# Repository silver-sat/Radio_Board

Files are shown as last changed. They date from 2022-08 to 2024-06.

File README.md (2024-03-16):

# Radio_Board
SilverSat Limited – https://silversat.org
SilverSat logo

Unassembled front radio board photograph
Radio board front view

**SilverSat is currently transistioning the repository to KiCad 8.0. These
updated files are incompatible with older versions.**

SilverSat's Radio Board is our custom-designed Arduino®-compatible prototype
satellite data transceiver and internet gateway for 430-450 MHz.

This repository contains the board design in KiCad 6.0 with relevant design
files and images.

# Setup
1. If you haven't already done so, download and install KiCad 6.0 from their
website, https://www.kicad.org/download/. Depending on your system and Internet
connection, than may take several hours.
2. On the top right of the repsitory's main page, click “Code” to select
download options. On all operating systems, you can download and extract a ZIP
archive to your perrfered folder. Alternatively, you can use one of the many
free Git access programs available from the Internet. Here are instructions for
a few common programs.
   * On Windows and Mac, you can download and install GitHub Desktop
   (https://desktop.github.com/) to access and manage Git repositories. See
   https://docs.github.com/en/desktop/contributing-and-collaborating-using-github-desktop/adding-and-cloning-repositories/cloning-a-repository-from-github-to-github-des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 for details.
   * There are also many command line interfaces available. For example, GitHub
    offers `gh` which can be downloaded from their repository
    (https://github.com/cli/cli). Once you install the client, navigate to your
    perferred folder and run the command given by our repository's Code tab.
   * On Unix and Linux, many software repositories offer `git` as an
   alternative to `gh`. You can download and install `git` from your package
   manager.
     - Debian-based Linux: `sudo apt install git`
     - RedHat Linux or derivatives: `sudo yum install git`
     - macOS (using [Homebrew](https://github.com/Homebrew/brew)):
     `brew install git`
   * For other programs, see their associated documentation for directions.
3. Download and install SilverSat's KiCad Library
(https://github.com/silver-sat/kicad_library). Installation instructions are
given on the library's README.md.
   - It is possible to skip this step, but some parts (such as the TCXO) may
   fail to load.¹
5. Enter the project folder and open SilverSat_Comms.kicad_pro. KiCad will show
 options to edit the schematic or PCB.

# Software
See SilverSat's Radio Software repository
(https://github.com/silver-sat/Radio_Software)

## Known Issues
- KiCad 6, required by our project, is not supported on Windows 7 or earlier
releases. We have not yet tested Windows 8.
- It is possible that Windows users of KiCad versions 6.0.0 to 6.0.4 may
experience issues with sudden component changes using using the Edit Schematic
Fields tool.
- When adding, removing, or moving components in the schematic, importing the
changes into the PCB may cause components to change places. Although they can
be moved back in place, it is easier to preserve annotations (or, if you add a
component, manually annnotate it).
- Due to the large size of this repository, it may download slowly depending on
your connection speed. On a 5 Mb/s connection, this time is approximately 13
minutes. To reduce download time, clone in headless mode `(git clone ... -d 1
...)`

# Warnings
This board was designed for the
[OshPark 4-Layer PCB Service](https://docs.oshpark.com/services/four-layer/).
Using another board type or service will require adjustments to the RF
amplifier lines and may require other appropriate compensations.

# Notes
¹ We have not yet tested whether this will work, but we presume based on past
experience that the resulting error can be ignored.

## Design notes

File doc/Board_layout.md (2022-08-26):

Radio Board Layout
---
SilverSat Ltd. (https://silversat.org)
2022-08-20

During the design process, the board was layed out in sections to ease part placement, and it could be referenced to during testing. In this document, we present the board sections and state their meanings.

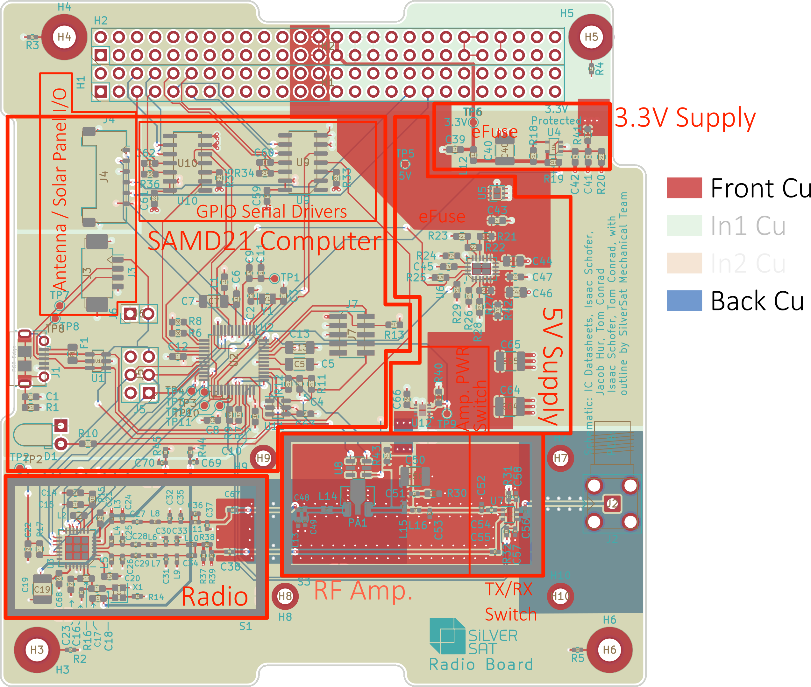
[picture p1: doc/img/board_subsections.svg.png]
Board sections diagram


_Figure 1: Board layout_

# SAMD21
The SAMD21 is an approximately 48 MHz SAMD21-based processor inspired by the [Adafruit Metro M0 Express](https://www.adafruit.com/product/3505). It is compatible with the Metro and the Arduino Zero with modified serial pin definitions (TBD: Add).
## Pinouts

### H1 & H2
See New Pin Assignments.pdf

### J1
USB Mini B (limited to 0.3 A)

### J3
Modified USB (for solar panel data as a backup for other boards)

### J4
[Endurosat Antenna Board](https://www.endurosat.com/cubesat-store/cubesat-antennas/uhf-antenna/) data connector

### J5
| AX5043 SPI MISO  | 3.3 V |
| --- |--- |
| AX5043 SPI SCK | AX5043 SPI MOSI  |
| RESET | GND |

### J6
|  GND  | RESET |
| ----- | ----- |

### J7 (SWD Header)
| 3.3 V | RX LED SWDIO |
| --- | --- |
| GND | SWCLK |
| GND | NC |
| NC | NC |
| NC | RESET |

### Test Points
| ◉ TP3 | ◉ TP4 | ◉ TP10 | ◉ TP11 |
| --- | --- | --- | --- |
| AX5043 SPI DATA | AX5043 SPI DCLK | TxD2 | RxD2 |

# Radio
The radio is a clone of the OnSemi ADD5043-433-GEVK (./Datasheets/ADD5043-433-2-GEVK SCHEMATIC.PDF) AX5043 test board schematic, placed in a two-piece RF shield. See img/ for chip selection.

## Attenuator
The receive line (closest to the SAMD21) has a pi-attenuator network near the exposed ground test point. The BOM includes parts for 0 dB attenuation, but other values can be calculated using KiCad's PCB Calculator. Common values are also given in the schematic.

# Power Amplifier & TX/RX Switch
This circuit, based on a HMC452ST89, increases the transmit power from the radio from 16 dBm to 30 dBm.

To allow one connector to serve as transmit and receive, an TX/RX switch has been included.

# Serial Drivers
Converts differential serial lines from Avionics and Payload to UART for the SAMD21.

# Power Supplies
The board includes two power supplies (5V and 3.3V) which take DC power from SilverSat's Power board and applies latch-up protection and e-fuses.
## 5V
The five volt supply is almost entirely contained on the top layer, and powers the RF amplifier. In addition to the above, it includes and electronic power switch to power off the amplifier when it is not in use.

## 3.3V
The output connects to a power plane on the In_2 copper layer, powering the SAMD21, ADD5043 and TX/RX switch.

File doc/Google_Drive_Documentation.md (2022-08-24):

# Preliminary Design on Google® Drive

All preliminary design files for the AX5043 are available on SilverSat's Google Drive at the following link. It also includes related ground station design.

https://drive.google.com/drive/folders/1SJQHO7lgZGwX5b4s1ShD_AfbKK2ey7EL?usp=sharing

In addition, SilverSat has published one of its early KISS over AX.25 transceivers for Arduino Megas and HopeRF RFM69s on it own GitHub repository.

https://github.com/silver-sat/ipoverradio

<sub>*"Google" is a registered trademark of Google, Inc., Mountain View, California, United States, a subsidiary of Alphabet, Inc.*</sub>

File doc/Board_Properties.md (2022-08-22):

![Figure 1: A diagram of the board properties. Board Dimensions: 90.1700 by 95.8850 millimeters. Thickness: 69.68 mils, 1.770 millimeters. Board Characteristics. Copper Layer Count: 4. Min track/spacing: 5 mils, 0.1270 millimeters. Copper Finish: E N I G. Casellated pads: No. Edge card connectors: No. Min hole diameter: 10.00 mils, 0.2540 millimeters. Impedance Control: No. Plated Board Edge: No. Board Materials: See OshPark 4-Layer Board Service datasheet (https://docs.oshpark.com/services/four-layer/)](./img/SilverSat_Comms-User_Drawings.svg.png)

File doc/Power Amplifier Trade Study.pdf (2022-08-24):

6

| Output power (dBm) | Supply Voltage | Supply current | Package | Cost/ availability | Evaluation board | Efficiency
HMC452ST89 from Analog Devices | 31 | 5 | 510 | SOT-89 | 15.22$ on analog website, in stock | Yes, but unavailable on DigiKey | 1.25/2.55 49.7%
MMZ09332B from NXP | 32.8 | 5 | 110 mA | QFN 12 pin 3mm | In stock, 8.63 on mouser | Couldn’t find | Datasheet says “45.5 @ 5 V 53.7 @ 3.6 V”
TQP7M9105 from Qorvo | 30 | 5 | 450 mA | SOT-89 | 12.85, 1 in stock on Qorvo website, 1 on RFMW.com | Yes | 44.444...%

efficiency =

10

−3
10

dBm
10

( ( ))

V
in

I
in

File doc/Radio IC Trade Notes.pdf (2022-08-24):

Figures of Merit

Radio IC | Well-Supported API | MTU Size | Support VHF and UHF Bands Path for Beacon | Available Now Test Boards Available | Heritage | Separate Tx Out Pin Switch Control Sensitivity | Green cells | Yellow cells | Red cells
Requirement/Criteria -> | | 255/256 preferred | 145.8 to 146 MHz, 432.125 to
| | | 433 MHz, and 435 to 438 MHz
| | | coverage | Some means to approximate CW | Yes | Yes

Not sure why this is
a requirement, just
need the control line
and 2 switches - tkc Yes

(looking −100dBm @ 10⁻³
BER, 9600 baud)
RFM22 | Supported by Radiohead | 64 bytes / Direct Mode | 240-930 MHz | CW Support in Direct Mode | No | No
| | | | | | $50Sat (?) and T-LogoQube (?) | Yes on base IC Yes on base IC | See graph on page 26 of datasheet 4 2 3
Supports OOK; modulation of packet length to create CW Supports OOK; modulation of packet length to create CW Supports OOK; modulation of packet length to create CW | SX1231HIMLT RT has 18,890 in stock at DigiKey As of 2021-12-29 21:06 UTC, there were 4,000 available on DigiKey. | Yes, but they are out of stock on DigiKey. We do have RFM69s, but the chips on those are labeled “RF69” so I MinXSS (https://earth.esa. cannot confirm that they int/web/eoportal/satellite-are SX1231 boards. missions/m/minxss) | No | Yes | −112.7143 dBm linearly interpolated,unspecified BER or PER, 9600 baud 3 4 2
2 generic boards in stock at SilverSat Limited | Likely no satellite heritage, but it is recommended by a master's thesis https: //oaktrust.library.tamu. edu/bitstream/handle/1969. 1/ETD-TAMU-2011-12-10387/GRAVES-THESIS.pdf | No | Yes [1] | Multiple receiver modes available; see page 8 of data sheet 3 3 3
As of 2021-12-29 20:28 UTC, there were 211 available on DigiKey. This product is discontinued, but parts are available | 2 generic boards in stock at SilverSat Limited | Likely no satellite heritage, but it is recommended by a master's thesis https: //oaktrust.library.tamu. edu/bitstream/handle/1969. 1/ETD-TAMU-2011-12-10387/GRAVES-THESIS.pdf | No | “Positive” and “Negative” output from LNA | Multiple receiver modes available; see page 8 of data sheet 2 4 3
AX5043 | Official API for AX852, portable to Arduino | As of 2021-12-19 22:15 UTC, there were “Wire mode” available; MCW may 5,920 available In stock at SilverSat 256 bytes, more with options 27MHz ~ 1.05GHz be possible in FM mode at DigiKey Limited | Oresat | Yes Yes | −117 at h = 0.66 to −113 dBm at h = 8, 10 kbaud, FSK, 10⁻³ BER, no FEC, 433 or 868 MHz 6 2 1
AX5243 | In-development https://github.com/jgromes/RadioLib | As of 2021-12-19 22:15 UTC, there were 40,880 “Wire mode” available; MCW may available at 256 bytes, more with options 27MHz ~ 1.05GHz be possible in FM mode DigiKey | Yes, but it is not in stock Seems to be similar to at DigiKey AX5043, used on Oresat | No No | −117 at h = 0.66 to −113 dBm at h = 8, 10 kbaud, FSK, 10⁻³ BER, no FEC, 433 or 868 MHz 5 4 0
SX1276IMLTRT; SX1277IMLTRT; SX1278IMLTRT; SX1279IMLTRT AX8052F143 AX5045-1-TW30 SX1236IMLTRT | True. https://github.com/jgromes/RadioLib and https://github.com/StuartsProjects/SX12XX-LoRa | 64 bytes | DigiKey has 5,983 of SX1279IMLTRT on 2021-12-30 137MHz ~ 1.02GHz Modulating packet length MCW 01:27 UTC | No None | Yes Yes | 6 2 2
No No | 256 bytes, more with options 27MHz ~ 1.05GHz 256 bytes, more with options 60MHz ~ 1.05GHz | Raw mode? Can modulate packet length Raw mode? Can modulate packet length | 4,160 In Stock on DigiKey As of 2021-12-30 02:01 UTC, there were 2988 available on DigiKey. | Available at 868 MHz on DigiKey, sale of 70 cm band boards is unknown None Yes, but at 815 MHz with limited supply None | Unclear; Unclear; possibly possibly through GPIO through GPIO | 3 3 3
| | | | | Separate Separate differential differential dual dual TX/RX pins TX/RX pins | 5 1 3
Supported by https://github.com/StuartsProjects/SX12XX-LoRa | 64 bytes | As of 2021-12-30 15:17 UTC, there were 2,844 available 137MHz ~ 1.02GHz Modulating packet length MCW on DigiKey. | No None | Different TX and RX pins Yes | 6 1 2
ADF7020-1BCPZ-RLTR-ND | Not for Arduino. https://forum.arduino.cc/t/low-power-rf-transceiver-433mhz-13dbm/384396 There may be an official library for C on the Buffer exists for some modulation Analog Devices product page. types, but size is not specified. | 80MHz ~ 650MHz | Supports OOK; modulation of packet length to create CW; and possible default direct mode depending on modulation | As of 2021-12-30 15:40 UTC, there were 1,972 available on DigiKey. | MCubed-2 / COVE https: //directory.eoportal. Yes, but it is not in stock org/web/eoportal/satellite-at DigiKey. All generic missions/content/-ADF7020 /article/mcubed-2-mission | Yes | No | 4 3 2

SX1231

Supported by https://github.com/jgromes/RadioLib and
https://github.
com/StuartsProjects/SX12XX-LoRa

66 bytes, option for unlimited
packet length (possible “direct
mode”) | VHF to 290 MHz

Texas Insturments
CC1101TRHBRG4Q1

True. https://github.
com/pkarsy/CC1101_RF | 64 bytes

310MHz ~ 348MHz, 420MHz ~
450MHz, 779MHz ~ 928MHz

Texas Insturments
CC1101QRHBRG4Q1

True. https://github.
com/pkarsy/CC1101_RF | 64 bytes

310MHz ~ 348MHz, 420MHz ~
450MHz, 779MHz ~ 928MHz

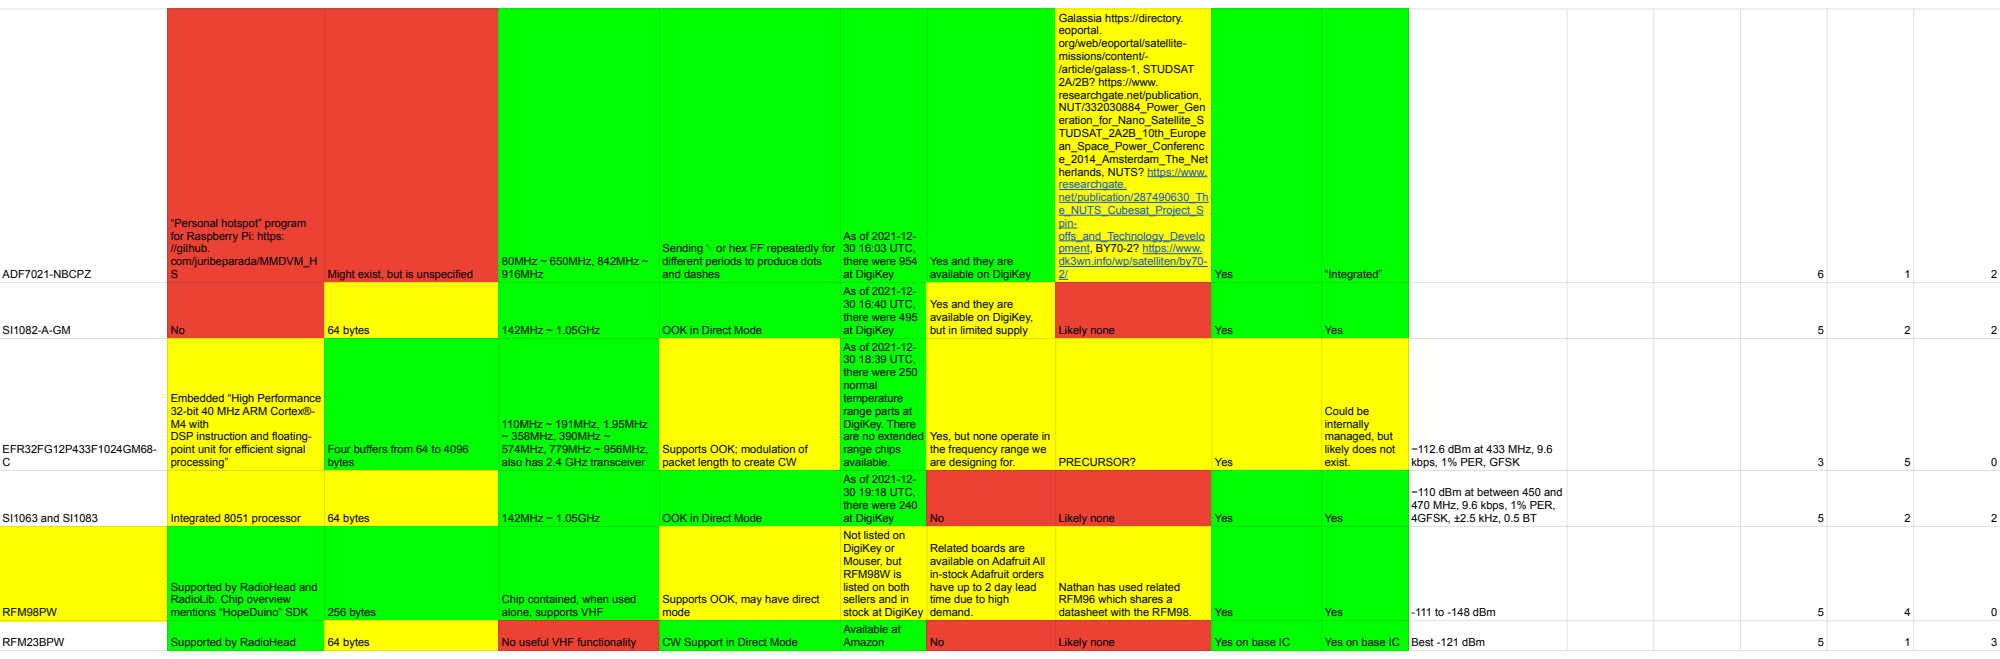
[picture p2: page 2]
ADF7021-NBCPZ; com/juribeparada/MMDVM_H S; Might exist, but is unspecified; 80MHz ~ 650MHz, 842MHz ~ 916MHz; As of 2021-12- 30 16:03 UTC, there were 954 at DigiKey; Yes; “Integrated”; 64 bytes; 142MHz ~ 1.05GHz; OOK in Direct Mode; As of 2021-12- 30 16:40 UTC, there were 495 at DigiKey; but in limited supply; Likely none

Galassia https://directory.
eoportal.
org/web/eoportal/satellite-
missions/content/-
/article/galass-1, STUDSAT
2A/2B? https://www.
researchgate.net/publication,
NUT/332030884_Power_Gen
eration_for_Nano_Satellite_S
TUDSAT_2A2B_10th_Europe
an_Space_Power_Conferenc
e_2014_Amsterdam_The_Net
herlands, NUTS? https://www.
researchgate.
net/publication/287490630_Th
e_NUTS_Cubesat_Project_S
pin-
offs_and_Technology_Develo
pment, BY70-2? https://www.
dk3wn.info/wp/satelliten/by70-

“Personal hotspot” program
for Raspberry Pi: https:
//github.

Sending
different periods to produce dots
and dashes

␀ or hex FF repeatedly for

Yes and they are
available on DigiKey

available on DigiKey,

EFR32FG12P433F1024GM68- C | Embedded “High Performance 32-bit 40 MHz ARM Cortex®-M4 with DSP instruction and floating-point unit for efficient signal processing” | 110MHz ~ 191MHz, 1.95MHz ~ 358MHz, 390MHz ~ Four buffers from 64 to 4096 574MHz, 779MHz ~ 956MHz, bytes also has 2.4 GHz transceiver | Supports OOK; modulation of packet length to create CW | As of 2021-12-30 18:39 UTC, there were 250 normal temperature range parts at DigiKey. There are no extended range chips available. | Could be internally Yes, but none operate in managed, but the frequency range we likely does not are designing for. PRECURSOR? Yes exist. | −112.6 dBm at 433 MHz, 9.6 kbps, 1% PER, GFSK 3 5 0

SI1063 and SI1083 | Integrated 8051 processor 64 bytes | As of 2021-12-30 19:18 UTC, there were 240 142MHz ~ 1.05GHz OOK in Direct Mode at DigiKey | No Likely none | Yes | −110 dBm at between 450 and 470 MHz, 9.6 kbps, 1% PER, 4GFSK, ±2.5 kHz, 0.5 BT 5 2 2

RFM98PW | Supported by RadioHead and RadioLib. Chip overview Chip contained, when used mentions “HopeDuino” SDK 256 bytes alone, supports VHF | Not listed on DigiKey or Related boards are Mouser, but available on Adafruit All in-stock Adafruit orders RFM98W is listed on both have up to 2 day lead Nathan has used related Supports OOK, may have direct sellers and in time due to high RFM96 which shares a mode stock at DigiKey demand. datasheet with the RFM98. | Yes | -111 to -148 dBm 5 4 0

RFM23BPW | Supported by RadioHead | 64 bytes | No useful VHF functionality | Available at CW Support in Direct Mode Amazon | No Likely none | Yes on base IC | Best -121 dBm 5 1 3

[1] There's actually a way to program the registers to get a switch control on GDOx. There's also a companion chip for it the CC1190 (but wrong frequency band) that adds PA & LNA

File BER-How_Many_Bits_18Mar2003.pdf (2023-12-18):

BIT ERROR RATIO TESTING:
HOW MANY BITS ARE ENOUGH?

Andy Baldman
UNH InterOperability Lab
March 18, 2003

Abstract:

The purpose of this article is to discuss the concept of Bit Error Ratio testing, and will explain, using a minimum amount of math, the answer to a fairly common question:

“How many bits do I need to send in order to verify that a device exceeds a given BER?”
The analysis will provide the same answer as the more formal approach¹
, which
employs the statistical concepts of Confidence Intervals and Hypothesis Testing, however this analysis is designed to provide an intuitive, easy-to-understand explanation that does not require the reader to have any prior knowledge of statistics or probability.

Introduction:

The concept of the Bit Error Ratio (BER²
) is ubiquitous in the communications industry. It is commonly used as the fundamental measure of performance for digital communication systems. The BER can be thought of as the average number of errors that would occur in a sequence of n bits. Consequently, when n is equal to 1, we can think of the BER as the probability that any given bit will be received in error. Formally, the BER is expressed in terms of the following ratio:

1 error
n bits transmitted

So, if a device’s specified BER is 1/n, we can expect to see, on average, 1 bit error for every n bits sent. The fact that the BER is defined as an average quantity is an important fact, for reasons that will soon become apparent.

While the definition of BER may be fairly straightforward, verifying that a device meets or exceeds a certain BER is not as simple. If a device’s BER claims to be 1/n, and we send n bits and see one error, can we say that the BER is 1/n? What happens if we see no errors? What if there are multiple errors? What if we see a different number of errors each time we repeat the test? Is there anything that we can say for certain?

Well, the answer is… maybe. It depends on the circumstances. To begin with, let’s start with what we do know: If at least one error is seen, we can say with 100 percent certainty that the BER is definitely not zero. Also, as long as at least one bit was successfully received, we can additionally state that the BER is most definitely less than
1. We’ve already narrowed it down to somewhere between 0 and 1! How difficult can this be, right?

Obviously, while these observations are technically correct, they really don’t help us that much. We need a better way of analyzing this problem, so we’ll do what all good engineers and scientists do: we’ll make a model of the system, and try to infer answers from the model, based on the characteristics of the model and the assumptions we make about its behavior.

Before we do that though, allow me to make one statement, (which happens to be correct, as we will see by the end of this article.)

“In reality, if a device’s BER is 1/n and n bits are sent, we can actually expect to see 0 errors during those n bits approximately 35 percent of the time.”

“35 percent? Are you crazy? That makes no sense!”, I hear you cry.

Yes, it sounds odd. However, it’s actually not that difficult to understand why this is the case, and to see where this number comes from. To do this however, we’ll need to explain a couple of basic concepts from the study of Probability. Don’t panic, it’s nothing complicated. In fact it’s as simple as flipping a coin…

Bernoulli Trials: Heads or Tails?

If you flip a coin, everyone knows the probability of getting either heads or tails is 50/50 (as long as the coin isn’t rigged in some way, of course.) However, it wouldn’t be terribly shocking to flip a coin 3 times and get 3 heads or 3 tails in a row. Even though the chance of getting heads for any particular flip is 50%, it is entirely possible to get any number of heads or tails for any given number of consecutive flips. Although these events are less likely to happen than usual, they do happen, and it’s not too hard to say something about how often they happen, using some basic assumptions.

In the study of Probability, one of the simplest and most important concepts is known as the “Bernoulli Trial”. Basically, this is just a fancy term to describe flipping a coin. In general, a “Bernoulli Process” is comprised of a series of Bernoulli Trials, where the trials are described by the following 3 characteristics:

1) Each “trial” has two possible outcomes, generically called success and failure.
2) The trials are independent. Intuitively, this means that the outcome of one trial has no influence over the outcome of any other trial.
3) For each trial, the probability of success (however it may be defined) is p, where p is some value between 0 and 1. The probability of a failure (defined as the only other alternative outcome to success) is 1-p.

That being said, let’s go back to coin flipping. Although a normal coin may have a 50/50 chance of landing heads up for any given flip (technically called a fair coin), we know that it’s fairly easy to flip a coin twice and get 2 heads, or 3 times and get 3 heads. In reality, for the case of three flips, we see that there are only 8 possible combinations that can occur (H = heads, T = tails):

H-H-H
H-H-T
H-T-H
H-T-T
T-H-H
T-H-T
T-T-H
T-T-T

Because there are only 8 possible outcomes, and the chances of getting a head are the same as getting a tail, then the chances of any one specific combination of outcomes occurring is always 1 in 8, or .125. Note that we can also get this value using the probability for each coin flip. If the probability of getting one head is .5, then the probability of getting 3 heads in a row is just:

.5 *.5 * .5 = .125 (or 1/8)

Again, because the chances of getting a head are the same as getting a tail, the probability of any particular one of the eight combinations above is always just .5*.5*.5 = .125.

“But how can they all be the same? Shouldn’t the chances of getting all heads be smaller?”

Yes, and it is, which is easier to see if we look at the list of the 8 possible outcomes in a different way. If I ask the question, “What are the chances of getting all heads for three consecutive flips?” there is only one way to do it, and so the answer is 1/8. However, if I change the wording of the question to ask, “What are the chances of getting only one head in three flips?” we see that the answer is now 3/8. This is because here (unlike the all-heads case) there are now three different ways of getting what we want (HTT, THT, TTH) and each one has a 1 in 8 chance of occurring. Thus, we can add the probabilities together. To better see why the probabilities add, just look at the table of the 8 possible outcomes for 3 flips. The chances of getting only one head makes up three of the eight total combinations, thus you’re three times more likely to get one of those combinations than you are to get the single case of all three heads.

Note that we can ask other questions here, too. I could word the question to ask, “What is the probability of getting up to 2 heads?” In this case, we need to find the sum of the following:

| Possible | Total
Condition | Outcomes | Probability
The probability of getting 0 heads: TTT | = 1/8
plus, The probability of getting 1 head: | HTT, THT, TTH | = 3/8
plus, The probability of getting 2 heads: HHT, HTH, THH | = 3/8
| | 7/8

Observe that in order to get this result, we had to find the sum of the probabilities for 7 out of the 8 possible outcomes. Since for any experiment, the sum for all of the total possible outcomes must always add up to 1, in this case we also could have found the answer by computing 1 minus the probability of not getting up to 2 heads, which is simply 1 minus the probability of getting all three tails, which is 1 - 1/8 = 7/8. Simple!

“OK, so what does all of this have to do with BER testing?”

We can use this same basic coin-flipping model to describe our process of sending and receiving bits, with a few minor tweaks. First, we have to realize that we will no longer have a fair coin. If we equate a “tail” with a bit error, then we now have a coin that flips heads almost all of the time, and which flips tails according to the BER (say 1 tail in 100 flips for a BER of 1E-2 for example.) The other thing to realize is that the math gets a little more complicated. To see why, suppose I ask the question, “What is the total probability of getting exactly 3 tails in 100 flips?” To find this probability, one of the things we need to know is the number of ways we can get 3 tails in 100 flips, e.g.,

TTT + 97 Heads
THTT + 96 Heads
TTHT + 96 Heads
HTTT + 96 Heads
HHTTT + 95 Heads
Etc…

It doesn’t take long to see that the number of combinations quickly gets far too cumbersome to determine by hand. Have no fear, though, since there exists an easy formula that can provide the value much easier.

ENTER THE BINOMIAL COEFFICIENT!

Without getting into the history of it, someone along the way figured out a handy little formula that tells you the total possible number of combinations that k specific outcomes can occur out of a total of n trials. It is sometimes referred to as “n-choose-k”, and is technically called the Binomial Coefficient. The formula is as follows:

n!
C(n,k) = | -------------- | [EQ. 1]
| k! * (n-k)!

Plugging in some real values to this formula, if we want to know the number of combinations for getting 2 heads in a total of 3 flips, we get:

3! | 6
------------ = --------- = 3 possible ways. (HHT, THH, and HTH)
2! * (3-2)! 2 * 1

Similarly, for 2 heads in 4 flips, we get:

4! | 24
------------ = --------- = 6 possible ways. (HHTT, TTHH, THTH,
2! * (4-2)! | 2 * 2 | HTHT, THHT, HTTH)

We can easily see the power of this formula, as it allows us to quickly find the number of combinations for examples that would be far too complicated to figure out by hand. For example, take 12 heads in 50 flips:

50!
------------------- = 121,399,651,100 possible combinations!
12! * (50-12)!

Granted, there is still a problem with trying to figure out the value of 50! by hand, however we can easily do this with a computer. (Note that in MATLAB, you can also use the ‘nchoosek’ function to compute the Binomial Coefficient directly.)

Armed with the power of the Binomial Coefficient, we now have everything we need to create our analytical model of BER testing.

A Simple BER Model:

We are now ready to study this problem in depth. First, let’s take a look back at the bold statement that was made a while back about the 35% probability of seeing zero errors when the BER is 1/n, and n bits are sent.

Expanding on our coin-flipping example, if we were to say that we now have a coin that flips tails only 10% of the time (instead of the normal 50%), we can begin to create our model. From this, we can directly compute the probability of getting zero tails (i.e., getting ten heads) in 10 consecutive flips. This would then be:

P(no tails) = (# of ways to get 10 heads) x P(10 heads)

= | 1 | x [P(1 head)] ¹⁰

(Note that I have begun to use the notation “P(1 head)”, which is just shorthand for saying, “The probability of getting 1 head.” We will continue to use this notation for the remainder of this discussion.)

Note that this is just one specific example of a much more general case. In general, we can write the formula for finding the probability of getting any k number of tails out of n total flips as the following:

| | Ptot = C(n,k) * [p k
* (1-p)
(n-k)] | [EQ. 2]

“Whoa. What the heck is that? You said this wouldn’t be difficult.”

Hang on a minute. It’s not as bad as it looks. First, let’s look at the part inside the brackets. When we say we want the probability of getting exactly 1 tail in 10 flips, what we are actually saying is that we want the probability of getting 1 tail, and nine heads. This is what the bracketed expression represents. If we want k tails, we imply that the remaining number of flips (n-k) must be heads. When figuring in these heads we must account for the probability of getting a head, however recall that P(head) is actually just 1-P(tail).

As an example, take two tails in ten flips, where P(tail) = .1:

[p

k
* (1-p)
| | (n-k)] = (P(tail))
| | 2 * (P(head))

8

= (.1)²

* (.9)⁸

= .0043

Now, realize that this number only represents the probability for one way of getting 2 tails in 10 flips. The other part of EQ 2 above, (the C(n,k) part) is the Binomial Coefficient, the part that tells you the total number of possible combinations by which you can get 2 tails out of 10 total flips. Multiplying the .0043 result from above by the proper Binomial Coefficient will give you the total probability of getting two tails in ten flips for P(tail) = 1/10 :

| | Ptot = C(n,k) * [p k
* (1-p)
| | (n-k)]

= C(10, 2) * [.1²

* .9⁸
]

= 45 * [.0043]

= .1937

So, this means that if P(tail) is 1/10, then for ten flips, you will have a 19.37% chance of getting exactly two tails. Pretty neat, huh?

OK, so let’s do more with this. What then, would be the probability of getting just one tail in ten flips? Let’s see:

Ptot = C(n,k) * [p

k
* (1-p)

(n-k)]

= C(10, 1) * [.1¹

* .9⁹
]

= 10 * [.03874]

= .3874

We see that the result is higher than before, in that for P(tail) = 1/10, we’re 38.74% likely to see 1 tail in 10 flips, compared to the 19.37% chance we have of seeing 2 tails. (But it makes sense that we’d expect to see 1 tail more often than 2, since our coin has a known P(tail) equal to 1/10, right? Right…)

Even more interesting is the case for 0 tails (i.e., 10 heads):

Ptot = C(n,k) * [p

k
* (1-p)

(n-k)]

= C(10, 0) * [.1⁰

* .9¹⁰]

= 1 * [.3487]

= .3487

So, if P(tail) is 1/10, and I perform 10 flips, then there’s an approximately 35% chance that I will see zero heads in those 10 flips. Amazing! It almost seems counter-intuitive, but the math spells it out pretty clearly. Note that seeing 0 tails is still slightly less likely to occur than seeing 1 tail (34.8% for 0 tails, vs. 38.7% for 1 tail), although they’re pretty close.

Since we’ve now calculated the probabilities of getting 0, 1, or 2 tails in 10 flips, we can now write a little program to go and calculate the probabilities for all the possible number of tails we could possibly see for 10 total flips (up to a maximum of 10, of course.) (Note that the MATLAB code to do this will be included at the end of this article.) Here’s what the plot looks like for all possible numbers of tails given 10 total flips:

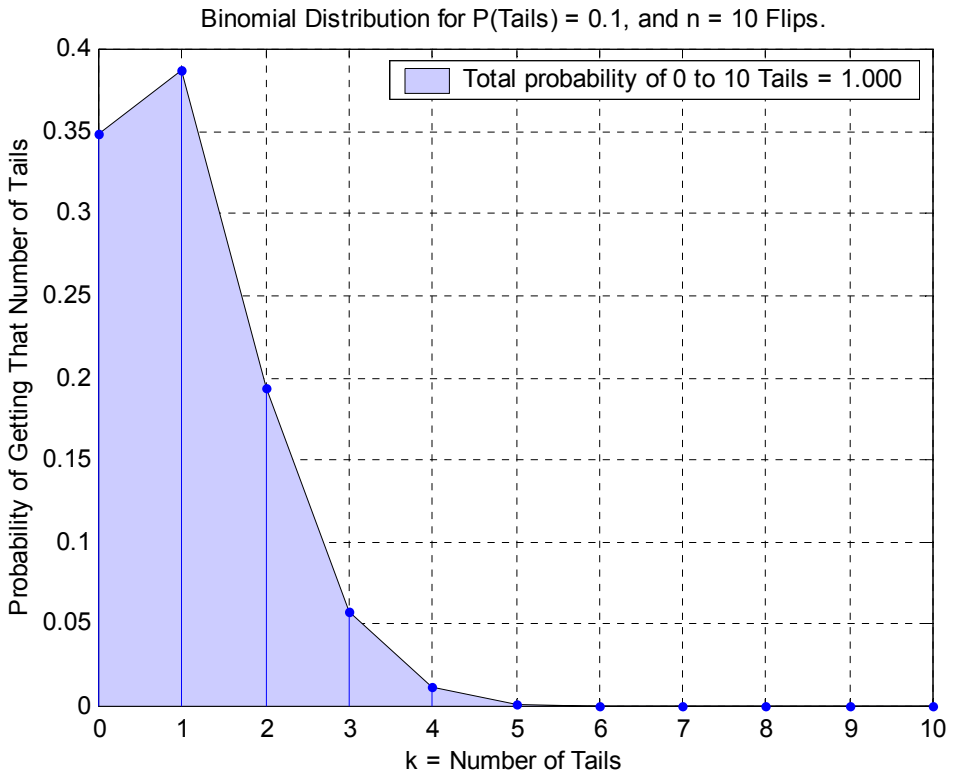
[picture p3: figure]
k = Number of Tails

Probability of Getting That Number of Tails

Binomial Distribution for P(Tails) = 0.1, and n = 10 Flips.

Total probability of 0 to 10 Tails = 1.000

Note that in the plot above, the stem plot represents the discrete values 0 through 10, for which the probabilities were calculated. (The shaded region is only shown to highlight the overall shape of the plot.) Note also that the sum of the probabilities for 0-10 tails adds up to 1.000, as it should, since every time you do 10 flips, you must get some number of tails between 0 and 10 inclusive.

Now, let’s make things interesting. Let’s compute the distribution from 0 to 10 tails again, however this time let’s assume that P(tails) = 2/10, or twice what it was in the last example. Here’s what we get:

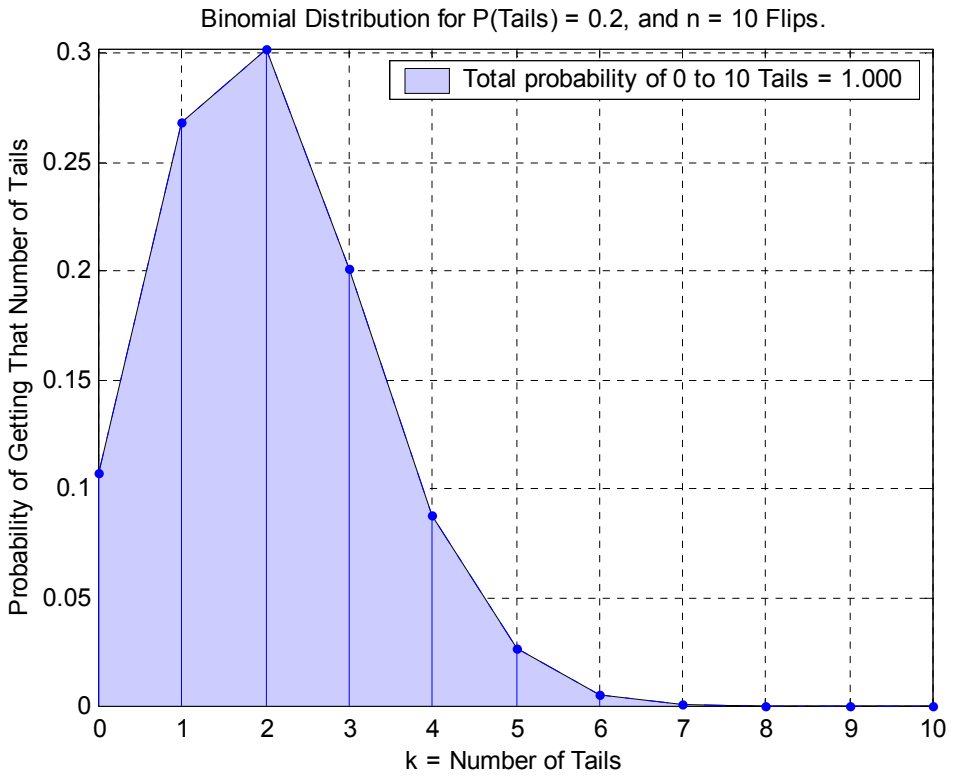
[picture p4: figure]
k = Number of Tails

Probability of Getting That Number of Tails

Binomial Distribution for P(Tails) = 0.2, and n = 10 Flips.

Total probability of 0 to 10 Tails = 1.000

Look closely. Even though P(tails) was 2/10, we see that approximately 10% of the time when we do the 10 flips, we will see zero tails. Also, approximately 27% of the time, we can expect to see just one tail. We’re still most likely to see 2 tails (again, because P(tails) is 2/10), however the chances of seeing 0 or 1 aren’t that far behind.

“OK, so why does all of this matter?”

The reason all of this matters goes back to the idea of BER testing. In this model, if we consider a “tail” to be a “bit error”, and replace “total number of flips” with “total number of bits sent”, then we have our simple BER model.

If we designed our BER test such that we attempt to verify that a particular device’s BER is equal to or better than 1/10 by sending 10 bits and allowing up to 1 error to occur (in order to be considered “passing”), then we run into the case whereby a device with a BER that is clearly sub-standard (2/10), could theoretically slip by, and actually PASS the test approximately 37% of the time! If we change the threshold and only allow

0 errors to be seen in order to pass, we still will have ‘bad’ devices slipping by and passing approximately 10% of the time.

Note that while this may seem like a good thing to the person who built the device, it is most certainly a bad thing from the perspective of the person trying to verify the actual BER. This type of error is what is known as a “Type II Error” in the formal terminology of Hypothesis Testing, whereby the device is given a passing result, even though it truly does have a failing BER. This is arguably worse than the opposite case (Can anyone guess what that might be called?) A Type I Error describes the opposite case, where the device actually does have a valid BER, however for that particular set of flips it just happened to get really unlucky and have multiple bit errors, thus causing it to fail.

To see the impact of a “Type II Error”, let’s go back to the original case where

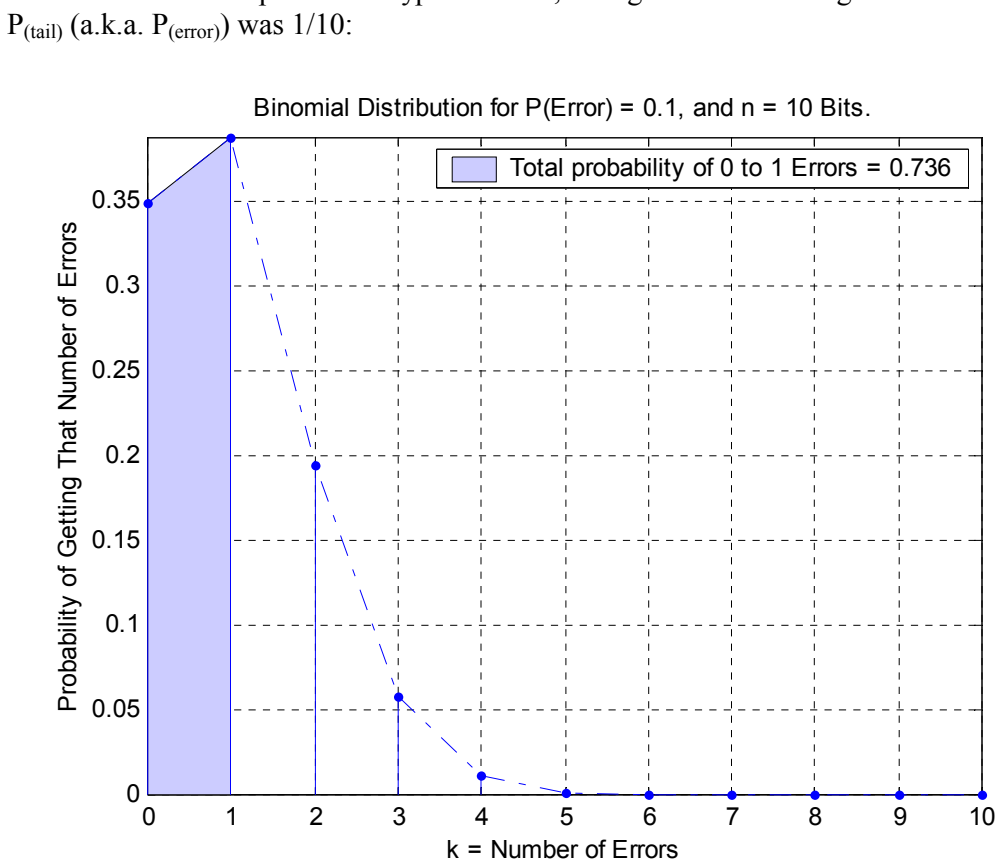
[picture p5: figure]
P(tail) (a.k.a. P(error)) was 1/10:; k = Number of Errors

Probability of Getting That Number of Errors

Binomial Distribution for P(Error) = 0.1, and n = 10 Bits.

Total probability of 0 to 1 Errors = 0.736

Here we see the same plot as before, however this time “total probability” only shows the sum of the first 2 values of k, up to and including 1 error (crudely approximated by the shaded “area under the curve”, however keep in mind that because the plot is a set of discrete values, the sum really is just the sum of the 0 and 1 error probabilities, and not a true area, as would be the case if the plot were continuous.) The point of showing the plot this way is that we now see that even though the BER is really

1/10, approximately (1 - .736) = 26.4% of the time, we will actually see 2 or more errors and erroneously assign a failing result, even though the device’s BER truly was conformant.

“OK, that all makes sense. So, how do we deal with this?”

Well, we do just about the only thing we can do - send more bits. However, it is important to realize the fact that as we send more and more bits, we are simultaneously increasing the overall chance that we will see bit errors. Thus, we may have to adjust the cutoff value for the number of errors that we will allow and still assign a passing result to the device being tested.

Let’s see what happens when we triple the number of bits we send:

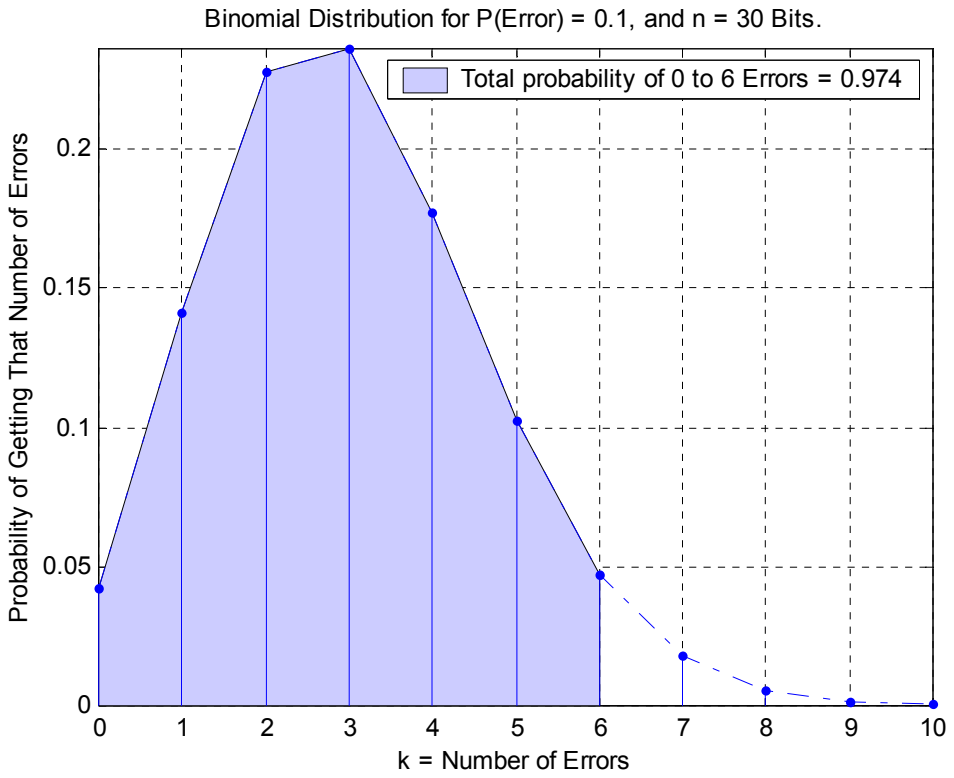
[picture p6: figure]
k = Number of Errors

Probability of Getting That Number of Errors

Binomial Distribution for P(Error) = 0.1, and n = 30 Bits.

Total probability of 0 to 6 Errors = 0.974

Here we see that when the BER is 1/10 and 30 bits are sent, we are most likely to see 3 errors (again, which makes sense, intuitively). More significant is the fact that 97.4% of the time, we should expect to see 6 errors or less. Also, perhaps the most important observation is that we can expect to see 0 errors less than 5% of the time. To see why this is meaningful, consider the following: Suppose that we are trying to verify that the BER of an actual device is 1/10 or better. If we send it 30 bits, and see zero errors, this means either one of two things is true:

1) The actual BER is equal to or worse than 1/10, and the device just got really lucky.
OR
2) The actual BER is better than 1/10.

For the same experiment, if 7 or more errors are seen, we can also come to one of two conclusions:

1) The actual BER is equal to or better than 1/10, but for this particular run, the device just was especially unlucky, and landed in the ~2.6% chance region of having 7 or more bit errors.

OR

2) The actual BER is worse than 1/10.

So what happens if we see 1 to 6 errors? Well, we can’t be sure exactly (at least not as sure as for the other two cases), however we can use our model to get an idea of where we lie. It is possible that a device could have a worse BER than what we’re testing for, and still produce 6 or fewer errors with a fair probability, however those chances drop off quickly. To see how this affects the error distribution, let’s see what the curve looks like if the actual BER is just one bit error worse (2/10), given the same number of bits sent: [n = 10;ber(2/n, 3*n, 10, 6);]

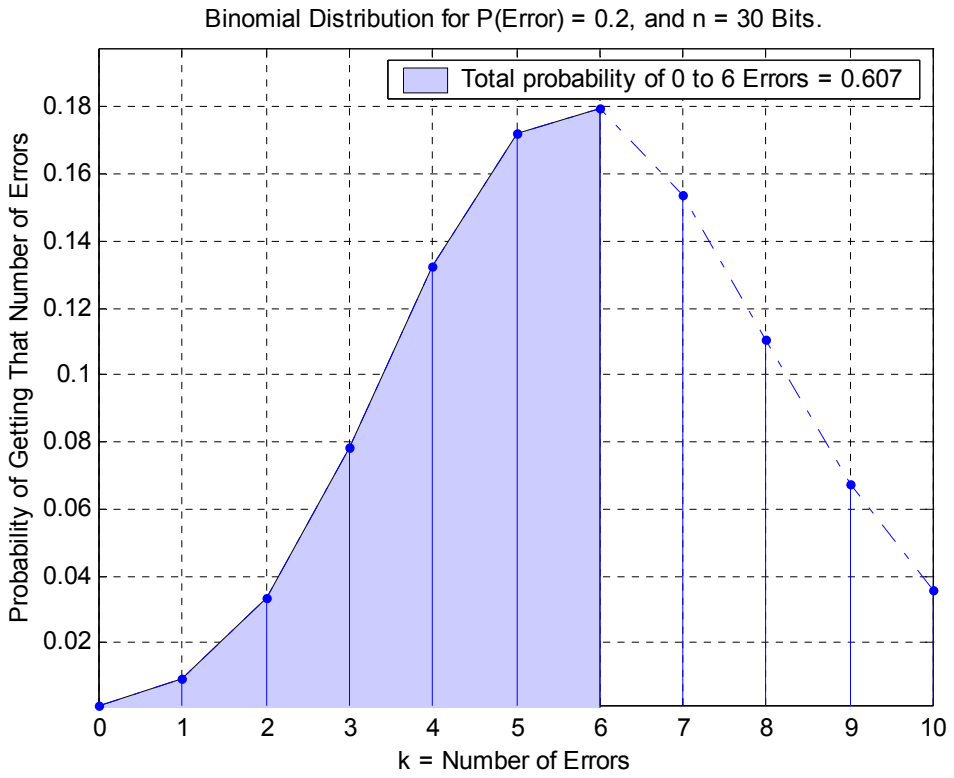
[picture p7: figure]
k = Number of Errors

Probability of Getting That Number of Errors

Binomial Distribution for P(Error) = 0.2, and n = 30 Bits.

Total probability of 0 to 6 Errors = 0.607

Here we see that the device has a 60.7% chance of producing 6 errors or less and ‘passing’ the test, even though the actual BER is failing. If we go just two bit errors further, (4/10), we get: [n = 10;ber(4/n, 3*n, 20, 6);]

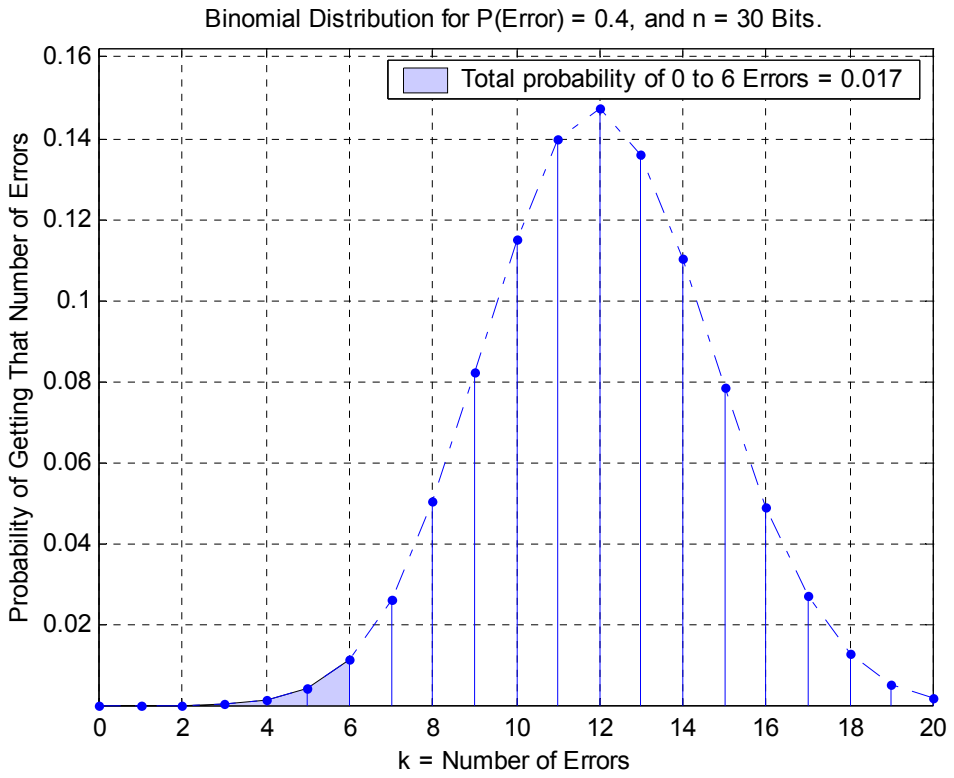
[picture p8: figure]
k = Number of Errors

Probability of Getting That Number of Errors

Binomial Distribution for P(Error) = 0.4, and n = 30 Bits.

Total probability of 0 to 6 Errors = 0.017

Now, we see that the chance of getting 6 errors or less also falls to about 2%. In general, we see that as the actual BER increases, the ‘peak’ of the distribution moves further and further to the right as a function of 3 times the actual BER. In other words, depending on whatever the actual BER is (in terms of errors per n bits), the peak of the distribution will be shifted further and further to the right by a factor of 3, because we are sending 3n bits. The larger the actual BER, the smaller the area under the tail will be, which represents the chances of getting up to 6 bit errors.

(Also note that as the actual BER gets worse, the chances of seeing 7 or more errors increases rapidly, strengthening our confidence in assigning a failing result to devices that show 7 or more errors.)

Thus, the question still remains as to how to interpret the results when 1 to 6 errors are observed. In actuality, this is exactly the same “Type II Error” situation as was seen before when we were sending only n bits (instead of 3n), and looking for the probability of seeing zero errors. Practically speaking, any test design we adopt will have a range in which the results will be effectively inconclusive. In these cases, as was the case for 0 errors, the only real solution is to design a more thorough test in which more bits are sent. In the absence of this option, the result basically comes down to semantics. Using a courtroom analogy, if the DUT is on trial as the defendant, we must ask the following:

1) Is it up to us (the prosecution) to prove “beyond a reasonable doubt” that the BER is failing?
OR
2) Is it up to the DUT, in its own defense, to prove that its BER is passing, with the same degree of confidence?

If the burden of proof lies with the person performing the test, then we have failed to produce conclusive proof “beyond a reasonable doubt” that the BER is failing (i.e., 7 errors or more), and thus must assign a passing result by default. Alternately, if the burden is shifted to the DUT, then any number of observed errors other than zero would be considered “reasonable doubt”, and would constitute a fail. In practice, the interpretation tends to favor the former scenario, whereby the DUT is “innocent until proven guilty” so to speak, and the burden of proof is placed on the tester to see 7 or more errors.

Note that for case where 1 to 6 errors are seen, the option also exists to make a statement to the effect that the device meets or exceeds a lower BER, with a higher degree of confidence. This is generally not desirable, since we are now interpreting the test based on the observed outcome (instead of the other way around), which defeats the purpose of the original test that was defined. In this case, we can view the test as effectively “sending more bits”, albeit relative to a lower target BER.

Validity of the Model: Scaling

All of the examples so far have used BER values of 1/n, 2/n, 3/n, etc., and trial lengths of n or 3n, where n was always equal to 10. This was done solely to keep things simple and intuitive. We have seen that we can design a BER test whereby if we want to verify a BER of 1/n, we send 3n bits, and interpret the results as follows:

1) 0 errors seen:
We are 95% sure that the actual BER is equal to or better than 1/n.
2) 7 or more errors seen:
We are 97% sure that the actual BER is worse than 1/n.
3) 1 to 6 errors seen:
Can’t say anything with high confidence, so the device passes by default.

The question then arises,

“Do these values still apply for cases when n is greater than 10?”

Well, the quick answer is basically, yes. Let’s see what happens to the numbers when we change n from 10 to 100:

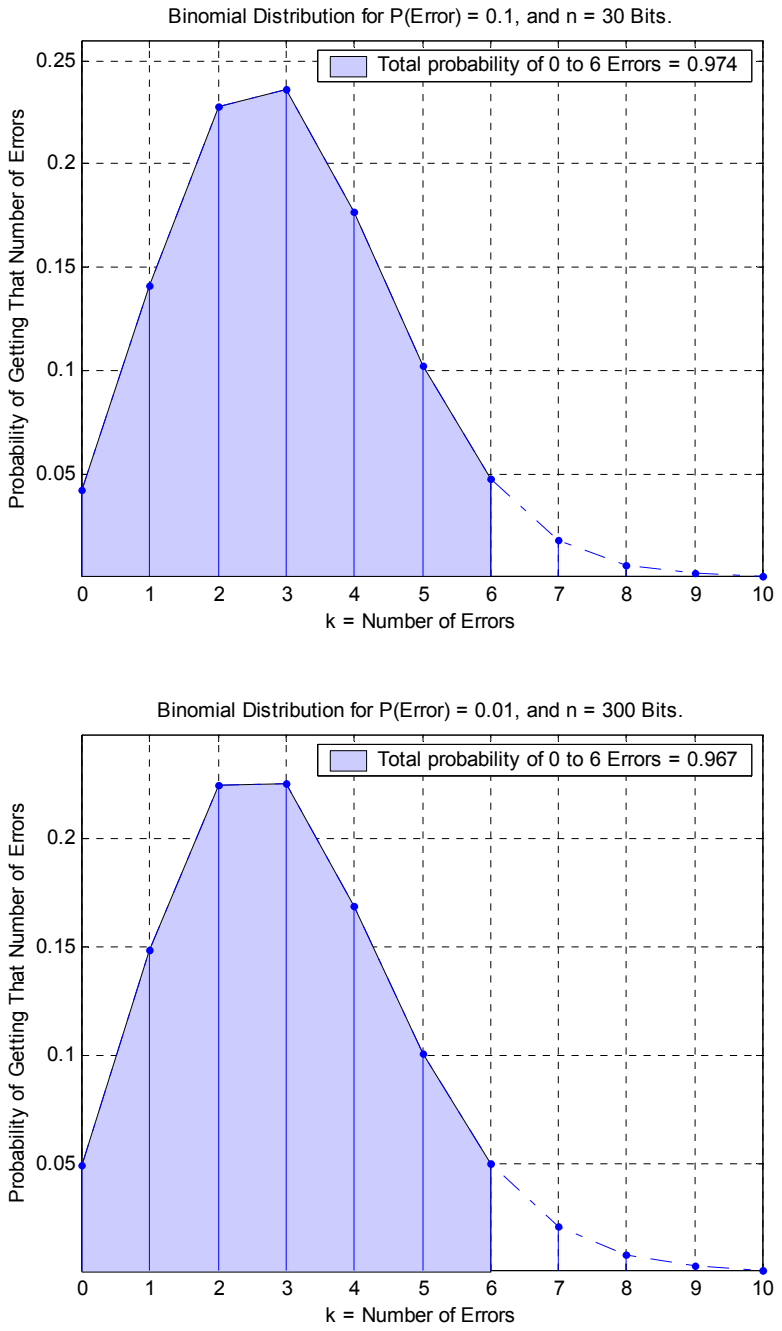
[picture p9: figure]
k = Number of Errors

Probability of Getting That Number of Errors

Binomial Distribution for P(Error) = 0.1, and n = 30 Bits.

Total probability of 0 to 6 Errors = 0.974

Probability of Getting That Number of Errors

Binomial Distribution for P(Error) = 0.01, and n = 300 Bits.

Total probability of 0 to 6 Errors = 0.967

We see that the total probability for up to 6 errors has decreased slightly, by less than 1%, while the probability of just 0 errors seems to have increased to almost exactly 5%. What happens when we try n = 1000? Here’s the plot:

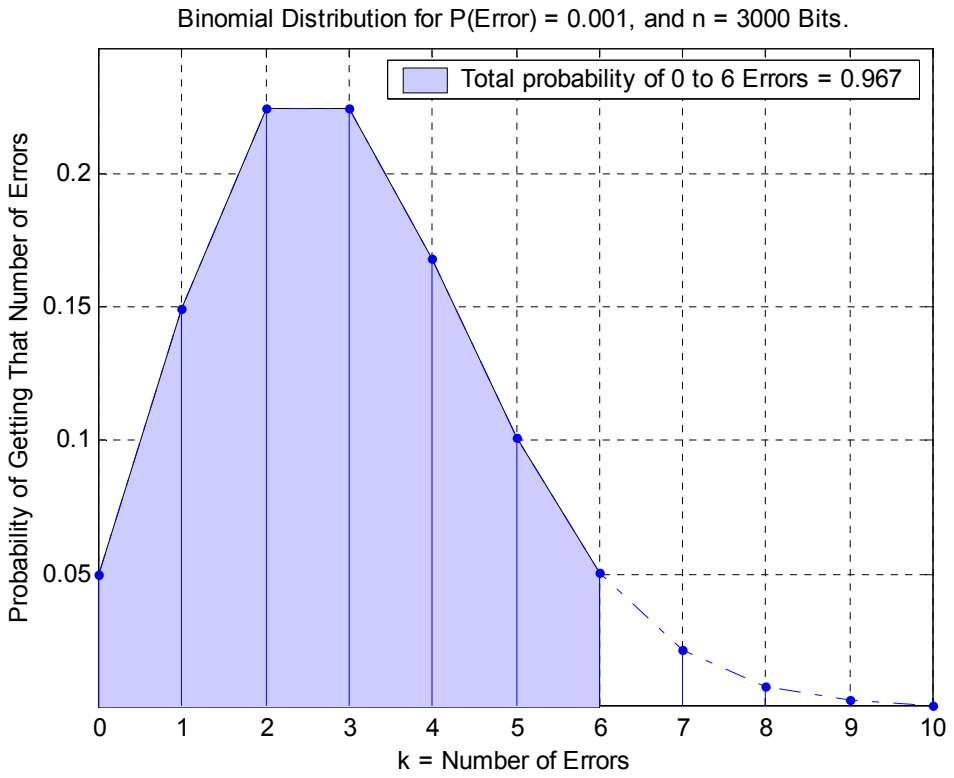
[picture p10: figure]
k = Number of Errors

Probability of Getting That Number of Errors

Binomial Distribution for P(Error) = 0.001, and n = 3000 Bits.

Total probability of 0 to 6 Errors = 0.967

We see that the results haven’t changed at all when we go from n = 100, to n = 1000 (at least within the displayed number of significant digits.) This is the behavior we see for values of n greater than about 100. To formally prove that this is the case as n goes to infinity requires a bit more math than we’d like to get into here, but as a quick “feel good” check, we can easily just look at the behavior of the case for 0 observed errors, as n gets large.

As we computed before, for a BER of 1/n, the probability of seeing 0 bit errors (or “all heads”) in n trials is just:

Ptot = [P(head)]

n

= [1 - P(tail)]

n

= [1 - 1/n]n

We can easily plot this quantity as a function of n:

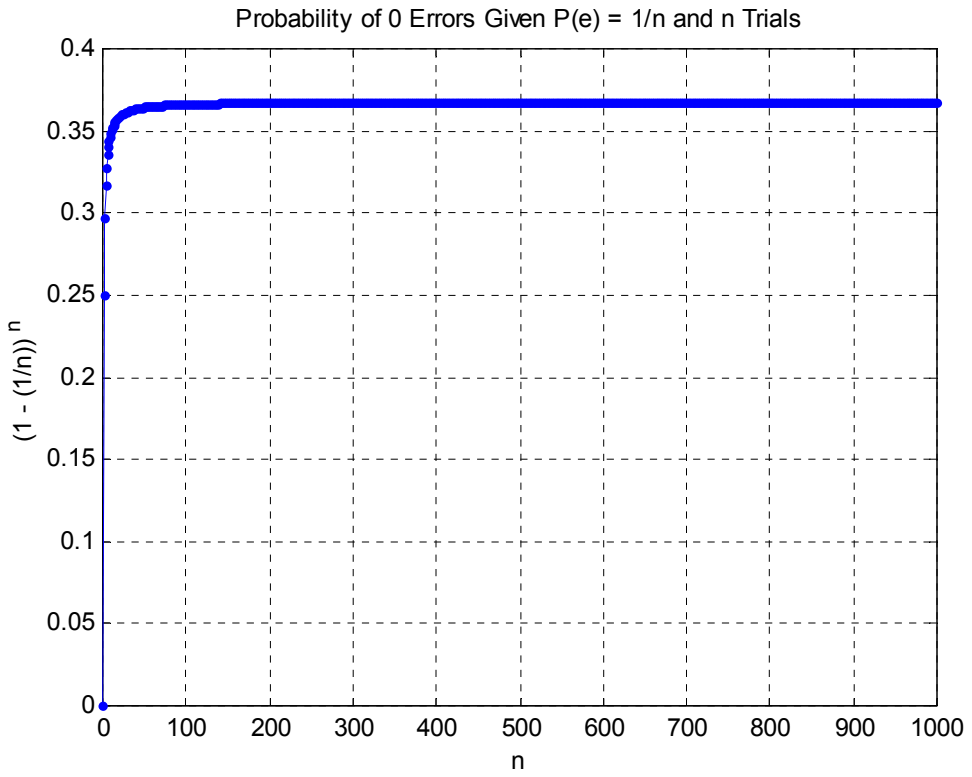
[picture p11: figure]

Probability of 0 Errors Given P(e) = 1/n and n Trials

We see that the value asymptotically approaches some particular limit value, and for n greater than 100, it is practically level.

(As an aside, the actual limit of (1-1/n)

n
as n -> ∞ is actually 1/e, (~.3679), but the proof of this is left up to the reader. (Hint: Look it up in Google. That’s what I did!))

Conclusion:

In this paper, we have attempted to de-mystify some of the statistical analysis surrounding the notion of Bit Error Ratio testing. Beginning with the basic Probabilistic concepts of Bernoulli Trials and the Binomial Distribution, a model was developed that allows for the visualization of such statistical concepts as Confidence Intervals and Hypothesis Testing. Whenever possible, analogies and examples were used to help simplify these concepts and present them in a manner that appeals ideally to the intuition of the reader, without requiring mathematical “leaps of faith”, or prior training in Statistics or Probability Theory. A small MATLAB implementation of the model is included (see Appendix A). This code was the exact code used to generate all of the error distribution plots in this document, and is included here for the benefit of anyone wishing to further explore this subject.

APPENDIX A:
MATLAB CODE FOR CREATING ERROR-RATE DISTRIBUTIONS

function dist = ber(p, n, e2calc, nsum)
%BER | Compute binomial distribution for zero to n errors
% | given a target BER and number of bits sent (trials).
%
% | User provides the probability of error, number of trials,
% | number of error values to calculate out to, and the subset
% | of that number to include in the 'total probability' sum.
%
% | The plot is the binomial error distribution.
%
%dist = ber(p, n, e2calc, nsum);
%dist = ber(1E-8, 3E8, 20, 7);

%--- Revision History -----------------------------------------------% Version 2.0 (06Feb2003) (aab)
% + Created by Andy Baldman, UNH InterOperability Lab. %--------------------------------------------------------------------

% Label the plots in terms of bits/errors, or flips/tails?
s = {'Errors', 'Bits'};
%s = {'Tails', 'Flips'};

% (Since the numbers involved here can get really big, the results of nchoosek
% are only exact to 15 places in some cases. | (Good enough for our purposes.)
% MATLAB normally notifies the user when this happens. | Temporarily turn off
% the displaying of warning messages.)
warnstate = warning;
warning off

for i = 1:e2calc+1
k = i-1;
C = nchoosek(n,k);
p_of_num = C * p^k * (1-p)^(n-k); x(i) = k;
dist(i) = p_of_num;
end

% Plot.
figure;
hl = area(x(1:nsum+1),dist(1:nsum+1),'facecolor',[.8 .8 1]);
hold on;stem(x,dist,'b.'); % Make the stem plot.
hold on;plot(x,dist,'b-.'); % Add a dash plot to highlight the overall shape. xlabel(sprintf('k = Number of %s', s{1}));
ylabel(sprintf('Probability of Getting That Number of %s', s{1})); title(sprintf('Binomial Distribution for P(%s) = %.3g, and n = %d %s.', s{1}(1:end-1), p, n, s{2}));
legend(hl, sprintf('Total probability of 0 to %d %s = %.3f', nsum, s{1}, sum(dist(1:nsum+1))), 1);
zoom on;grid on;
axis([min(x) max(x) min(dist) 1.1*max(dist)]); % Adjust axes to look pretty. warning(warnstate); % Reset warning state

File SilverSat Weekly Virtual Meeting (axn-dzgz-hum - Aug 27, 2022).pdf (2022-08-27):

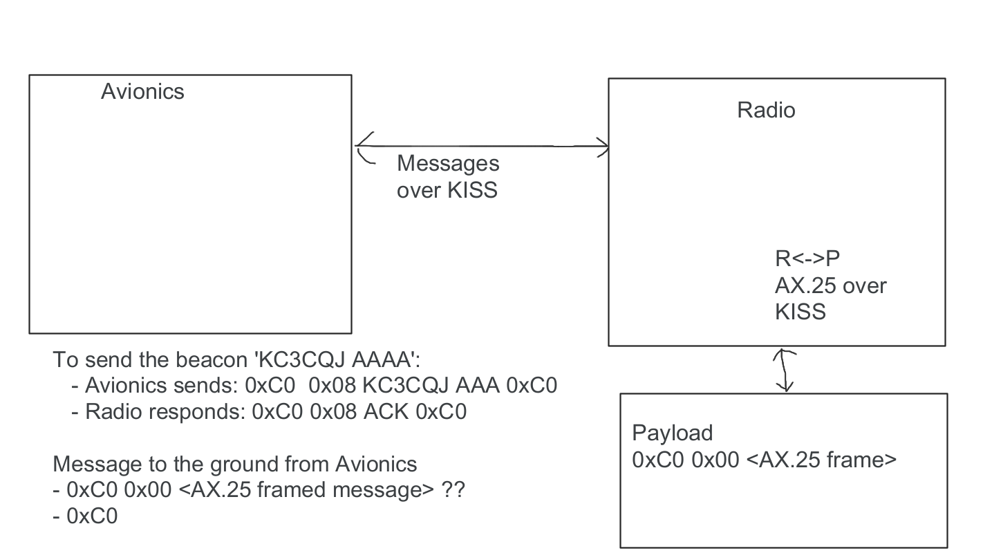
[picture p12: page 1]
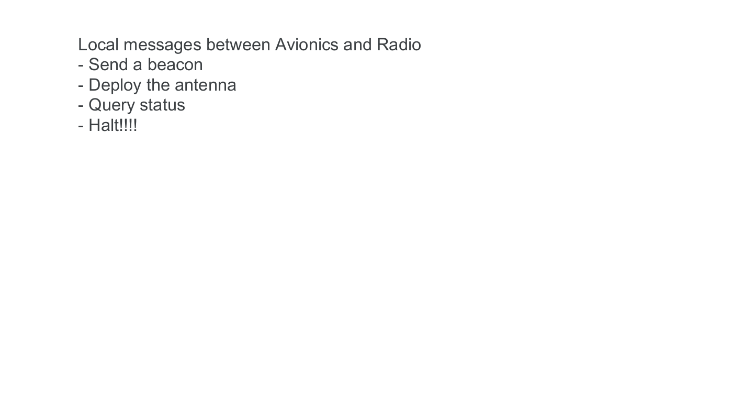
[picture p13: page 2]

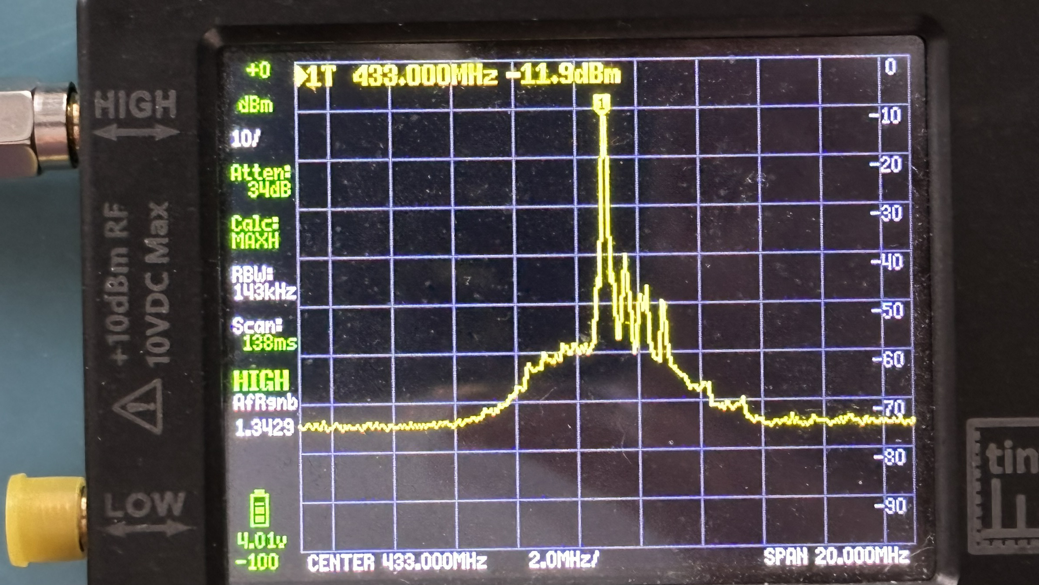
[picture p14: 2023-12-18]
OutputSpectrum_20MHz_span.jpeg

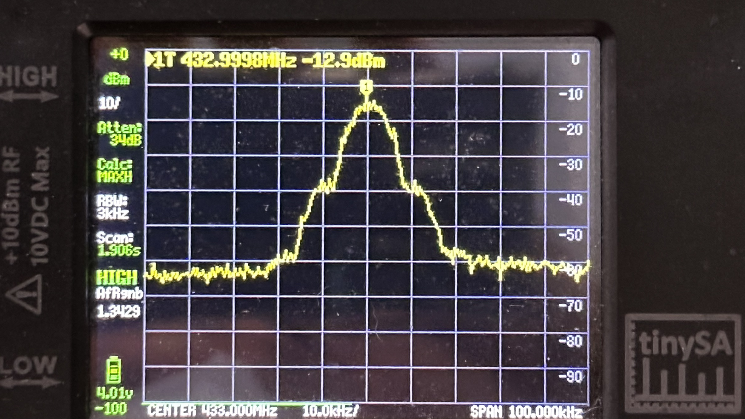
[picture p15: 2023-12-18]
Output_Spectrum_GMSK_BT_5.jpeg

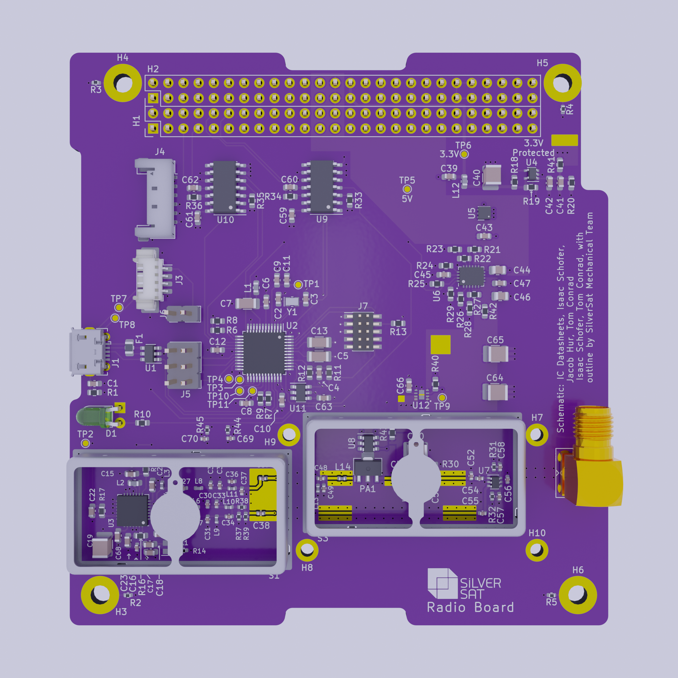
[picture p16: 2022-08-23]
SilverSat_Comms.png

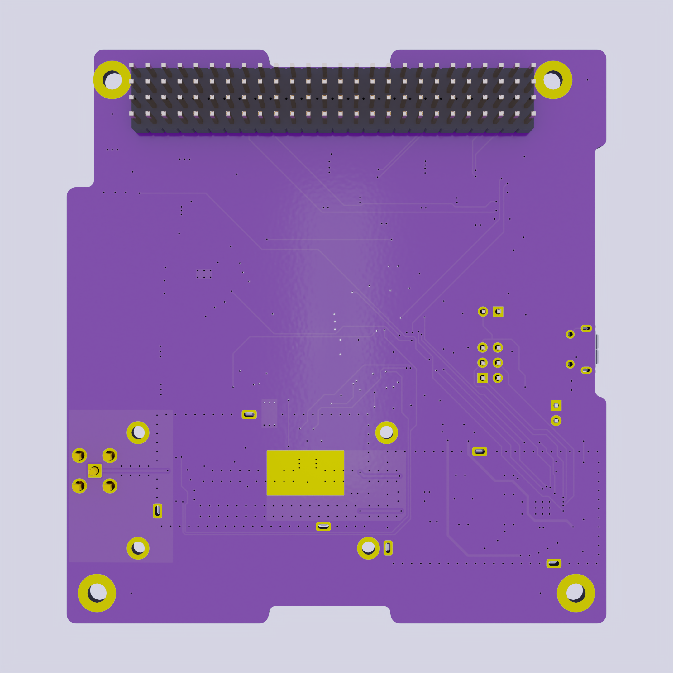
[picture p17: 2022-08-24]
SilverSat_Comms_b.png

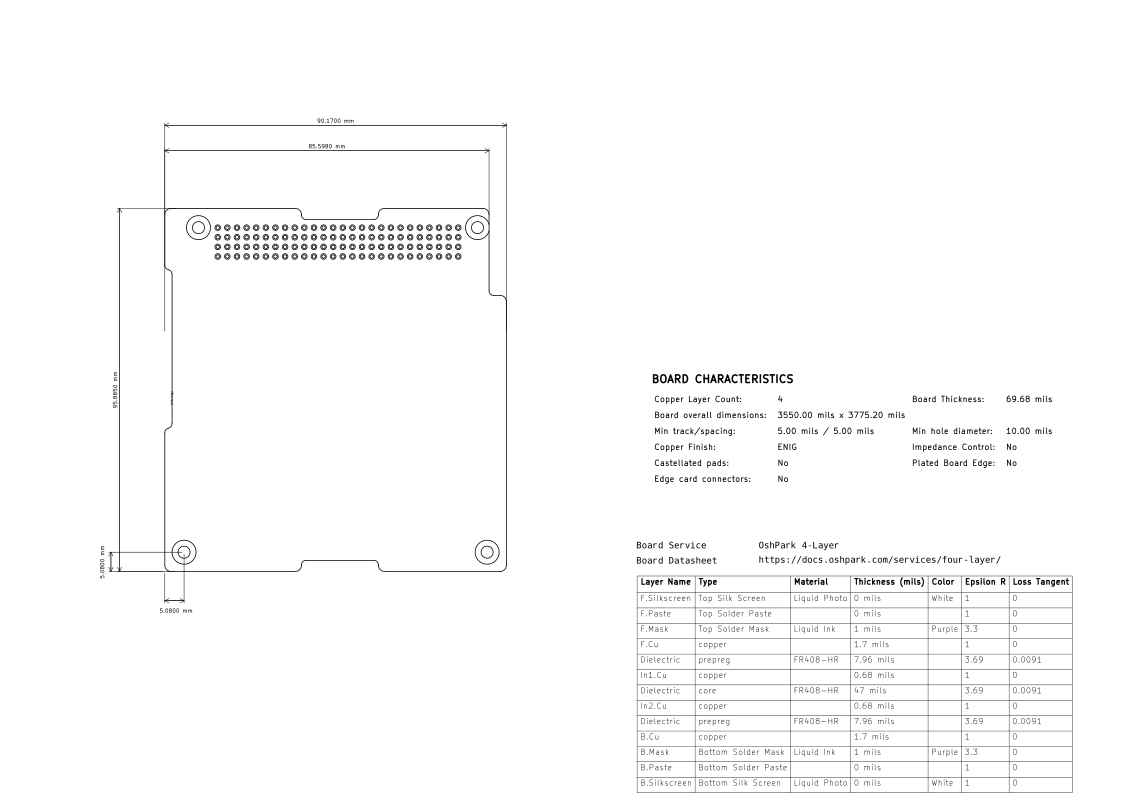
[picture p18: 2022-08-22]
doc/img/SilverSat_Comms-User_Drawings.svg.png

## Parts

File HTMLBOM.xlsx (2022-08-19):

References | Value | MPN | Manufacturer | Quantity | Source | 68
C4, C6, C8, C9, C10, C12, C22, C39, C41, C42, C43, C47, C59, C60, C61, C62, C63 | 0.1u | 06031C104K4Z2A | AVX | 17 | Mouser | 68
C14, C17, C18, C23, C68 | 0.01u | 06033C103J4Z2A | AVX | 5 | Mouser
C5, C7, C13 | 1u | 12065C105M4Z2A | AVX | 3 | Mouser
C27, C28, C29 | 4.3p | GCM1555C1H4R3BA16D | Murata | 3 | Mouser
C30, C31, C32 | 5.6p | 04025U5R6B4T2A | AVX | 3 | Mouser
C36, C52, C53 | 6.8p | GCM1555C1H6R8BA16D (https://www.mouser.com/ProductDetail/Murata-Electronics/GCM1555C1H6R8BA16D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) | Murata | 3 | Mouser
C38, C51, C67 | 100p | GCM1555C1H101FA16J | Murata | 3 | Mouser
C40, C64, C65 | 10u | 12103C106K4Z2A | AVX | 3 | Mouser
C2, C3 | 20p | 06031A200K4T2A | AVX | 2 | Mouser
C20, C21 | 100p | 06031A101F4T2A | AVX | 2 | Mouser
C33, C34 | 5.1p | GCQ1555C1H5R1WB01D | Murata | 2 | Mouser
C44, C46 | 1u | 08053C105K4Z4A (https://www.mouser.com/ProductDetail/Kyocera-AVX/08053C105K4Z4A?qs=G2E3TvrFun3QaxQCzTl%2FlA%3D%3D) | AVX | 2 | Mouser
C55, C56 | 56p | GCM1555C1H560FA16D | Murata | 2 | Mouser
C57, C58 | 220p | GRT1555C1H221FA02D | Murata | 2 | Mouser
C1 | 0.01u | ESD31C103K4T2A-18 | AVX | 1 | Mouser
C11 | 4.7u | GRT188C81C475KE13D | Murata | 1 | Mouser
C15 | 39p | 06035A390J4T2A | AVX | 1 | Mouser
C19 | 4.7u | 12065C475K4Z2A | AVX | 1 | Digikey
C45 | 2200p | GCM1885C1H222FA16D | Murata | 1 | Mouser
C48 | 12p | 04025A120F4T2A | AVX | 1 | Mouser
C49 | 15p | GRT1555C1H150FA02D | Murata | 1 | Mouser
C50 | 2.2u | C1210C225K1RACAUTO | KEMET | 1 | Mouser
C54 | 39p | GRT1555C1H390FA02D | Murata | 1 | Mouser
R6, R7, R8, R9, R12, R13, R18, R19, R20, R26, R29, R33, R35, R40 | 10k | ERJ-3RBD1002V | Panasonic | 14 | Mouser
R2, R3, R4, R5, R14, R31, R32, R38, R44, R45 | 0 | ERJ-2GE0R00X | Panasonic | 10 | Mouser
R41, R42, R43 | 0 | ERJ-3GEY0R00V | Panasonic | 3 | Mouser
R21, R27 | 110k | ERJ-H3EF1103V | Panasonic | 2 | Mouser
R34, R36 | 453 | ERJ-3EKF4530V | Panasonic | 2 | Mouser
R1 | 1M | ERJ-PA3F1004V | Panasonic | 1 | Mouser
R10 | 931 | ERJ-PB3B9310V | Panasonic | 1 | Mouser
R11 | 330 | ERJ-H3EF3300V (https://www.mouser.com/ProductDetail/Panasonic/ERJ-H3EF3300V?qs=eP2BKZSCXI61roRLPi8W7w%3D%3D) | Panasonic | 1 | Mouser
R15 | 12k | ERJ-3RBD123V | Panasonic | 1 | Mouser
R16 | 220 | ERJ-PB3D2200V | Panasonic | 1 | Mouser
R17 | 100 | ERJ-3RBD101V | Panasonic | 1 | Mouser
R22 | 7.15k | ERJ-3EKF7151V (https://www.mouser.com/ProductDetail/Panasonic/ERJ-3EKF7151V?qs=DQ1bOpn7xPCrCsug0gxegg%3D%3D) | Panasonic | 1 | Mouser
R23 | 26.1k | ERJ-PB3D2612V | Panasonic | 1 | Mouser
R24 | 124k | ERJ-3EKF1243V | Panasonic | 1 | Mouser
R25 | 53.6k | ERJ-3EKF5362V | Panasonic | 1 | Mouser
R28 | 31.6k | ERJ-3EKF3162V | Panasonic | 1 | Mouser
R30 | 5.1 | ERJ-U03F5R10V | Panasonic | 1 | Mouser
L3, L4, L5 | 0.100u | 0402DC-R10XJRW | Coilcraft | 3 | Mouser
L6, L7, L8 | 43n | 0402DC-43NXGRW | Coilcraft | 3 | Mouser
L1, L12 | Ferrite Bead | BLM18SP102SH1D | Murata | 2 | Mouser
L9, L10 | 27n | 0402DC-27NXGRW | Coilcraft | 2 | Mouser
L2 | 10n | 0603DC-10NXJRW | Coilcraft | 1 | Mouser
L11 | 4.7n | 0402DC-4N7XGRW | Coilcraft | 1 | Mouser
L13 | 40n | 0402DC-39NXGRW | Coilcraft | 1 | Mouser
L14 | 4.3n | 0402DC-4N3XGRW | Coilcraft | 1 | Mouser
L15 | 47n | 0402DC-47NXGRW | Coilcraft | 1 | Mouser
L16 | 5.1n | 0402DC-5N1XGRW | Coilcraft | 1 | Mouser
D1 | LED |  |  | 1
U9, U10 | SN65HVD70D | SN65HVD70D | Texas Instruments | 2 | Mouser
U1 | USBLC6-2SC6 | USBLC6-4SC6 | ST Micro | 1 | Mouser
U2 | ATSAMD21G18A-A | ATSAMD21G18A-A | Microchip | 1 | Silversat
U3 | AX5043 | AX5043-1-TW30 | OnSemi | 1 | Mouser
U4 | FPF2004 | FPF2004 | Fairchild | 1 | Digikey
U5 | TVS1800DRV | TVS1800DRVR | Texas Instruments | 1 | Arrow
U6 | TPS25940LQRVCRQ1 | TPS25940LRVCR | Texas Instruments | 1 | Digikey
U7 | CAEL-CG2409M2 | CG2409M2-C4 | CEL | 1 | Mouser
U8 | TMP100 | TMP100NA/3K | Texas Instruments | 1 | Digikey
U11 | TPS3813-Q1_Watchdog | TPS3813K33-Q1 | Texas Instruments | 1
U12 | TPS22965NTDSGRQ1 | TPS22965NTDSGRQ1 | TI | 1 | Mouser
Y1 | CM8V-T1A-32.768KHZ-12.5PF-20PPM-TB-QA | CM8V-T1A-32.768KHZ-12.5PF-20PPM-TB-QA | Micro Crystal AG | 1 | Mouser
X1 | TG2016SMN | TG2016SMN 48.0000M-ECGNNM0 | Seiko Epson Corporation | 1 | Mouser
F1 | 300 mA | PICOASMDC012S-2 | Littelfuse | 1 | Digikey
H1, H2 | Conn_02x26_Odd_Even | HMTSW-126-22-G-D-440 | Samtec | 2 | Mouser
S1, S3 | MS353-10C_Masach_Shield | MS355-10F | Masach | 2 | Mouser
PA1 | HMC452ST89 | HMC452ST89ETR | Analog Devices | 1 | Mouser
J1 | USB_B_Micro | 105017-0001 | Molex | 1 | Mouser
J2 | Conn_Coaxial | 901-143-6RFX | Amphenol | 1 | Mouser
J3 | 53261-0471 | 53261-0471 | Molex | 1 | Mouser
J4 | 504050-0691 | 504050-0691 | Molex | 1 | Mouser
J5 | MTSW-103-06-G-D-110 | MTSW-103-06-G-D-110 | Samtec | 1 | Mouser
J6 | 77315-801-02LF | 77315-801-02LF | Amphenol | 1 | Mouser
J7 | ~ | 4048 | Adafruit | 1 | Mouser

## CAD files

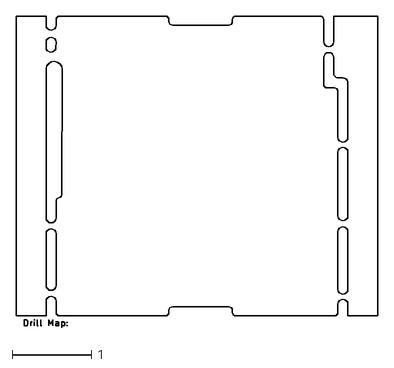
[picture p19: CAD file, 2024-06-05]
gerbers/SilverSat_Comms-NPTH-drl_map.dxf
4.55 x 3.93

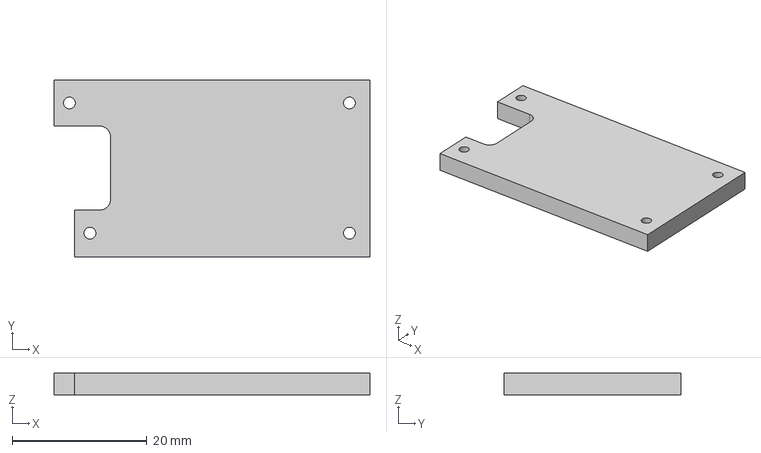
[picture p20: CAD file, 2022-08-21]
HeatSpreader.step
46.9 x 26.3 x 3.20 mm

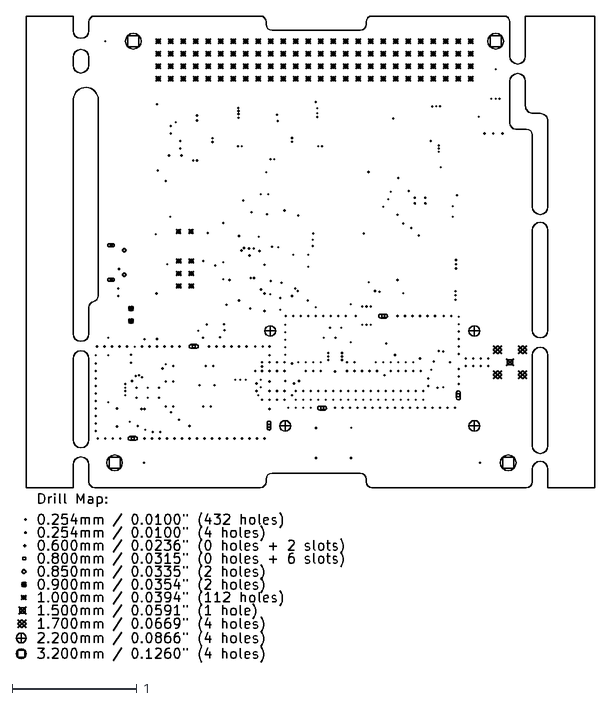
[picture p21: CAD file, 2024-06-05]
gerbers/SilverSat_Comms-PTH-drl_map.dxf
4.63 x 5.17

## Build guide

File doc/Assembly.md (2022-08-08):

# Radio Board
SilverSat Limited

Website: https://silversat.org
Facebook: https://www.facebook.com/SilverSatorg/
Instagram: https://www.instagram.com/silversat/
Twitter: https://twitter.com/silversatorg

Draft Assembly Instructions:
After applying the solder paste, use a suction
tool or 3-mil (76.2μm) point tweezers to place
all passive components, starting with the
smallest ones, then working up in size. Next,
use a suction tool to place the integrated
circuits. Put the board in a reflow oven to
solder the surface mount components in place.
Then, solder the through-hole components
and add the RF shields.

Finally, carefully inspect all solder
connections for short circuits or reflow
faults. Fix short circuits either by using a
soldering iron to break bridges, or 
re-soldering the connections. Solder problems
from reflowing can be fixed by re-soldering
them by hand.

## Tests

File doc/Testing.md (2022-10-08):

# Board Testing Instructions
SilverSat Ltd.
2022-08-26

Last modified 2022-10-08

# 1. Check Components
Inspect all of the components to verify that none are missing or oriented incorrectly. If any occurs, the component must be re-installed using hand soldering.

# 2. Check Soldering
After soldering all of the surface-mount and through-hole components, carefully check all of the connections to ensure there is no solder bridging or “tombstoning” (when a surface-mount passive component, such as a capacitor, inductor, or resistor, flips vertically due to solder surface tension). Remove solder bridges by dragging a hot soldering iron between the bridged connections to re-melt and separate them. You may need a very fine tip to do this. Fix any tombstoned components by re-soldering them by hand.

# 3. Check 3.3V Power Supply
Use an ohmmeter to test between TP6, 3.3V Protected zone, and ground. If there is excessively high resistance on 3.3V Protected, check U4, the resistors, and L12 to ensure thay can conduct electricity. If they do not conduct, replace them.
    
* The capacitors should also be checked, but as of 2022-08-26 no method is specified.

# 4. Load the Bootloader
TBD

# 5. Load the Test Code
Install the SilverSat Radio Board definitions given in INSTALL.md. Open the test code and upload it to the board using the USB port.
* Since this code has not yet been written, no further test steps are available. However, this code may have tests for serial and radio transceive.

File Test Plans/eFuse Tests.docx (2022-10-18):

# Validation, verification, and test plans

Test plans are part of the overall systems engineering and development process. In a perfect world, you start with a set of well defined requirements, and you verify that your system meets those requirements.

This is called Verification. Requirements generally should be written in a way that they are easily verifiable. That means, the requirements should be written with the test in mind so that you don’t end up frustrating the test engineers 😉

There is a similar idea called Validation. This means checking that the requirements are valid. Many projects fail because they don’t have the right requirements to begin with! But we’ll leave that for now.

There are four basic verification methods. Inspection, Demonstration, Test, and Analysis.

Inspection is the nondestructive examination of a product or system using one or more of the five senses (visual, auditory, olfactory, tactile, taste). It may include simple physical manipulation and measurements.

Demonstration is the manipulation of the product or system as it is intended to be used to verify that the results are as planned or expected. Think of it as more qualitative than quantitative.

Test is the verification of a product or system using a controlled and predefined series of inputs, data, or stimuli to ensure that the product or system will produce a very specific and predefined output as specified by the requirements.

Analysis is the verification of a product or system using models, calculations and testing equipment. Analysis allows someone to make predictive statements about the typical performance of a product or system based on the confirmed test results of a sample set or by combining the outcome of individual tests to conclude something new about the product or system. It is often used to predict the breaking point or failure of a product or system by using nondestructive tests to extrapolate the failure point.

For example, the requirement could read, “the board shall be purple”. And we would just observe and say, “yup, it’s purple”, and write down that it was verified by inspection.

Remember if you don’t test it…it’s your opinion, not a fact.

# Exercise

Let’s develop the test plans that verify the radio board.

So, imagine you’re making lots of parts. And you’re working with a team of people who all need access to your data, and/or might be taking over testing while you’re not available.

In a production environment, tests are performed by multiple people and the data needs to be accessible by people outside of the test group (like Quality Assurance, or the designers, or mission managers).

We want to take and store data in an easily accessible format, so let’s create a spreadsheet to tabulate all of the test results.

Make sure it includes information about who performed the test, the date the test was performed, and the serial number of the device under test. We’ll also want to indicate which requirement this verifies. Ultimately these are all usually tabulated in what’s called a Requirements Verification Test Matrix (RVTM). This provides an easy way to see that all of the requirements have been satisfied. Mostly for managers who don’t do a lot, but like everyone to know they’re on top of things…but customers sometimes require them too.

So, Let’s outline the test plan just for the eFuses on the radio board.

# eFuse Test plan for Radio Board

## eFuse performance requirements:

1. The 3V3 eFuse output voltage shall be X volts +/- Y volts at Z amps.
2. The 5V eFuse output voltage shall be X volts +/- Y volts at Z amps.
3. The 3V3 eFuse shall trip at X amps.
4. The 5V eFuse shall trip at X amps.
5. The maximum 5V current without tripping shall be X amps.
6. The maximum 3V3 current without tripping shall be X amps.
7. The 5V_Current output shall be calibrated over the expected operating range of currents.
8. The 5V_Current output voltage shall be within the A/D limits of the SAMD21 processor.
9. Each eFuse shall operate within manufacturer specified dissipation limits over the expected operating current range and expected operating temperature range.
10. The eFuse overcurrent signals shall not exceed 3.3V (to protect the SAMD21).
11. More?

## Other potential requirements:

1. Workmanship standards (IPC, NASA, etc.)
2. Manufacturing standards (for PCBs)
3. Thermal limits. Verify that the system works over the expected operating temperature range.
4. Reliability tests. Verify that the system can be expected to work over its operational life. See Environmental Stress Screening. Generally, this means operating the system over a temperature range, with on/off power cycling.
5. Anything else? (What about shock and vibration? any mass limits? any material concerns? Are you required to keep track of what’s in or on the board?)

## What we’re trying to test (just for the eFuse):

1. Verify proper assembly (no shorts!)
2. Verify that the eFuse circuits meet requirements.
3. Calibrate the 5V current output.

## Required Equipment:

Equipment required (or would be useful)

1. 2 x DC power supplies. One for 3V3, one for 5V. 5V needs to support 2A.
2. Programmable load (Mr. Tom has one), for testing eFuse and current monitor performance.
  a. Voltmeters. Optionally 2, so we can monitor voltage at source and load, but the programmable load reports voltage at the load.
3. IR thermometer (optional) or thermocouple. You can use your fingers too, but it’s nice to know what’s getting hot and how hot it’s getting. (Mr. Tom has one of these too.)

## Test Plan:

1. Prestart.
  a. Check for shorts on 3V3 and 5V at H1/H2.
2. Verify eFuse performance.
  a. 3V3 eFuse. (Connected by default)
    i. Connect 3V3 at H1/H2
    ii. Is 3V3 present at the input and output?
    iii. What does the overcurrent pin indicate?
    iv. Cause an overcurrent. What does the part do?
  b. 5V eFuse. (Connected by default)
    i. Connect 5V at H1/H2
    ii. Is 5V present at 5V_LUP signal?
    iii. What does OC5V indicate?
    iv. What voltage is present at 5V_Current?
    v. Attach load.
      1. What load do we need to be able to cause an overcurrent?
    vi. Calibrate the 5V_current signal
      1. Vary the load current using the programmable load.
      2. Record the voltage at each point.
      3. What is a reasonable set of values for the current? Min, max, step?
      4. Is anything getting hot? At max current?

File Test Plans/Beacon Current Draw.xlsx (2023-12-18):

Start date: | 2023-03-06 | Start time: | 0:42:40 |  |  |  |  |  | Beacon sent: "MYCALLABCD" |  | Time base: 100mSec.
Sample interval: | 0.01 |  | 5 | voltage |  | 27.1 | Joules
Reading # | Reading |  |  |  |  | 6.2172 | Joules | total energy | 33.29 | Total energy draw | 19 second beacon
1 | -0.000287 |  | 1.44e-05 |  | 0.046 | 0.001518 |  | 0.0015324
2 | -0.000232 |  | 1.16e-05 |  | 0.046 | 0.001518 |  | 0.0015296
3 | -0.00025 |  | 1.25e-05 |  | 0.046 | 0.001518 |  | 0.0015305
4 | -0.000285 |  | 1.42e-05 |  | 0.046 | 0.001518 |  | 0.0015322
5 | -0.000271 |  | 1.36e-05 |  | 0.046 | 0.001518 |  | 0.0015316
6 | -0.000262 |  | 1.31e-05 |  | 0.046 | 0.001518 |  | 0.0015311
7 | -0.000241 |  | 1.21e-05 |  | 0.046 | 0.001518 |  | 0.0015301
8 | -0.00027 |  | 1.35e-05 |  | 0.046 | 0.001518 |  | 0.0015315
9 | -0.000281 |  | 1.4e-05 |  | 0.046 | 0.001518 |  | 0.001532
10 | -0.000277 |  | 1.39e-05 |  | 0.046 | 0.001518 |  | 0.0015319
11 | -0.000274 |  | 1.37e-05 |  | 0.046 | 0.001518 |  | 0.0015317
12 | -0.000251 |  | 1.25e-05 |  | 0.046 | 0.001518 |  | 0.0015305
13 | -0.000249 |  | 1.24e-05 |  | 0.046 | 0.001518 |  | 0.0015304
14 | -0.00028 |  | 1.4e-05 |  | 0.046 | 0.001518 |  | 0.001532
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

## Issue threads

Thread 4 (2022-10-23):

Next Revision changes

tconrad26, 2022-10-23:
Bring out TxD2/RxD2, TxD1/RxD1, TxD0/RxD0 on separate headers.

Make them compatible with FTDI USB cables.

Make sure there's an easy way to tristate the serial drivers.

Note that the SAMD21 is not 5V tolerant, so it might be good to add buffers to protect the part where needed.

Bring out SDA1/SCL1 on header to add extra I2C port, or better yet use QWIIC connectors.

Bring +5 and +3V3 in on headers as well so we can build board without populating H1/H2 (mostly for mounting in a nice enclosure)
How would you configure the board to make it easy to put in a box?
What connectors would you choose?

If we opt to use this board in the ground station, remember that there will be another external PA.  That implies either bringing out a way to break the RF path, or bring out the TX/RX signals to a header.

PAEnable was never brought out to a test header.  If doing that, put SYSCLK, DCLK and DATA on it as well.  This would enable a wire mode interface to the AX5043.

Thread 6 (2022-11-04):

solder dams

tconrad26, 2022-11-04:
Add solder dams across traces near coupling caps in the RF sections.  The solder is bleeding out along the trace.

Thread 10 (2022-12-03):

AX5043 oscillator voltage

tconrad26, 2022-12-03:
Part we bought is 1.8V, but is connected to 3.3V.  Seems to work, but may not be long term reliable.

Add optional small LDO to drop voltage to TCXO.

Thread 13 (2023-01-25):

I2C

tconrad26, 2023-01-25:
The signals Radio_SDA and Radio_SCLK are on the wrong pins.

They should be on 37,39 respectively.

Also, the Radio does not control the Antenna deployment anymore

lcongdon, 2023-01-26:
Does this imply that Avionics is now doing the antenna deployment?

tconrad26, 2023-01-28:
Actually, what I forgot was that the radio was only passing through the Antenna SDA/SCL signals since they were left off the other boards.  The only antenna interface signals that are routed to the radio are the backup release signals (Release_A and Release_B).  It is still possible to route these signals to the spare I2C port on the radio processor, if needed.

Closed 2024-03-17.

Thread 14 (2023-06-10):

Hardware improvements

isaac-silversat, 2023-06-10:
5v Pgood routing to SAMD21
Redundant 5v to #.3V and reverse voltage converters
SAMD212 reset indicator

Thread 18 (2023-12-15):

Attenuator on wrong path

tconrad26, 2023-12-15:
The attenuator is on the receive path rather than the transmit path.  There's not much sense in attenuating the receive signal, and it looks like we're overdriving the PA.
Move the Attenuator to the PA path, after the Harmonic Filter.

isaac-silversat, 2024-02-17:
The attenuator is already on the transmit path. Do you want it swapped anyway?

Closed 2024-03-17.

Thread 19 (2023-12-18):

RMS current in L16

tconrad26, 2023-12-18:
Looks like we might be exceeding the max RMS current in L16.

Evaluate a replacement, perhaps the Micro Spring inductors from Coilcraft or similar.

tconrad26, 2023-12-18:
I looked at wrong part number, it's okay.

Closed 2023-12-18.

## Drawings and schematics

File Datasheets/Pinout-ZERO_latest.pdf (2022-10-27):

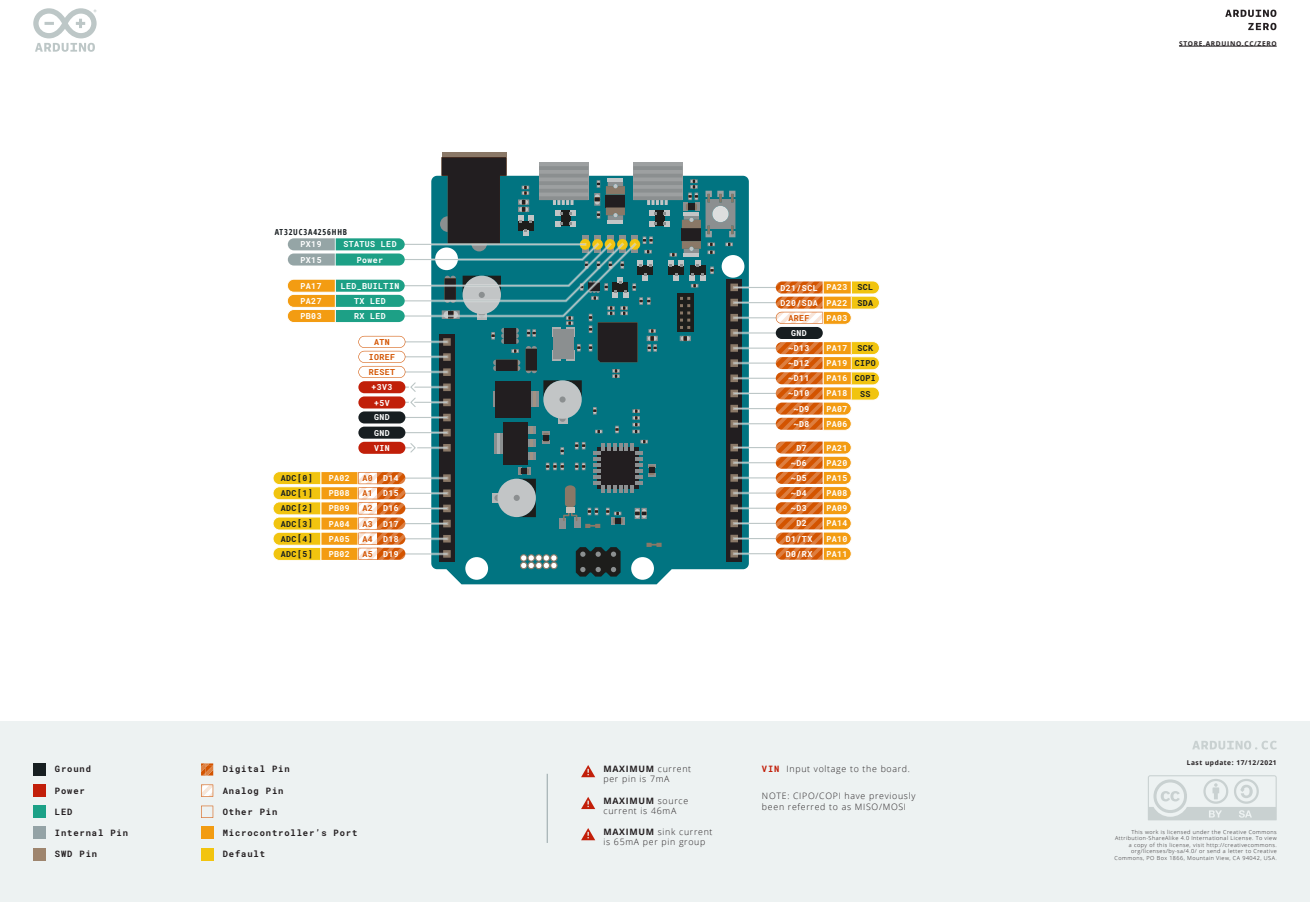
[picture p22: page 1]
Ground; Power; LED; Internal Pin; SWD Pin; Digital Pin; Analog Pin; Other Pin; Microcontroller’s Port; Default; Last update: 17/12/2021; RESET; ADC[0] ADC[1] ADC[2] ADC[3] ADC[4] ADC[5]; IOREF; ATN; +3V3 +5V GND GND VIN; D21/SCL D20/SDA AREF GND ~D13; SCL; SDA; SCK CIPO COPI SS; LED_BUILTIN TX LED RX LED; AT32UC3A4256HHB; STATUS LED

STORE.ARDUINO.CC/ZERO (https://store.arduino.cc/arduino-zero)

PB08 | A1 A1
PB09 | A2

MAXIMUM current
per pin is 7mA
MAXIMUM source
current is 46mA
MAXIMUM sink current
is 65mA per pin group

VIN Input voltage to the board.

NOTE: CIPO/COPI have previously
been referred to as MISO/MOSI

This work is licensed under the Creative Commons
Attribution-ShareAlike 4.0 International License. To view
a copy of this license, visit http://creativecommons.
org/licenses/by-sa/4.0/ or send a letter to Creative
Commons, PO Box 1866, Mountain View, CA 94042, USA.

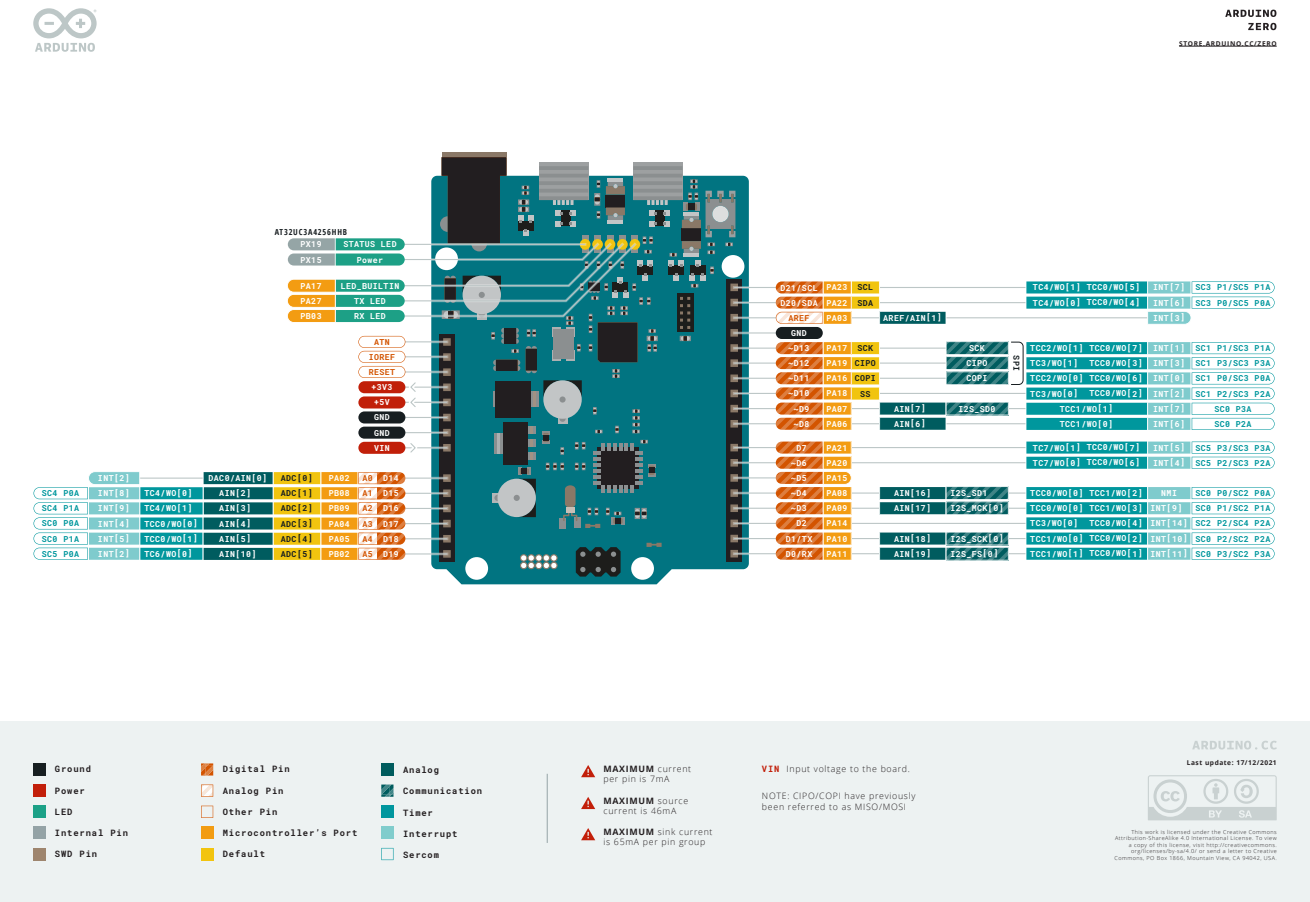
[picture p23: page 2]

VIN Input voltage to the board.

NOTE: CIPO/COPI have previously
been referred to as MISO/MOSI

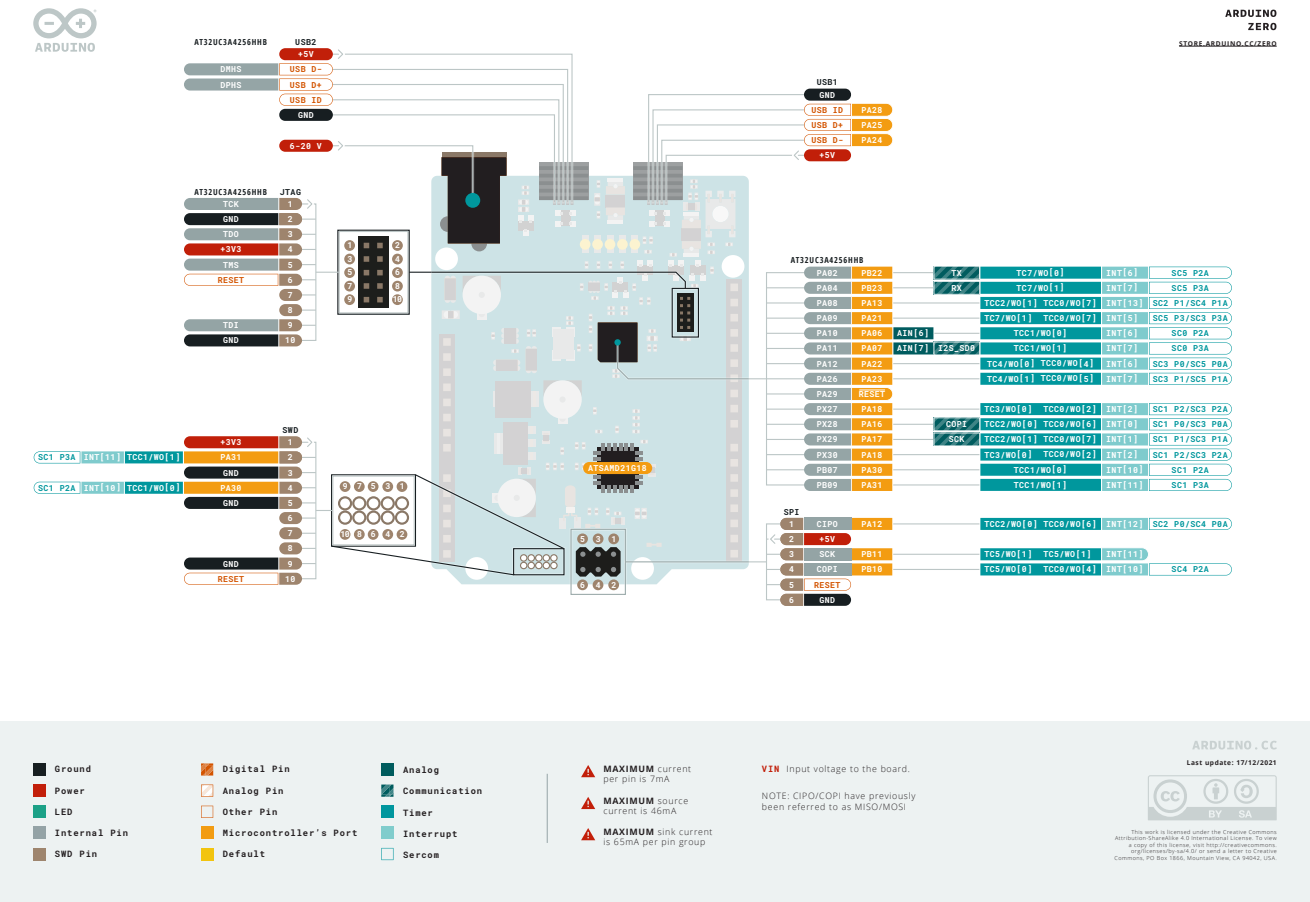
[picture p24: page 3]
Analog; Communication; Timer; Interrupt; Sercom; Ground; Power; LED; Digital Pin; Analog Pin; Other Pin; Last update: 17/12/2021; ATSAMD21G18; AT32UC3A4256HHB; USB D- +5V; USB D+; USB ID; GND; USB1; JTAG; TCK; TDO; TMS; RESET; TDI; SWD; USB D-; USB D+ USB ID GND; DMHS DPHS; USB2; SPI; 1 CIPO 2 +5V 3 SCK 4 COPI 5 RESET 6 GND; TCC2/WO[0] TCC0/WO[6]; TC5/WO[1] TC5/WO[1] TC5/WO[0] TCC0/WO[4]; INT[12]; INT[11]; INT[10]; TCC1/WO[1]; TCC1/WO[0]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

PA07 | AIN[7] | I2S_SD0 | TCC1/WO[1] | INT[7]
PA22 | | | TC4/WO[0] TCC0/WO[4] | INT[6]

MAXIMUM current
per pin is 7mA
MAXIMUM source
current is 46mA

VIN Input voltage to the board.

NOTE: CIPO/COPI have previously
been referred to as MISO/MOSI

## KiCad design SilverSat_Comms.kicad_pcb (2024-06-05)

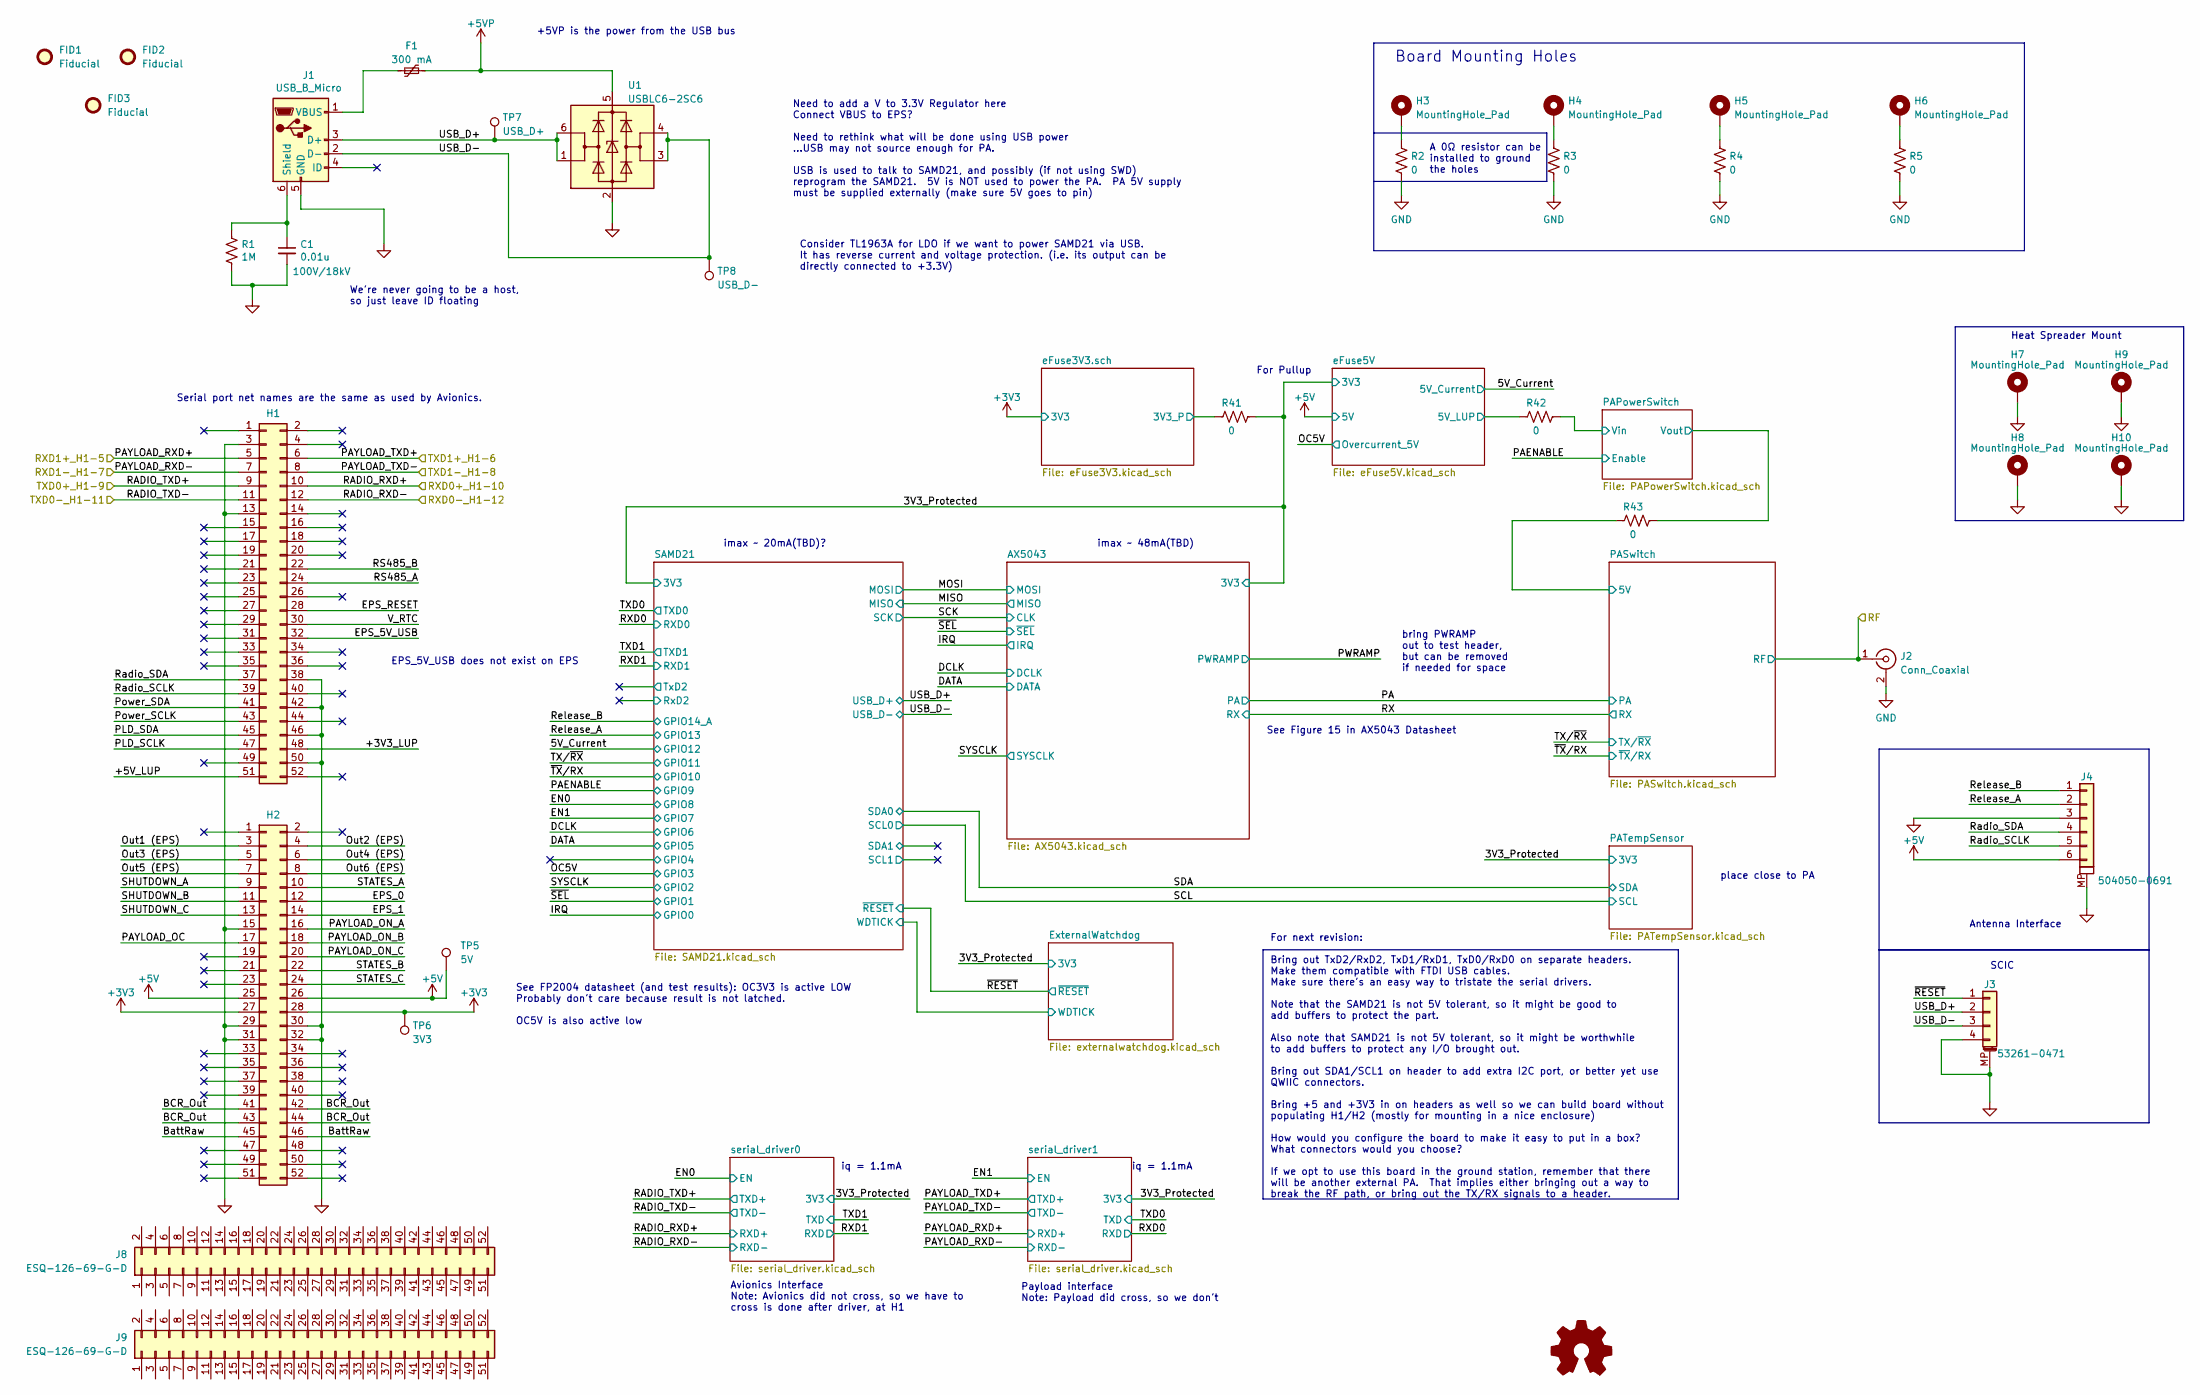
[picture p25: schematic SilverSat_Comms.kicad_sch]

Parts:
C1: 0.01u; C_0603_1608Metric; Voltage 100V/18kV; MPN KAE15AR72A103KT18
F1: 300 mA; Fuse_0805_2012Metric; Part_Number PICOASMDC012S-2
FID1, FID2, FID3: Fiducial; Fiducial_1.5mm_Mask2.5mm
H1, H2: Conn_02x26_Odd_Even; TheBus2x26; Part_Number HMTSW-126-22-G-D-440
H3, H4, H5, H6: MountingHole_Pad; MountingHole_3.2mm_M3_Pad_TopBottom
H7, H8, H9, H10: MountingHole_Pad; MountingHole_2.2mm_M2_DIN965_Pad_TopBottom
J1: USB_B_Micro; USB_Micro-B_Molex-105017-0001; Part_Number 105017-0001
J2: Conn_Coaxial; SMA_Amphenol_901-143_Horizontal; MPN 901-143-6RFX; Mouser Part Number 523-901-143-6RFX
J3: 53261-0471; Molex_PicoBlade_53261-0471_1x04-1MP_P1.25mm_Horizontal; MPN 53261-0471
J4: 504050-0691; Molex_Pico-Lock_504050-0691_1x06-1MP_P1.50mm_Horizontal; MPN 504050-0691
J8, J9: ESQ-126-69-G-D; MPN ESQ-126-69-G-D
R1: 1M; R_0603_1608Metric; MPN ERJ-PA3F1004V
R2, R3, R4, R5, R41, R42, R43: 0; R_0402_1005Metric; MPN ERJ-2GE0R00X; Mouser Part Number 667-ERJ-H2G0R00X
TP5: 5V; TestPoint_Pad_D1.0mm
TP6: 3V3; TestPoint_Pad_D1.0mm
TP7: USB_D+; TestPoint_Pad_D1.0mm
TP8: USB_D-; TestPoint_Pad_D1.0mm
U1: USBLC6-2SC6; SOT-23-6; MPN USBLC6-4SC6

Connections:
+3V3: H2.27, H2.28, TP6.1; also elsewhere on the board
+5V: H2.25, H2.26, J4.6, TP5.1; also elsewhere on the board
+5VP: F1.2, U1.5 (VBUS)
/3V3_Protected: R41.2; also elsewhere on the board
/+3V3_LUP: H1.48
/+5V_LUP: H1.51
/BCR_Out: H2.41, H2.42, H2.43, H2.44
/BattRaw: H2.45, H2.46
/EPS_0: H2.12
/EPS_1: H2.14
/EPS_5V_USB: H1.32
/EPS_RESET: H1.28
/Out1 (EPS): H2.3
/Out2 (EPS): H2.4
/Out3 (EPS): H2.5
/Out4 (EPS): H2.6
/Out5 (EPS): H2.7
/Out6 (EPS): H2.8
/PAPowerSwitch/Vin: R42.2; also elsewhere on the board
/PAPowerSwitch/Vout: R43.2; also elsewhere on the board
/PASwitch/5V: R43.1; also elsewhere on the board
/PAYLOAD_OC: H2.17
/PAYLOAD_ON_A: H2.16
/PAYLOAD_ON_B: H2.18
/PAYLOAD_ON_C: H2.20
/PAYLOAD_RXD+: H1.5; also elsewhere on the board
/PAYLOAD_RXD-: H1.7; also elsewhere on the board
/PAYLOAD_TXD+: H1.6; also elsewhere on the board
/PAYLOAD_TXD-: H1.8; also elsewhere on the board
/PLD_SCLK: H1.47
/PLD_SDA: H1.45
/Power_SCLK: H1.43
/Power_SDA: H1.41
/RADIO_RXD+: H1.10; also elsewhere on the board
/RADIO_RXD-: H1.12; also elsewhere on the board
/RADIO_TXD+: H1.9; also elsewhere on the board
/RADIO_TXD-: H1.11; also elsewhere on the board
/RF: J2.1 (In); also elsewhere on the board
/RS485_A: H1.24
/RS485_B: H1.22
/Radio_SCLK: H1.39, J4.5
/Radio_SDA: H1.37, J4.4
/Release_A: J4.2; also elsewhere on the board
/Release_B: J4.1; also elsewhere on the board
/SHUTDOWN_A: H2.9
/SHUTDOWN_B: H2.11
/SHUTDOWN_C: H2.13
/STATES_A: H2.10
/STATES_B: H2.22
/STATES_C: H2.24
/USB_D+: J1.3 (D+), J3.2, TP7.1, U1.1 (I/O1), U1.6 (I/O1); also elsewhere on the board
/USB_D-: J1.2 (D-), J3.3, TP8.1, U1.3 (I/O2), U1.4 (I/O2); also elsewhere on the board
/V_RTC: H1.30
/eFuse3V3.sch/3V3_P: R41.1; also elsewhere on the board
/eFuse5V/5V_LUP: R42.1; also elsewhere on the board
/~RESET: J3.1; also elsewhere on the board
GND: C1.2, H1.3, H1.13, H1.38, H1.42, H1.46, H1.50, H2.15, H2.29, H2.30, H2.31, H2.32, H7.1, H8.1, H9.1, H10.1, J1.5 (GND), J2.2 (Ext), J3.4, J3.MP (MountPin), J4.3, J4.MP, R1.2, R2.2, R3.2, R4.2, R5.2, U1.2 (GND); also elsewhere on the board
unnamed: H3.1, R2.1
unnamed: H4.1, R3.1
unnamed: H5.1, R4.1
unnamed: H6.1, R5.1
unnamed: C1.1, J1.6 (Shield), R1.1
unnamed: F1.1, J1.1 (VBUS)

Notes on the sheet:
SCIC
+5VP is the power from the USB bus
Board Mounting Holes
A 0Ω resistor can be installed to ground the holes
Antenna Interface
See Figure 15 in AX5043 Datasheet
iq = 1.1mA
bring PWRAMP out to test header, but can be removed if needed for space
imax ~ 48mA(TBD)
See FP2004 datasheet (and test results): OC3V3 is active LOW Probably don't care because result is not latched. OC5V is also active low
place close to PA
Avionics Interface Note: Avionics did not cross, so we have to cross is done after driver, at H1
Heat Spreader Mount
Need to add a V to 3.3V Regulator here Connect VBUS to EPS? Need to rethink what will be done using USB power ...USB may not source enough for PA. USB is used to talk to SAMD21, and possibly (if not using SWD) reprogram the SAMD21. 5V is NOT used to power the PA. PA 5V supply must be supplied exter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
We're never going to be a host, so just leave ID floating
For Pullup
For next revision: Bring out TxD2/RxD2, TxD1/RxD1, TxD0/RxD0 on separate headers. Make them compatible with FTDI USB cables. Make sure there's an easy way to tristate the serial drivers. Note that the SAMD21 is not 5V tolerant, so it might be good to add buffers to protect the part. Also note that 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
Payload interface Note: Payload did cross, so we don't
EPS_5V_USB does not exist on EPS
Serial port net names are the same as used by Avionics.
Consider TL1963A for LDO if we want to power SAMD21 via USB. It has reverse current and voltage protection. (i.e. its output can be directly connected to +3.3V)
imax ~ 20mA(TBD)?

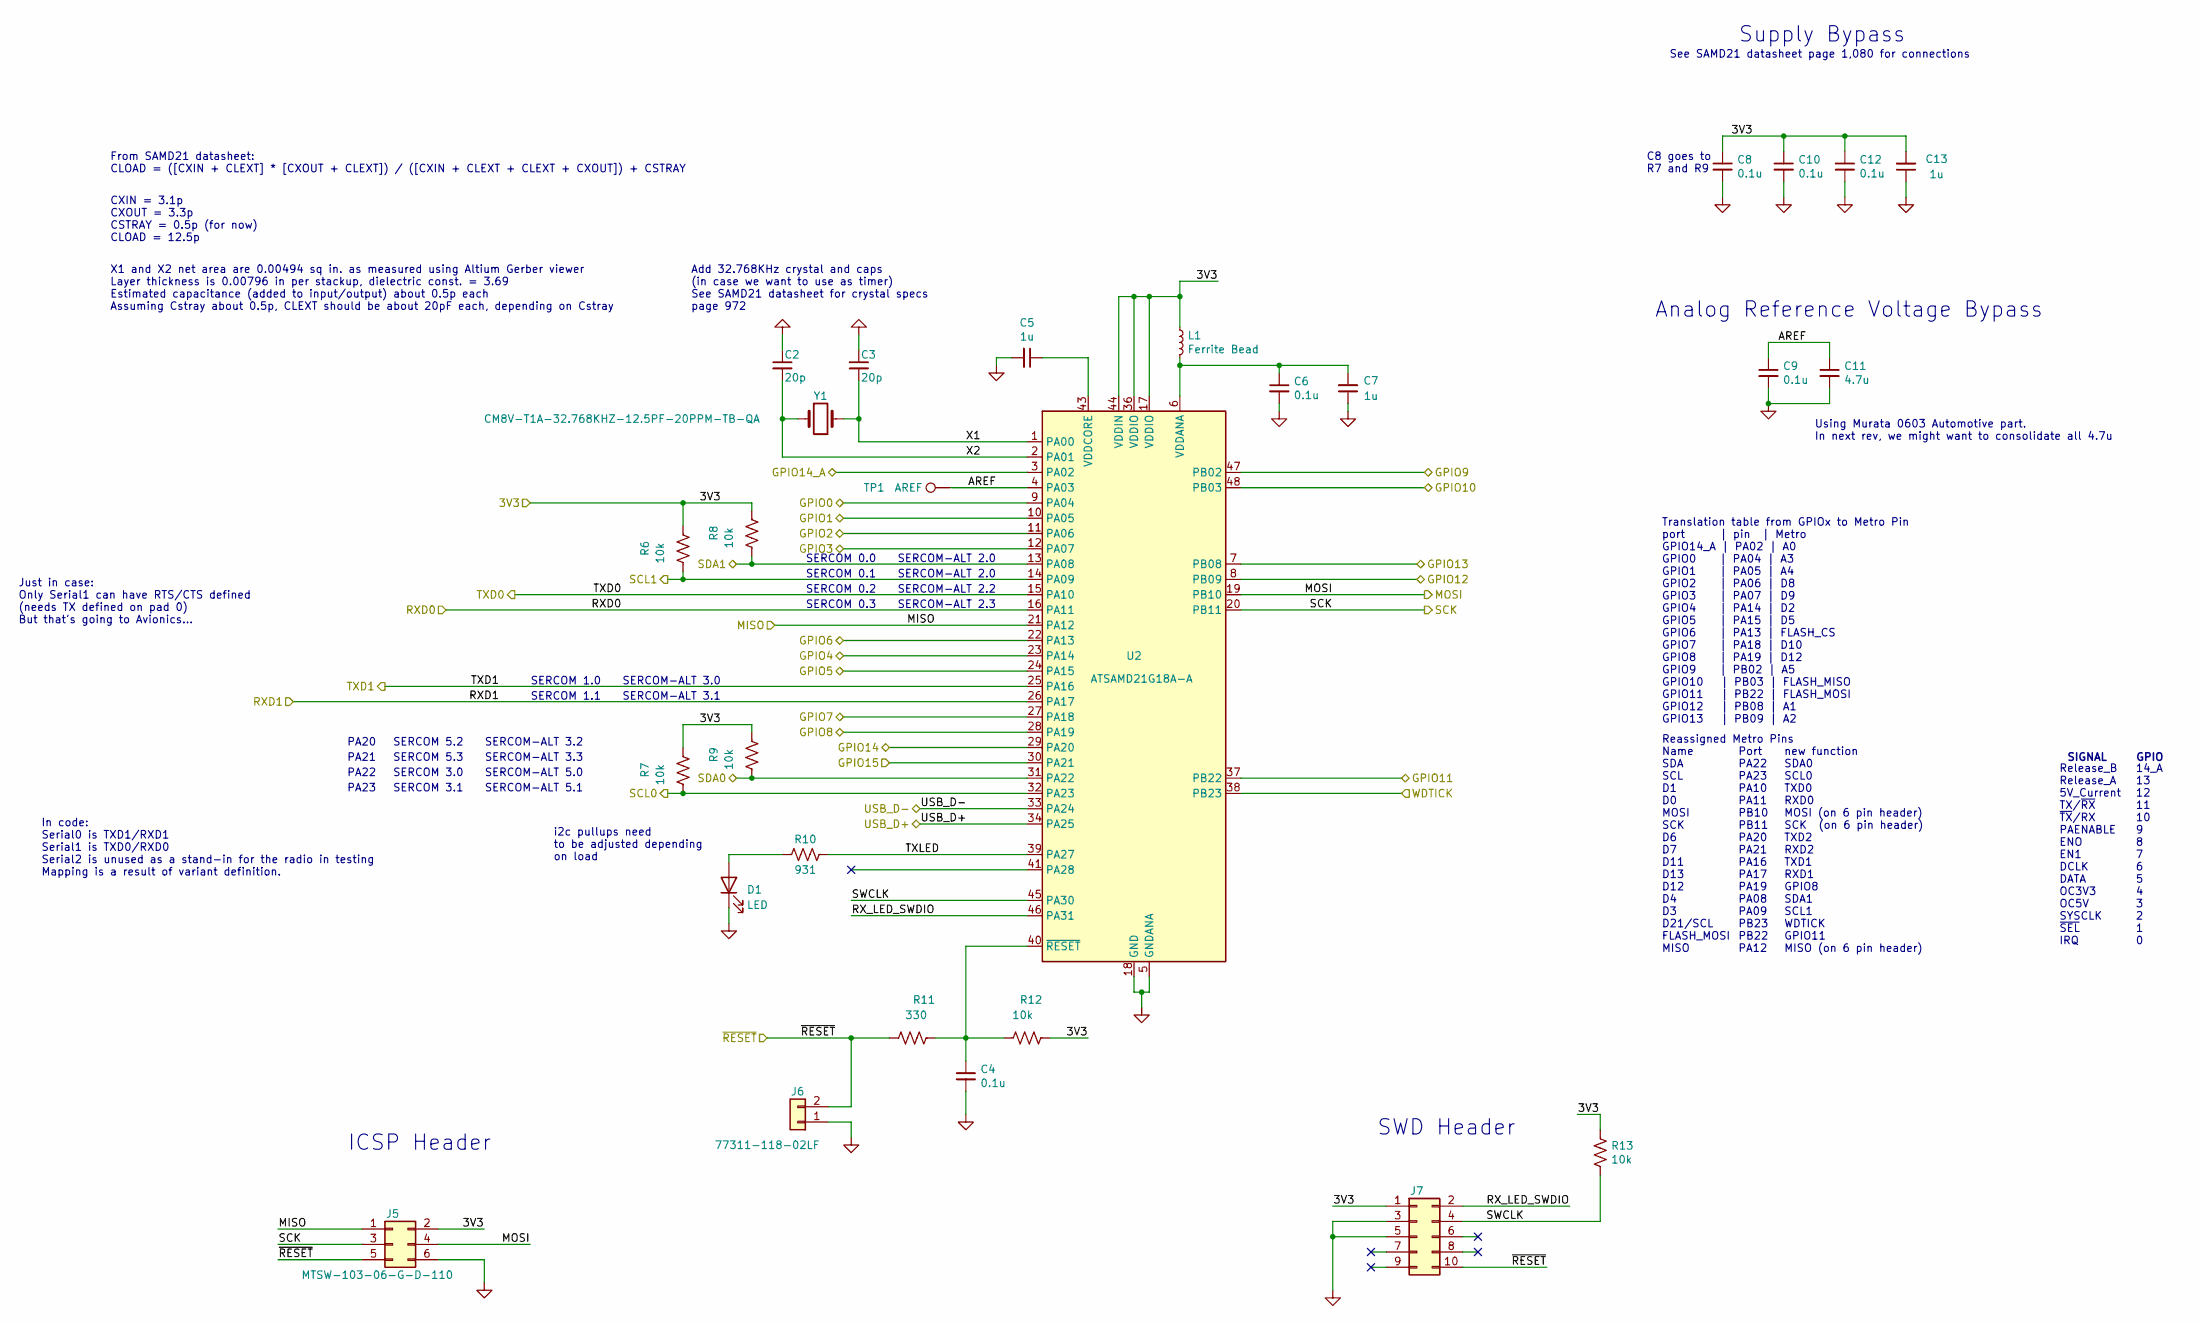
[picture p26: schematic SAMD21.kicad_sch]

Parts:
C2, C3: 20p; C_0603_1608Metric; MPN 06031A200K4T2A
C4, C6, C8, C9, C10, C12: 0.1u; C_0603_1608Metric; MPN 06031C104K4Z2A
C5, C7, C13: 1u; C_0805_2012Metric; Part_Number 12065C105M4Z2A; Mouser Part Number 581-08053C105K4Z2A
C11: 4.7u; C_0603_1608Metric; MPN GRT188C81C475KE13D
D1: LED; LED_D3.0mm_Horizontal_O1.27mm_Z2.0mm
J5: MTSW-103-06-G-D-110; PinHeader_2x03_P2.54mm_Vertical; MPN MTSW-103-06-G-D-110
J6: 77311-118-02LF; PinHeader_1x02_P2.54mm_Vertical; MPN 77311-118-02LF
J7: PinHeader_2x05_P1.27mm_Vertical_SMD; Part_Number 4048
L1: Ferrite Bead; L_0603_1608Metric; Part_Number BLM18SP102SH1D
R6, R7, R8, R9, R12, R13: 10k; R_0603_1608Metric; MPN ERJ-3RBD1002V
R10: 931; R_0603_1608Metric; Part_Number ERJ-3EKF9310V
R11: 330; R_0603_1608Metric; MPN ERJ-H3EF3300V
TP1: AREF; TestPoint_Pad_D1.0mm
U2: ATSAMD21G18A-A; TQFP-48_7x7mm_P0.5mm; MPN ATSAMD21G18A-AF
Y1: CM8V-T1A-32.768KHZ-12.5PF-20PPM-TB-QA; Crystal_SMD_MicroCrystal_CC8V-T1A-2Pin_2.0x1.2mm; Manufacturer_Part_Number CM8V-T1A-32.768KHZ-12.5PF-20PPM-TB-QA

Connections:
/3V3_Protected: C8.1, C10.1, C12.1, C13.2, J5.2, J7.1, L1.1, R6.1, R7.1, R8.1, R9.1, R12.1, R13.1, U2.17 (VDDIO), U2.36 (VDDIO), U2.44 (VDDIN); also elsewhere on the board
/5V_Current: U2.8 (PB09); also elsewhere on the board
/DATA: U2.24 (PA15); also elsewhere on the board
/DCLK: U2.22 (PA13); also elsewhere on the board
/EN0: U2.28 (PA19); also elsewhere on the board
/EN1: U2.27 (PA18); also elsewhere on the board
/ExternalWatchdog/WDTICK: U2.38 (PB23); also elsewhere on the board
/IRQ: U2.9 (PA04); also elsewhere on the board
/MISO: J5.1, U2.21 (PA12); also elsewhere on the board
/MOSI: J5.4, U2.19 (PB10); also elsewhere on the board
/OC5V: U2.12 (PA07); also elsewhere on the board
/PAENABLE: U2.47 (PB02); also elsewhere on the board
/RXD0: U2.16 (PA11); also elsewhere on the board
/RXD1: U2.26 (PA17); also elsewhere on the board
/Release_A: U2.7 (PB08); also elsewhere on the board
/Release_B: U2.3 (PA02); also elsewhere on the board
/SAMD21/AREF: C9.1, C11.1, TP1.1, U2.4 (PA03)
/SAMD21/GPIO4: U2.23 (PA14)
/SAMD21/GPIO14: U2.29 (PA20)
/SAMD21/GPIO15: U2.30 (PA21)
/SAMD21/RX_LED_SWDIO: J7.2, U2.46 (PA31)
/SAMD21/SCL1: R6.2, U2.14 (PA09)
/SAMD21/SDA1: R8.2, U2.13 (PA08)
/SAMD21/SWCLK: J7.4, R13.2, U2.45 (PA30)
/SAMD21/TXLED: R10.2, U2.39 (PA27)
/SAMD21/X1: C3.2, U2.1 (PA00), Y1.2
/SAMD21/X2: C2.2, U2.2 (PA01), Y1.1
/SCK: J5.3, U2.20 (PB11); also elsewhere on the board
/SCL: R7.2, U2.32 (PA23); also elsewhere on the board
/SDA: R9.2, U2.31 (PA22); also elsewhere on the board
/SYSCLK: U2.11 (PA06); also elsewhere on the board
/TXD0: U2.15 (PA10); also elsewhere on the board
/TXD1: U2.25 (PA16); also elsewhere on the board
/TX/~RX: U2.37 (PB22); also elsewhere on the board
/USB_D+: U2.34 (PA25); also elsewhere on the board
/USB_D-: U2.33 (PA24); also elsewhere on the board
/~RESET: J5.5, J6.2, J7.10, R11.2; also elsewhere on the board
/~SEL: U2.10 (PA05); also elsewhere on the board
/~TX/RX: U2.48 (PB03); also elsewhere on the board
GND: C2.1, C3.1, C4.2, C5.2, C6.2, C7.1, C8.2, C9.2, C10.2, C11.2, C12.2, C13.1, D1.1 (K), J5.6, J6.1, J7.3, J7.5, U2.5 (GNDANA), U2.18 (GND), U2.35 (GND), U2.42 (GND); also elsewhere on the board
unnamed: D1.2 (A), R10.1
unnamed: C6.1, C7.2, L1.2, U2.6 (VDDANA)
unnamed: C5.1, U2.43 (VDDCORE)
unnamed: C4.1, R11.1, R12.2, U2.40 (~RESET)

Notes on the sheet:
PA23
Add 32.768KHz crystal and caps (in case we want to use as timer) See SAMD21 datasheet for crystal specs page 972
i2c pullups need to be adjusted depending on load
PA22
SERCOM 3.0
See SAMD21 datasheet page 1,080 for connections
SERCOM-ALT 2.2
SERCOM-ALT 5.0
SERCOM 5.3
SERCOM-ALT 5.1
Reassigned Metro Pins Name SDA SCL D1 D0 MOSI SCK D6 D7 D11 D13 D12 D4 D3 D21/SCL FLASH_MOSI MISO
Just in case: Only Serial1 can have RTS/CTS defined (needs TX defined on pad 0) But that's going to Avionics...
SERCOM-ALT 2.3
X1 and X2 net area are 0.00494 sq in. as measured using Altium Gerber viewer Layer thickness is 0.00796 in per stackup, dielectric const. = 3.69 Estimated capacitance (added to input/output) about 0.5p each Assuming Cstray about 0.5p, CLEXT should be about 20pF each, depending on Cstray
SERCOM 0.1
SERCOM 5.2
SERCOM 0.3
GPIO
Supply Bypass
SERCOM 0.2
SERCOM-ALT 3.0
CXIN = 3.1p CXOUT = 3.3p CSTRAY = 0.5p (for now) CLOAD = 12.5p
From SAMD21 datasheet: CLOAD = ([CXIN + CLEXT] * [CXOUT + CLEXT]) / ([CXIN + CLEXT + CLEXT + CXOUT]) + CSTRAY
C8 goes to R7 and R9
SERCOM 3.1
Using Murata 0603 Automotive part. In next rev, we might want to consolidate all 4.7u
SWD Header
SERCOM 0.0
SERCOM-ALT 3.2
new function SDA0 SCL0 TXD0 RXD0 MOSI (on 6 pin header) SCK (on 6 pin header) TXD2 RXD2 TXD1 RXD1 GPIO8 SDA1 SCL1 WDTICK GPIO11 MISO (on 6 pin header)
ICSP Header
Release_B Release_A 5V_Current TX/~{RX} ~{TX}/RX PAENABLE ENO EN1 DCLK DATA OC3V3 OC5V SYSCLK ~{SEL} IRQ
SERCOM-ALT 3.1
SIGNAL
In code: Serial0 is TXD1/RXD1 Serial1 is TXD0/RXD0 Serial2 is unused as a stand-in for the radio in testing Mapping is a result of variant definition.
14_A 13 12 11 10 9 8 7 6 5 4 3 2 1 0
PA21
Analog Reference Voltage Bypass
Translation table from GPIOx to Metro Pin port | pin | Metro GPIO14_A | PA02 | A0 GPIO0 | PA04 | A3 GPIO1 | PA05 | A4 GPIO2 | PA06 | D8 GPIO3 | PA07 | D9 GPIO4 | PA14 | D2 GPIO5 | PA15 | D5 GPIO6 | PA13 | FLASH_CS GPIO7 | PA18 | D10 GPIO8 | PA19 | D12 GPIO9 | PB02 | A5 GPIO10 | PB03 | FLASH_MISO GP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
SERCOM-ALT 2.0

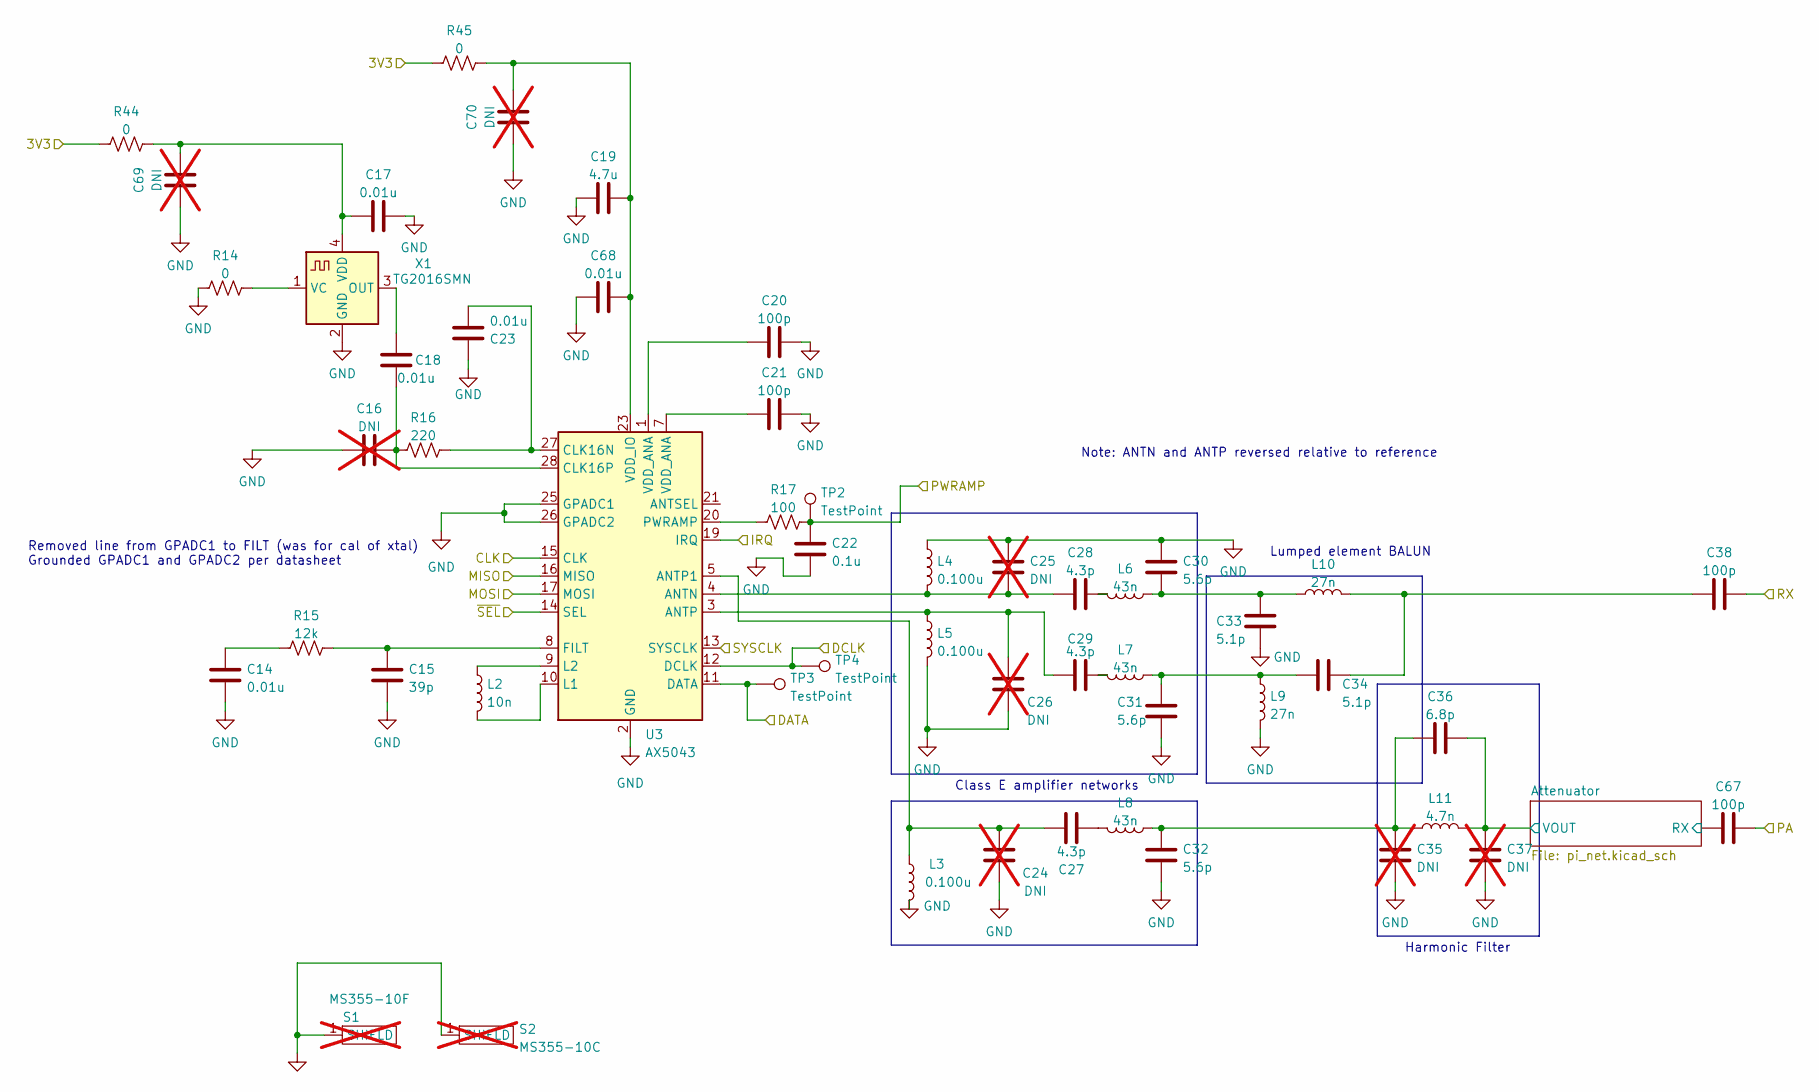
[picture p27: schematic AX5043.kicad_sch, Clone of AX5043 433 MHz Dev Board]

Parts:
C14, C17, C18, C68: 0.01u; C_0603_1608Metric; Manufacturer_Part_Number 06033C103J4Z2A; Mouser Part Number 581-06033C103J4Z2A
C15: 39p; C_0402_1005Metric; MPN GRT1555C1H390FA02D; Mouser Part Number 581-06035A390J4T2A
C16, C24, C25, C26, C35, C37, C69, C70: DNI; C_0402_1005Metric; not fitted
C19: 4.7u; C_0603_1608Metric; MPN GRT188C81C475KE13D; Mouser Part Number 581-12065C475K4Z2A
C20, C21: 100p; C_0402_1005Metric; MPN GCM1555C1H101FA16J; Mouser Part Number -- mixed values --
C22: 0.1u; C_0603_1608Metric; MPN 06031C104K4Z2A
C23: 0.01u; C_0603_1608Metric; MPN 06033C103J4Z2A
C27, C28, C29: 4.3p; C_0402_1005Metric; MPN GCM1555C1H4R3BA16D; Mouser Part Number 581-04023A4R7B4T2A
C30, C31, C32: 5.6p; C_0402_1005Metric; MPN 04025U5R6B4T2A; Mouser Part Number 581-04025U5R6B4T2A
C33, C34: 5.1p; C_0402_1005Metric; MPN GCQ1555C1H5R1WB01D; Mouser Part Number 81-GCQ1555C1H5R1WB01D
C36: 6.8p; C_0402_1005Metric; MPN GCM1555C1H6R8BA16D; Mouser Part Number 581-04025U6R8B4T2A
C38, C67: 100p; C_0402_1005Metric; MPN GCM1555C1H101FA16J; Mouser Part Number 581-04025A101K4T2A
L2: 10n; L_0603_1608Metric; MPN 0603DC-10NXJRW; Mouser Part Number 994-0603DC-10NXJRW
L3, L4, L5: 0.100u; Coilcraft_L_0402_1005Metric; MPN 0402DC-R10XJRW; Mouser Part Number 994-0402DC-R10XJRW
L6, L7, L8: 43n; Coilcraft_L_0402_1005Metric; MPN 0402DC-43NXGRW; Mouser Part Number 994-0402DC-43NXGRW
L9, L10: 27n; Coilcraft_L_0402_1005Metric; MPN 0402DC-27NXGRW; Mouser Part Number 994-0402DC-27NXGRW
L11: 4.7n; Coilcraft_L_0402_1005Metric; MPN 0402DC-4N7XGRW; Mouser Part Number 994-0402DC-4N7XGRW
R14, R44, R45: 0; R_0402_1005Metric; MPN ERJ-2GE0R00X; Mouser Part Number 667-ERJ-H2G0R00X
R15: 12k; R_0603_1608Metric; MPN ERJ-3RBD123V; Mouser Part Number 667-ERJ-PB3B1202V
R16: 220; R_0603_1608Metric; MPN ERJ-PB3D2200V
R17: 100; R_0603_1608Metric; MPN ERJ-3RBD101V; Mouser Part Number 667-ERJ-H3ED1000V
S1: MS355-10F_Masach_Shield; MS355-10_Masach_Shield; MPN MS355-10F; not fitted
S2: MS355-10C_Masach_Shield_Cover; MPN MS355-10C; not fitted
TP2, TP3, TP4: TestPoint; TestPoint_Pad_D1.0mm
U3: AX5043; QFN-28-1EP_5x5mm_P0.5mm_EP3.35x3.35mm; Mouser Part Number 863-AX5043-1-TW30
X1: TG2016SMN; Crystal_SMD_2016-4Pin_2.0x1.6mm; Voltage 3.3; MPN TG2016SMN 48.0000M-MCGNNM3

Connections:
/3V3_Protected: R44.1, R45.1; also elsewhere on the board
/AX5043/Attenuator/RX: C67.1; also elsewhere on the board
/AX5043/Attenuator/VOUT: C36.2, C37.1, L11.2; also elsewhere on the board
/DATA: TP3.1, U3.11 (DATA); also elsewhere on the board
/DCLK: TP4.1, U3.12 (DCLK); also elsewhere on the board
/IRQ: U3.19 (IRQ); also elsewhere on the board
/MISO: U3.16 (MISO); also elsewhere on the board
/MOSI: U3.17 (MOSI); also elsewhere on the board
/PA: C67.2; also elsewhere on the board
/PWRAMP: C22.1, R17.2, TP2.1
/RX: C38.2; also elsewhere on the board
/SCK: U3.15 (CLK); also elsewhere on the board
/SYSCLK: U3.13 (SYSCLK); also elsewhere on the board
/~SEL: U3.14 (SEL); also elsewhere on the board
GND: C14.2, C15.2, C16.1, C17.2, C19.1, C20.2, C21.2, C22.2, C23.1, C24.1, C25.1, C26.2, C30.1, C31.2, C32.2, C33.2, C35.2, C37.2, C68.1, C69.1, C70.1, L3.1, L4.1, L5.2, L9.2, R14.1, S1.1 (SHIELD), S2.1, U3.2 (GND), U3.6 (GND), U3.25 (GPADC1), U3.26 (GPADC2), U3.29 (GND), X1.2 (GND); also elsewhere on the board
unnamed: C14.1, R15.1
unnamed: C20.1, U3.1 (VDD_ANA)
unnamed: C21.1, U3.7 (VDD_ANA)
unnamed: C27.2, L8.2
unnamed: C28.2, L6.1
unnamed: C29.1, L7.1
unnamed: C30.2, C33.1, L6.2, L10.1
unnamed: C31.1, C34.2, L7.2, L9.1
unnamed: C32.1, C35.1, C36.1, L8.1, L11.1
unnamed: C34.1, C38.1, L10.2
unnamed: C25.2, C28.1, L4.2, U3.4 (ANTN)
unnamed: C24.2, C27.1, L3.2, U3.5 (ANTP1)
unnamed: C26.1, C29.2, L5.1, U3.3 (ANTP)
unnamed: C23.2, R16.2, U3.27 (CLK16N)
unnamed: C16.2, C18.2, R16.1, U3.28 (CLK16P)
unnamed: C15.1, R15.2, U3.8 (FILT)
unnamed: L2.2, U3.10 (L1)
unnamed: L2.1, U3.9 (L2)
unnamed: R17.1, U3.20 (PWRAMP)
unnamed: C19.2, C68.2, C70.2, R45.2, U3.23 (VDD_IO)
unnamed: C18.1, X1.3 (OUT)
unnamed: R14.2, X1.1 (VC)
unnamed: C17.1, C69.2, R44.2, X1.4 (VDD)

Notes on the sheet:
Note: ANTN and ANTP reversed relative to reference
Removed line from GPADC1 to FILT (was for cal of xtal) Grounded GPADC1 and GPADC2 per datasheet
Harmonic Filter
Class E amplifier networks
Lumped element BALUN

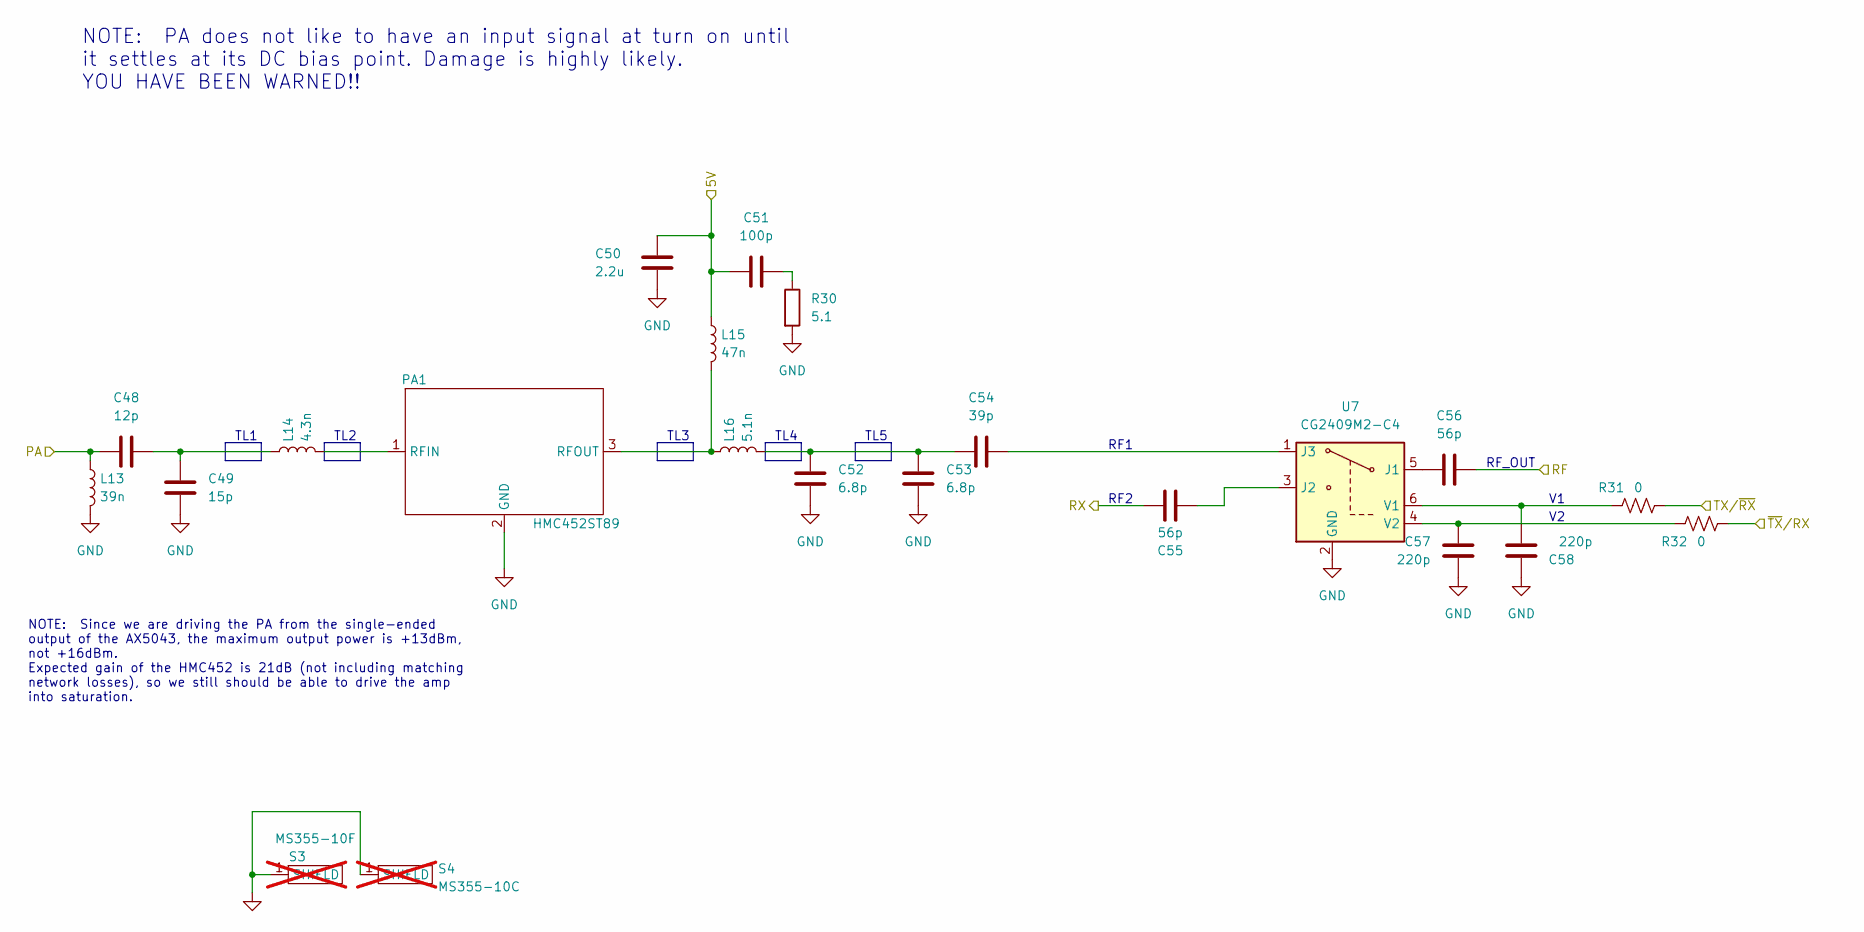
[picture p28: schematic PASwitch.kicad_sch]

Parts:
C48: 12p; C_0402_1005Metric; MPN 04025A120F4T2A
C49: 15p; C_0402_1005Metric; MPN GRT1555C1H150FA02D
C50: 2.2u; C_1210_3225Metric; MPN C1210C225K1RACAUTO
C51: 100p; C_0402_1005Metric; MPN GCM1555C1H101FA16J
C52, C53: 6.8p; C_0402_1005Metric; MPN GCM1555C1H6R8BA16D
C54: 39p; C_0402_1005Metric; MPN GRT1555C1H390FA02D
C55, C56: 56p; C_0402_1005Metric; MPN GCM1555C1H560FA16D
C57, C58: 220p; C_0402_1005Metric; MPN GRT1555C1H221FA02D
L13: 39n; Coilcraft_L_0402_1005Metric; MPN 0402DC-39NXGRW
L14: 4.3n; Coilcraft_L_0402_1005Metric; MPN 0402DC-4N3XGRW
L15: 47n; Coilcraft_L_0402_1005Metric; MPN 0402DC-47NXGRW
L16: 5.1n; Coilcraft_L_0402_1005Metric; MPN 0402DC-5N1XGRW
PA1: HMC452ST89; MPN HMC452ST89
R30: 5.1; R_0603_1608Metric; MPN ERJ-U03F5R10V
R31, R32: 0; R_0402_1005Metric; MPN ERJ-2GE0R00X; Mouser Part Number 667-ERJ-H2G0R00X
S3: MS355-10F_Masach_Shield; MS355-10_Masach_Shield; MPN MS355-10F; not fitted
S4: MS355-10C_Masach_Shield_Cover; SilverSat_logo_15x7.75mm; MPN MS355-10C; not fitted
U7: CG2409M2-C4; SOT-363_SC-70-6; MPN CG2409M2-C4

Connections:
/PA: C48.2, L13.1; also elsewhere on the board
/PASwitch/5V: C50.1, C51.2, L15.1; also elsewhere on the board
/RF: C56.2; also elsewhere on the board
/RX: C55.1; also elsewhere on the board
/TX/~RX: R31.2; also elsewhere on the board
/~TX/RX: R32.2; also elsewhere on the board
GND: C49.2, C50.2, C52.2, C53.2, C57.1, C58.2, L13.2, PA1.2 (GND), R30.2, S3.1 (SHIELD), S4.1, U7.2 (GND); also elsewhere on the board
unnamed: C48.1, C49.1, L14.1
unnamed: C51.1, R30.1
unnamed: C52.1, C53.1, C54.2, L16.2
unnamed: L14.2, PA1.1 (RFIN)
unnamed: L15.2, L16.1, PA1.3 (RFOUT)
unnamed: C56.1, U7.5 (J1)
unnamed: C55.2, U7.3 (J2)
unnamed: C54.1, U7.1 (J3)
unnamed: C58.1, R31.1, U7.6 (V1)
unnamed: C57.2, R32.1, U7.4 (V2)

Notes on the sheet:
TL5
NOTE: Since we are driving the PA from the single-ended output of the AX5043, the maximum output power is +13dBm, not +16dBm. Expected gain of the HMC452 is 21dB (not including matching network losses), so we still should be able to drive the amp into saturation.
NOTE: PA does not like to have an input signal at turn on until it settles at its DC bias point. Damage is highly likely. YOU HAVE BEEN WARNED!!
TL4
TL1
TL2
RF2
RF_OUT
TL3
RF1

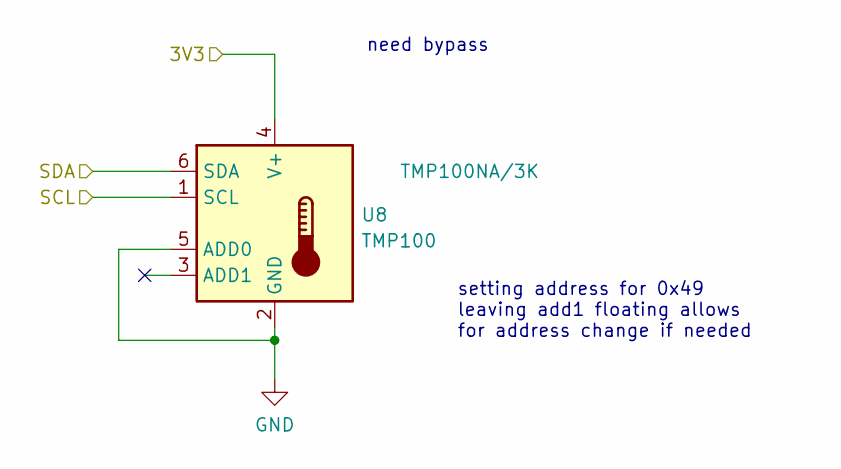
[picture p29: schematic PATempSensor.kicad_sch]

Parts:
U8: TMP100; SOT-23-6; MPN TMP100NA/3K

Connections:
/3V3_Protected: U8.4 (V+); also elsewhere on the board
/SCL: U8.1 (SCL); also elsewhere on the board
/SDA: U8.6 (SDA); also elsewhere on the board
GND: U8.2 (GND), U8.5 (ADD0); also elsewhere on the board

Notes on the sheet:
setting address for 0x49 leaving add1 floating allows for address change if needed
need bypass

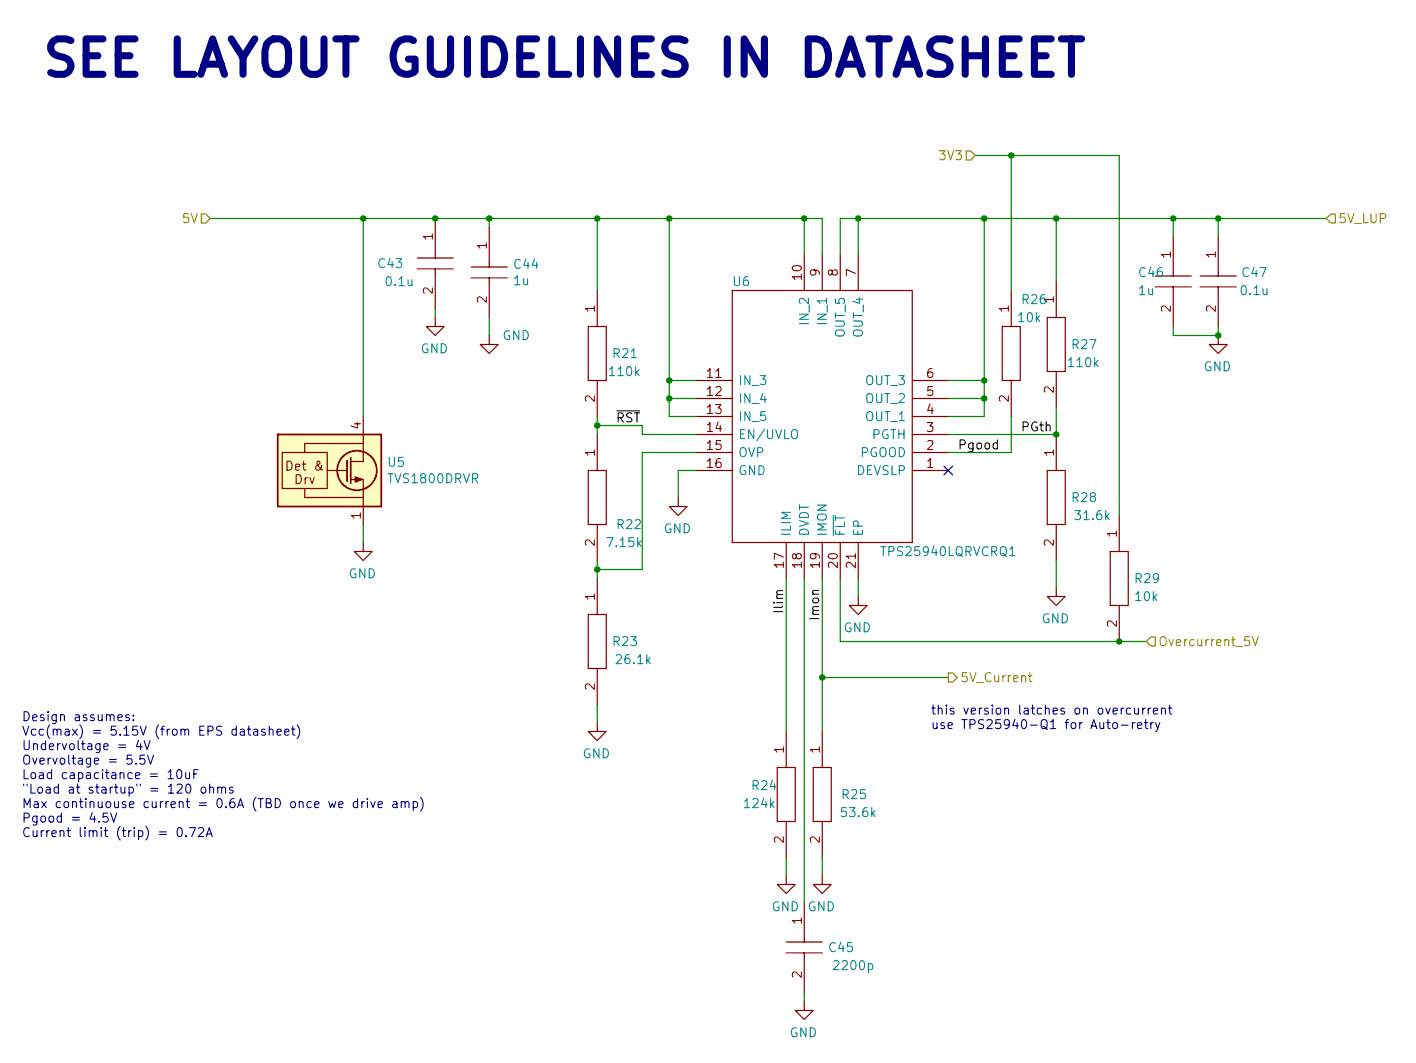
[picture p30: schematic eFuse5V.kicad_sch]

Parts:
C43, C47: 0.1u; C_0603_1608Metric; Manufacturer_Part_Number 06031C104K4Z2A; Mouser Part Number 581-06031C104K4Z2A
C44, C46: 1u; C_0805_2012Metric; Manufacturer_Part_Number 08053C105K4Z2A; Mouser Part Number 581-08053C105K4Z2A
C45: 2200p; C_0603_1608Metric; MPN GCM1885C1H222FA16D
R21, R27: 110k; R_0603_1608Metric; MPN ERJ-H3EF1103V
R22: 7.15k; R_0603_1608Metric; MPN ERJ-3EKF7151V
R23: 26.1k; R_0603_1608Metric; MPN ERJ-PB3D2612V
R24: 124k; R_0603_1608Metric; MPN ERJ-3EKF1243V
R25: 53.6k; R_0603_1608Metric; MPN ERJ-3EKF5362V
R26: 10k; R_0603_1608Metric; Manufacturer_Part_Number CRCW040210K0DHEDP
R28: 31.6k; R_0603_1608Metric; MPN ERJ-3EKF3162V
R29: 10k; R_0603_1608Metric; MPN ERJ-3RBD1002V
U5: TVS1800DRVR; WSON-6-1EP_2x2mm_P0.65mm_EP1x1.6mm; MPN TVS1800DRVR; Mouser Part Number 595-TVS1800DRVR
U6: TPS25940LQRVCRQ1; QFN-20-1EP_3x4mm_P0.5mm_EP1.65x2.65mm_ThermalVias; Manufacturer_Part_Number TPS25940LQRVCRQ1; Mouser Part Number 595-TPS25940LQRVCRQ1

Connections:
+5V: C43.1, C44.1, R21.1, U5.4 (IN), U5.5 (IN), U5.6 (IN), U6.9 (IN_1), U6.10 (IN_2), U6.11 (IN_3), U6.12 (IN_4), U6.13 (IN_5); also elsewhere on the board
/3V3_Protected: R26.1, R29.1; also elsewhere on the board
/5V_Current: R25.1, U6.19 (IMON); also elsewhere on the board
/OC5V: R29.2, U6.20 (~FLT); also elsewhere on the board
/eFuse5V/5V_LUP: C46.1, C47.1, R27.1, U6.4 (OUT_1), U6.5 (OUT_2), U6.6 (OUT_3), U6.7 (OUT_4), U6.8 (OUT_5); also elsewhere on the board
/eFuse5V/Ilim: R24.1, U6.17 (ILIM)
/eFuse5V/PGth: R27.2, R28.1, U6.3 (PGTH)
/eFuse5V/Pgood: R26.2, U6.2 (PGOOD)
/eFuse5V/~RST: R21.2, R22.1, U6.14 (EN/UVLO)
GND: C43.2, C44.2, C45.2, C46.2, C47.2, R23.2, R24.2, R25.2, R28.2, U5.1 (GND), U5.2 (GND), U5.3 (GND), U5.7 (GND), U6.16 (GND), U6.21 (EP); also elsewhere on the board
unnamed: C45.1, U6.18 (DVDT)
unnamed: R22.2, R23.1, U6.15 (OVP)

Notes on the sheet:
this version latches on overcurrent use TPS25940-Q1 for Auto-retry
Design assumes: Vcc(max) = 5.15V (from EPS datasheet) Undervoltage = 4V Overvoltage = 5.5V Load capacitance = 10uF "Load at startup" = 120 ohms Max continuouse current = 0.6A (TBD once we drive amp) Pgood = 4.5V Current limit (trip) = 0.72A
SEE LAYOUT GUIDELINES IN DATASHEET

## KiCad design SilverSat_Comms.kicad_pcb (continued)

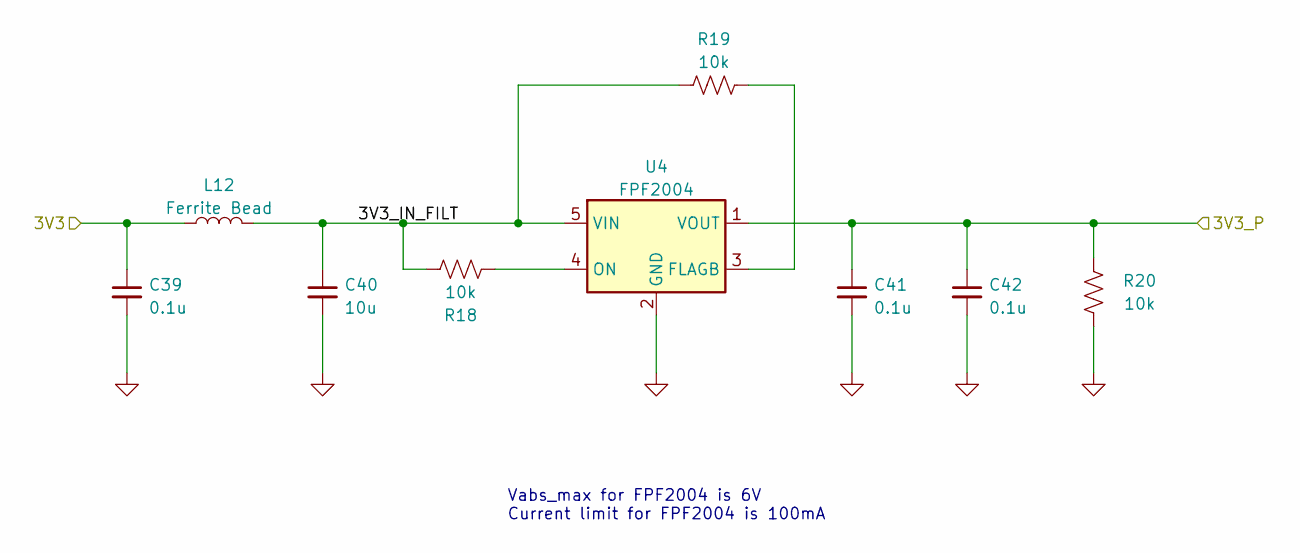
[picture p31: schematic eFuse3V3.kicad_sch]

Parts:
C39, C41, C42: 0.1u; C_0603_1608Metric; MPN 06031C104K4Z2A
C40: 10u; C_1210_3225Metric; Part_Number 12103C106K4Z2A
L12: Ferrite Bead; L_0603_1608Metric; Part_Number BLM18SP102SH1D
R18, R19, R20: 10k; R_0603_1608Metric; Part_Number ERJ-3EKF1002V
U4: FPF2004; SOT-353_SC-70-5; MPN FPF2004

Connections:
+3V3: C39.1, L12.1; also elsewhere on the board
/eFuse3V3.sch/3V3_IN_FILT: C40.1, L12.2, R18.1, R19.1, U4.5 (VIN)
/eFuse3V3.sch/3V3_P: C41.1, C42.1, R20.1, U4.1 (VOUT); also elsewhere on the board
GND: C39.2, C40.2, C41.2, C42.2, R20.2, U4.2 (GND); also elsewhere on the board
unnamed: R19.2, U4.3 (FLAGB)
unnamed: R18.2, U4.4 (ON)

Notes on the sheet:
Vabs_max for FPF2004 is 6V Current limit for FPF2004 is 100mA

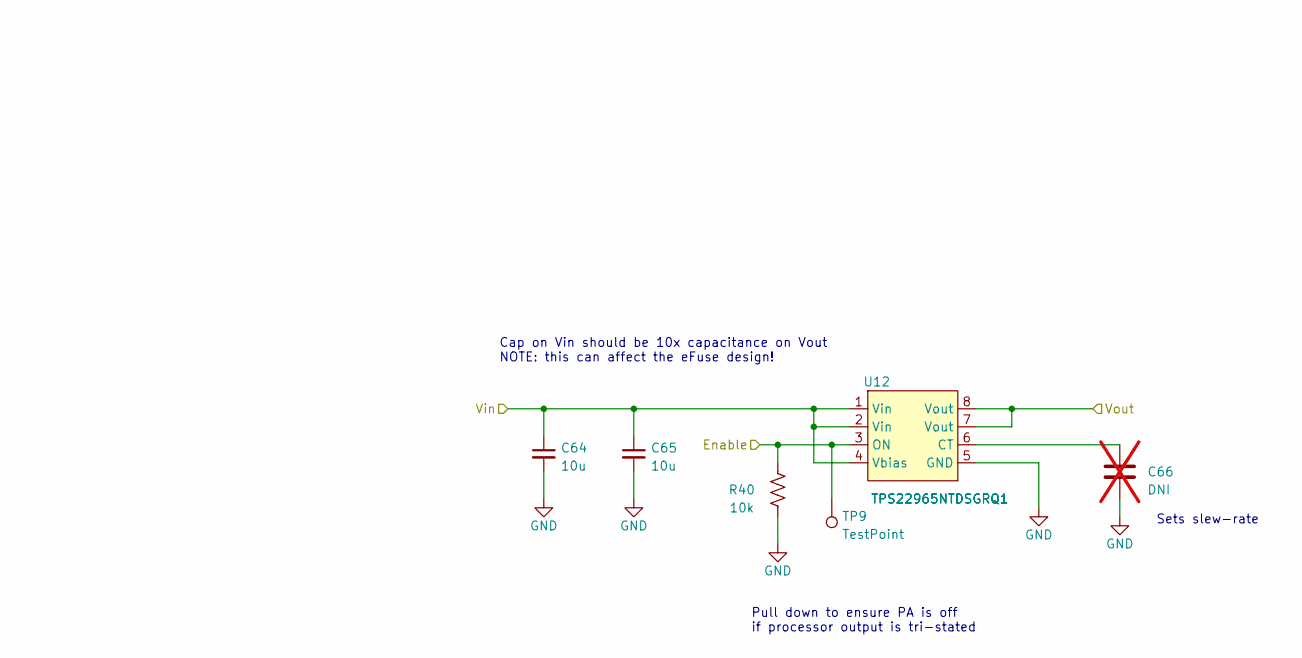
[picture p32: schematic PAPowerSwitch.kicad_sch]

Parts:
C64, C65: 10u; C_1210_3225Metric; Part_Number 12103C106K4Z2A
C66: DNI; C_0603_1608Metric; not fitted
R40: 10k; R_0603_1608Metric; MPN ERJ-3RBD1002V; Mouser Part Number 667-ERJ-PB3B1202V
TP9: TestPoint; TestPoint_Pad_D1.0mm
U12: TPS22965NTDSGRQ1; DFN-8-1EP_2.1x2.1mm_P0.5mmx0.25mm_EP0.8x1.6mm; MPN TPS22965NTDSGRQ1

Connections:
/PAENABLE: R40.2, TP9.1, U12.3 (ON); also elsewhere on the board
/PAPowerSwitch/Vin: C64.1, C65.1, U12.1 (Vin), U12.2 (Vin), U12.4 (Vbias); also elsewhere on the board
/PAPowerSwitch/Vout: U12.7 (Vout), U12.8 (Vout); also elsewhere on the board
GND: C64.2, C65.2, C66.1, R40.1, U12.5 (GND); also elsewhere on the board
unnamed: C66.2, U12.6 (CT)

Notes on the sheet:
Cap on Vin should be 10x capacitance on Vout NOTE: this can affect the eFuse design!
Pull down to ensure PA is off if processor output is tri-stated
Sets slew-rate

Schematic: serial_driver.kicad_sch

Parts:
C59, C60: 0.1u; C_0603_1608Metric; MPN 06031C104K4Z2A
R33: 10k; R_0603_1608Metric; MPN ERJ-3RBD1002V
R34: 453; R_0603_1608Metric; MPN ERJ-3EKF4530V
U9: SN65HVD70D; SOIC-14_3.9x8.7mm_P1.27mm; MPN SN65HVD70D

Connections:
/3V3_Protected: C59.2, U9.13 (Vcc), U9.14 (Vcc); also elsewhere on the board
/EN0: U9.4 (DE); also elsewhere on the board
/RADIO_RXD+: R34.1, U9.12 (A); also elsewhere on the board
/RADIO_RXD-: C60.2, U9.11 (B); also elsewhere on the board
/RADIO_TXD+: U9.9 (Y); also elsewhere on the board
/RADIO_TXD-: U9.10 (Z); also elsewhere on the board
/RXD1: U9.2 (R); also elsewhere on the board
/TXD1: U9.5 (D); also elsewhere on the board
GND: C59.1, R33.1, U9.6 (GND), U9.7 (GND); also elsewhere on the board
unnamed: C60.1, R34.2
unnamed: R33.2, U9.3 (RE)

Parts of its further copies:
C61, C62: 0.1u; C_0603_1608Metric; MPN 06031C104K4Z2A
R35: 10k; R_0603_1608Metric; MPN ERJ-3RBD1002V
R36: 453; R_0603_1608Metric; MPN ERJ-3EKF4530V
U10: SN65HVD70D; SOIC-14_3.9x8.7mm_P1.27mm; MPN SN65HVD70D

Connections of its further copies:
/3V3_Protected: C61.2, U10.13 (Vcc), U10.14 (Vcc); also elsewhere on the board
/EN1: U10.4 (DE); also elsewhere on the board
/PAYLOAD_RXD+: R36.1, U10.12 (A); also elsewhere on the board
/PAYLOAD_RXD-: C62.2, U10.11 (B); also elsewhere on the board
/PAYLOAD_TXD+: U10.9 (Y); also elsewhere on the board
/PAYLOAD_TXD-: U10.10 (Z); also elsewhere on the board
/RXD0: U10.2 (R); also elsewhere on the board
/TXD0: U10.5 (D); also elsewhere on the board
GND: C61.1, R35.1, U10.6 (GND), U10.7 (GND); also elsewhere on the board
unnamed: C62.1, R36.2
unnamed: R35.2, U10.3 (RE)

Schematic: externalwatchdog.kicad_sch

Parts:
C63: 0.1u; C_0603_1608Metric; MPN 06031C104K4Z2A
U11: TPS3813K33QDBVRQ1; SOT-23-6; MPN TPS3813K33QDBVRQ1

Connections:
/3V3_Protected: C63.1, U11.3 (WDT), U11.4 (Vdd), U11.5 (WDR); also elsewhere on the board
/ExternalWatchdog/WDTICK: U11.1 (WDI); also elsewhere on the board
/~RESET: U11.6 (RESET); also elsewhere on the board
GND: C63.2, U11.2 (GND); also elsewhere on the board

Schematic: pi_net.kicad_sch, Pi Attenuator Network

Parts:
R37, R39: 130; R_0402_1005Metric; Voltage 50; MPN ERJ-PA2F1300X
R38: 44.2; R_0402_1005Metric; MPN ERJ-2RKF44R2X; Mouser Part Number 667-ERJ-2RKF44R2X

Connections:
/AX5043/Attenuator/RX: R38.2, R39.2; also elsewhere on the board
/AX5043/Attenuator/VOUT: R37.2, R38.1; also elsewhere on the board
GND: R37.1, R39.1; also elsewhere on the board

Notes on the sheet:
Attenuation (dB) 0.0 1.0 2.0 3.0 4.0 5.0 6.0 7.0 8.0 9.0 10.0 11.0 12.0 13.0 14.0 15.0 R44 (ohms) 0.0 5.8 11.6 17.6 23.8 30.4 37.4 44.8 52.8 61.6 71.2 81.7 93.2 106.1 120.3 136.1 R43 & 45 (ohms) NC 869.5 436.2 292.4 221.0 178.5 150.5 130.7 116.1 105.0 96.2 89.2 83.5 78.8 74.9 71.6 Attenuation (dB) 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

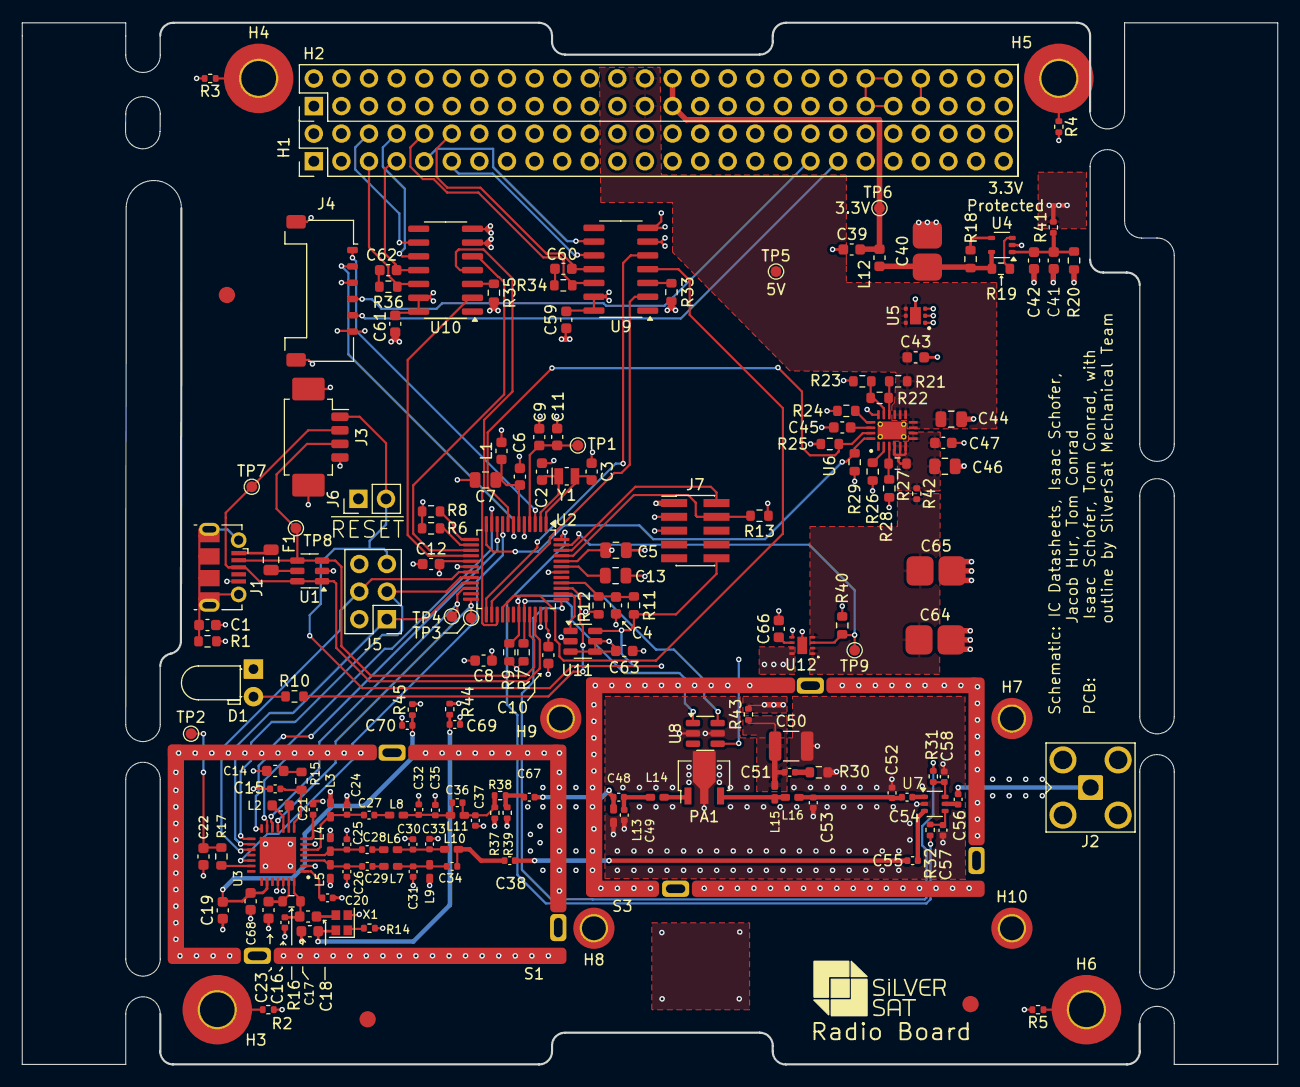
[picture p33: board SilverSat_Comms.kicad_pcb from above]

Board: 4 copper layers, 115.6 x 95.9 mm, 179 parts (0 on the bottom side), 120 nets.

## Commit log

2022-05-21 Initial commit and readme
    threw in some basic readme language and moved files from old repo to here
    [AX5043.kicad_sch, PASwitch.kicad_sch, PATempSensor.kicad_sch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]
2022-05-21 annotate and populate
    did a quick annotation and loaded the parts into the PCB to see where we're at.
    86 errors, so there's some work to do.
    [AX5043.kicad_sch, PATempSensor.kicad_sch, SAMD21.kicad_sch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]
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2022-05-22 USB connection
    Moved the connector back to the SAMD21 page. Moving it broke some local connections.
    [AX5043.kicad_sch, SAMD21.kicad_sch, SilverSat_Comms.kicad_sch]
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2022-05-23 Added TX-only antenna network Total Changes:
    Added TX-only antenna network from ADD5043 schematic.
    Changed TX/RX network component labels (e.g. CT1, LC1) to generic unannotated labels (e.g. C, L).
    Fixed bug in the TCXO connection/
    Added schematic name, citation to original OnSemi schematic, and author of KiCad port.
    Localization: Changed paper size from A4 to US Letter
    Unknown changes to eight other files, such as .zip file deletions and global chematic modifications
    [AX5043.kicad_sch, SilverSat_Comms.kicad_sch]
2022-05-23 Update AX5043.kicad_sch
    moved PA sheet connector to single ended TX output
    moved PWRAMP to output of PWRAMP pin on AX5043 (after low pass network)
    [AX5043.kicad_sch]
2022-05-23 Fixed TCXO footprint & missing C & L values
    [AX5043.kicad_sch]
2022-05-23 Fixed human error (forgot to click save) It appears that, upon last editing the AX5043 schematic, I lost changes after I forgot to save my work.
    [AX5043.kicad_sch, SilverSat_Comms.kicad_sch]
2022-05-24 annotated and did trial import
    Lots of parts need footprints assigned. LEDs are huge, but we aren't hurting for space.
    About 100 errors right now on import, mostly missing footprints.
    Parts just placed randomly on PCB, not optimized
    [AX5043.kicad_sch, SAMD21.kicad_sch, SilverSat_Comms.kicad_pcb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]
2022-05-24 Annotate full schematic After I noticed that Tom's previous annotations did not appear on my side, I re-annotated the entire schematic. I still need to assign footprints.
    [AX5043.kicad_sch, PATempSensor.kicad_sch, SAMD21.kicad_sch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]
2022-05-24 added watchdog
    added a copy of the watchdog circuit from avionics. fixed the schematic to make me happier ;)
    [SilverSat_Comms.kicad_sch, externalwatchdog.kicad_sch]
2022-05-24 adjusted sheet sizes and formatted part numbers
    sheet sizes adjusted to A or B size depending on circuit size
    part numbers adjusted to add leading zeroes, remove units (caps so far)
    [AX5043.kicad_sch, PASwitch.kicad_sch, PATempSensor.kicad_sch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]
2022-05-24 Added footprints Based on the spreadsheet https://docs.google.com/spreadsheets/d/13zSIgHinLHY9G7Q_IfikUwdOKPlf7nDzY1Mv96xsFQY/edit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, I added the specified footprints to some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
    [AX5043.kicad_sch, PATempSensor.kicad_sch, SAMD21.kicad_sch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]
2022-05-24 Fields
    I've copied over the information in the MPN, Manufacturer Part Number and Part Number fields into each other. Ultimately, we should pick one. There are way too many redundant fields and that makes pu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
    [AX5043.kicad_sch, PATempSensor.kicad_sch, SAMD21.kicad_sch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]
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2022-05-25 Added R & C part numbers, accidental R20 edit (fixed) Total Changes - Added part numbers to capacitors 10 to 34 - Added part numbers to resistors 14 and 18 (R16 is blank because it is DNI; R17 is bla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
    [AX5043.kicad_sch, SilverSat_Comms.kicad_sch]
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2022-05-25 Fix typo
    Changed “[sic] repositorty” to “repository”
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2022-05-26 Update labels for brevity Removed units where implied Replaced Greek small latter mu's (µ) with latin small letter u because typical US keyboards lack the symbol, causing duplicate rows of similar co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
    [AX5043.kicad_sch, SilverSat_Comms.kicad_sch, serial_driver.kicad_sch]
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2022-05-28 Fixed missing capacitor value
    [AX5043.kicad_sch, SilverSat_Comms.kicad_sch]
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2022-06-02 layout update
    Moved board outline to the edgecuts layer.
    Assigned 0603 footprint to resistors. Found a few more extra spaces in part values and fixed.
    Imported footprints.
    [AX5043.kicad_sch, SAMD21.kicad_sch, SilverSat_Comms.kicad_pcb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]
2022-06-02 Fixed issues and used custom TG2016SMN TCXO
    [AX5043.kicad_sch, PASwitch.kicad_sch, PATempSensor.kicad_sch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]
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2022-06-03 network clarification
    I modified the output network on the AX5043 to show the function of the passive elements. I added a note to identify the BALUN components (high-pass/low-pass pair). This helps identify what elements should be located in proximity (and possibly orientation!) to each other. For extra credit, look up lumped element balun. This could also be replaced by a single balun part (https://www.digikey.com/catalog/en/partgroup/433mhz-balun/66692), but with possibly slightly higher insertion loss.
    [AX5043.kicad_sch, SilverSat_Comms.kicad_sch]
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2022-06-07 Undo integration
    I undid the ADD5043 integration because the resistors are too small. I will compensate by drawing my own version.
    [SilverSat_Comms.kicad_pcb]
2022-06-07 PCB fill and rearange
    # Summary of changes:
    - Began laying out AX5043 circuits
    - Moved or rearranged some circuits to make space
    - Added footprints to matching network
    - Moved OnSemi ADD5043 board to the side, for reference
    # Issues
    - Labels or parts may be too densely placed for readability
    - I may be able to remove the DNI parts, but I am awaiting review
    - Need to resolve ANTN & ANTP circuit spacing for 50Ω transmission line
    - Error loading board shape in 3D viewer “Board outline is missing or malformed. Run DRC for a full analysis.”
    [SilverSat_Comms.kicad_pcb, SilverSat_Comms.kicad_sch, pi_net.kicad_sch]
2022-06-08 Removed CAL connection on AX5043
    The CAL connection is used to calibrate an offset, which we're not planning on needing. Plus, I am seeing an odd coupling path on the dev board which is causing noise on the main VCO. The datasheet recommends grounding the GPADC lines if they're not used.
    So, I removed the connection and grounded the ADCs..
    [AX5043.kicad_sch, SilverSat_Comms.kicad_sch]
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2022-06-10 Fixed outline error
    I fixed the outline error. This was exactly the same issue as we encountered on payload, but it's an easy fix. Just move one of the endpoints to make them coincident. You know they're lined up when the cross appears in the connection.
    [SilverSat_Comms.kicad_pcb]
2022-06-10 Remove LED and add "J?" Summary of changes - Removed LEDs from schematic - Added horizontal header to attach test connections
    Issues
    - What pins will we assign for the header?
    [SilverSat_Comms.kicad_pcb, SilverSat_Comms.kicad_sch]
2022-06-10 Update AX5043 parts list & PCB Summary of changes - Replaced 0603 parts on RF lines with 0402 equivalents - Imported changes into PCB
    [AX5043.kicad_sch, SilverSat_Comms.kicad_pcb, SilverSat_Comms.kicad_sch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]
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2022-06-13 Modified eFuse designs
    modified parts values on 5V to reflect EPS limits.
    May change out 3V3 circuit (not done yet) since we now now it won't be sourcing a lot of current.
    Added bypassing to analog reference voltage
    [SAMD21.kicad_sch, SilverSat_Comms.kicad_sch, eFuse3V3.kicad_sch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]
2022-06-13 Supply modifications
    Changed out the 3.3V latch up protection for similar circuit to what's on Avionics, but changed part for higher trip point (100mA).
    Moved external USB from SAMD page to top level. USB 5V won't be able to power the PA, so we should only use that for programming the SAMD21, else just use the D+/D- lines (and +5VP for protection diodes).
    Moved blocks around to make room.
    Changed USB ID pin to be floating to avoid routing an extra line we probably don't need.
    [SAMD21.kicad_sch, SilverSat_Comms.kicad_sch, eFuse3V3.kicad_sch]
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2022-06-20 Part number fixes Summary of Changes: - Fixed C15; C25; C26; C30; C32; R14; R43; R44; & R45 fields per tconrad26's email - Copied some “Manufacturer” field values in Symbol Fields to “Manufacturer_Na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
    Not done:
    - Change 4.7pF Capacitor part Number: Capacitor not found
    [AX5043.kicad_sch, SAMD21.kicad_sch, SilverSat_Comms.kicad_sch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]
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2022-06-25 Fix Jacob's naming error
    [PASwitch.kicad_sch, PA_Switch.kicad_sch]
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2022-07-08 Imported schematic changes to PCB
    Due to reannotations, some of the PCB parts did not align with the schematic. I was able to fix this using the “Update Schematic” tool.
    [AX5043.kicad_sch, PATempSensor.kicad_sch, SAMD21.kicad_sch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]
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2022-07-08 Removed old redundant components
    There were some components in the layout which had duplicate reference designators (probably from earlier designs, Kicad doesn't delete old components that are no longer used on import).
    [AX5043.kicad_sch, PASwitch.kicad_sch, PATempSensor.kicad_sch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]
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2022-07-09 updated footprints for all parts
    Added footprints for all parts that didn't have one.
    We should check them all before sending out for fab
    [PASwitch.kicad_sch, SAMD21.kicad_sch, SilverSat_Comms.kicad_pcb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]
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2022-07-09 Revert "Update SilverSat_Comms.kicad_prl"
    This reverts commit 40cec9d6a505d4cb3e8cd7d55946c98c8312b644.
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2022-07-12 Rearrange to reflect schematic
    I am working on rearranging the PCB to reflect the schematic layout per Tom's recommendation. For now, either some parts overlap, or are not on the board. I will work on fixing them.
    [SilverSat_Comms.kicad_pcb]
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2022-07-16 Add antenna tuner & reannotate Summary of changes - Added antenna tuner network in schematic, but not in the PCB - Re-annotated the schematic - Some layout changes
    Notes on antenna tuner addition
    - I added this in case we mess up our calculations (for example,
    if we mess up our calculations and need to compensate).
    I was unable to add this to the PCB without including
    duplicate parts.
    isaac-silversat's unimplemented ideas
    - Replace TP5 footprint with label (for example, an ESD warning
    symbol).
    [AX5043.kicad_sch, PAPowerSwitch.kicad_sch, PASwitch.kicad_sch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]
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2022-07-17 Various changes
    Incomplete summary of changes:
    - Rotated PCB part layout by 0.5π radians
    - Rearranged and arranged some parts
    - Updated one schematic footprint (but not in PCB)
    - Reannotated schematic
    - Added electrical length notes to power amplifier schematic &
    PCB
    Issues to be fixed
    - Layout is not yet final; there are many ratsnest crosses
    - All parts from Texas Insturments® do not have correct footprints
    - Need to fix datasheet-sensitive layouts
    Commit notes
    - I was unable to commit using the Git command line, so I instead
    re-uploaded my entire local repository using the GitHub website.
2022-07-17 Update PCB from schematic Summary of changes: - Updated PCB from schematic, with all options on - Moved a few parts to prevent overlapping
    Issues from this commit:
    - The import may have created duplicate parts; please review and
    delete them
    [SilverSat_Comms.kicad_pcb]
2022-07-18 Replaced last PCB file with file from backup
    Replaced PCB file with the PCB from the SilverSat_Comms-2022-07-17_183010.zip archive.
    [SilverSat_Comms.kicad_pcb]
2022-07-19 Schematic and footprint fixes
    I made a schematic change to the bus labeling for the serial converters. This is far more clear than what i had before.
    Fixed the missing footprints and reloaded from the schematic
    Deleted duplicated parts
    [PATempSensor.kicad_sch, SilverSat_Comms.kicad_pcb, SilverSat_Comms.kicad_sch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]
2022-07-19 Update SilverSat_Comms.kicad_sch
    Fixed naming on hierarchical connections, should not affect the netlist
    [SilverSat_Comms.kicad_sch]
2022-07-19 Update SilverSat_Comms.kicad_sch
    Fixed signal crosses on Radio/Avionics serial port...again.
    [SilverSat_Comms.kicad_sch]
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2022-07-20 Layout work + minor schematic edits Summary of changes - Layed TI part circuits outside of the board per their datasheets - Some small PCB layout & schematic changes. - Fixed missing SN65HVD7 datashe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
    [SilverSat_Comms.kicad_pcb, SilverSat_Comms.kicad_sch, serial_driver.kicad_sch]
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2022-07-23 Fix hole issues
    Fix KiCad mixup of H3-16 and H7-H10
    [SilverSat_Comms.kicad_pcb]
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2022-07-24 File updates missed in last commit
    [PAPowerSwitch.kicad_sch, PASwitch.kicad_sch, PATempSensor.kicad_sch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]
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2022-07-24 Making progress… Major changes - Resolved “Courtyards overlap” warnings - Layout fixes
    [SAMD21.kicad_sch, SilverSat_Comms.kicad_pcb]
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2022-07-25 Small changes @tconrad26 , could you review my changes and make sure I didn't mess anything up?
    [SilverSat_Comms.kicad_pcb]
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2022-07-25 Schematic fixes and add
    Fixed error on 3V3_Protected (no 3V3_LUP anymore)
    Swapped TXD0 and TXD1, and RXD0 and RXD1 to make routing easier
    Added RF shield component to AX5043 and PASwitch sheets.
    [PASwitch.kicad_sch, SAMD21.kicad_sch, SilverSat_Comms.kicad_sch]
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2022-07-26 Layout for Tuesday review Issues - We likely need to find another switch. The datasheet says that it should not be incinerated, something that would happen during re-entry.
    [PASwitch.kicad_sch, SAMD21.kicad_sch, SilverSat_Comms.kicad_pcb]
2022-07-26 Fix typographical error on line 801
    [PASwitch.kicad_sch]
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2022-07-28 Fixed some missing top routes
    [PASwitch.kicad_sch, SilverSat_Comms.kicad_pcb]
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2022-07-29 All nets conencted Issues - The RESET line was routed on unused powar layer space. This may violate common practice design rules.
    DRC Violations
    ** Drc report for /home/isaac/KiCad/Radio_Board/SilverSat_Comms.kicad_pcb **
    ** Created on 2022-07-29 17:03:08 **
    ** Found 10 DRC violations **
    [copper_edge_clearance]: Board edge clearance violation (board setup constraints edge clearance 0.3810 mm; actual 0.0000 mm)
    Rule: board setup constraints edge; Severity: error
    @(191.0100 mm, 75.1300 mm): Line on Edge.Cuts
    @(187.9600 mm, 58.4200 mm): Pad 1 [Net-(H5-Pad1)] of H5 on B.Cu
    [copper_edge_clearance]: Board edge clearance violation (board setup constraints edge clearance 0.3810 mm; a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
    [SilverSat_Comms.kicad_pcb, SilverSat_Comms.kicad_sch]
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2022-07-29 Fixed today's DRC errors
    [SilverSat_Comms.kicad_pcb]
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2022-07-30 Fix DRC violations
    [SilverSat_Comms.kicad_pcb]
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2022-08-01 Cleanup and mess-making
    Changes:
    - Cleaned up traces
    - Changed minimum width from 5 mils to 8 mils
    - Added 100pF capacitor to TX/RX line
    - Reannotated schematic and updated PCB
    - The schematic update had changed many parts and put them out of place.
    - There are now 308 DRC violations.
    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
    [AX5043.kicad_sch, PAPowerSwitch.kicad_sch, PASwitch.kicad_sch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]
2022-08-02 Revert to “Saturday meeting changes” # Upon my last PCB import, things did not look right. The ratsnest connections seemed to have been messed up, and some footprints may have been swapped.
    In addition, I have deleted the likely unnecessary AX5043-Backups directory.
    [AX5043.kicad_sch, PAPowerSwitch.kicad_sch, PASwitch.kicad_sch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]
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2022-08-03 Various changes 3 and cleanup Issues - Upon changing the minimum trace width to 8 mils, the DRC spotted many errors. To fix these errors, the concerning areas were relocated without much consideratio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
    [AX5043.kicad_sch, SilverSat_Comms.kicad_pcb, SilverSat_Comms.kicad_sch]
2022-08-03 Add screenshot of PCB import issue
2022-08-03 A few fixes
    [SilverSat_Comms.kicad_pcb]
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2022-08-05 Fix DRC silkscreen warnings
    [SilverSat_Comms.kicad_pcb]
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2022-08-08 Beginning finishing steps
    Made a few changes:
    1. Added ground zones on bottom layer. Masked out area under PA on bottom side.
    2. Moved PA/Vout back to the bottom layer. This avoids having to modify the shield frame.
    3. Added stitching vias along RF traces. Lines pretty closely look like Coplanar waveguide with ground (about 49 ohms). Stitching might be overkill and may make soldering more difficult.
    4. As a result, had to move some of the bottom layer traces to avoid vias. Did some glossing here and there as well.
    5. Pulled back the Vin to remove unnecessary copper. Dropped min trace to 8 mils to get the thermal connections on large parts and to properly connect U12 (actually chan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
    [SilverSat_Comms.kicad_pcb]
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2022-08-13 Multiple changes
    Added series resistors and adjusted zones
    Moved J1 to be closer to the edge. This is needed because if it's not the right distance, then the cable shroud interferes.
    Added extra bypass (C17 was supposed to be for clock) where C17 used to be.
    Modified silk as needed
    Modified the ISSP connector supply to be 3V3_protected
    Modified port net on 3V3 latch up circuit to be 3V3_P to try to avoid confusing net names
    [AX5043.kicad_sch, PASwitch.kicad_sch, SAMD21.kicad_sch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]
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2022-08-13 3D models
    Added missing 3D models.
    [SilverSat_Comms.kicad_pcb]
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2022-08-13 Shortened path to C21
    Shortened length to C21 and its ground connection
    Adjusted silk in RF area to 30/30/5
    [SilverSat_Comms.kicad_pcb]
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2022-08-13 Revert "Updated 3d model locations"
    This reverts commit 0f5800f6ad3e3498aff166fb09838c703b4b80c4.
    [SilverSat_Comms.kicad_pcb, SilverSat_Comms.kicad_sch]
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2022-08-14 Steps to try adding new 3D models Re-updated footprints, moved SilverSat logo, and deleted edge cut on SMA conenctor
    3D models, added by tconrad26, are still not showing on my side despite a library
    and footprint update.
    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
    [SilverSat_Comms.kicad_pcb]
2022-08-14 fixed DRC errors
    Looks like a recent part import overwrote the local footprint changes.
    I updated the Silversat Kicad library to fix the HMC452, so make sure to update
    U6 hole size is modified local (not in library). Both parts are locked now and shouldn't update without a warning. Other DRC issues resolved.
    [SilverSat_Comms.kicad_pcb]
2022-08-14 cleanup
    Removed some spare traces on power plane and text that no longer applies
    [SilverSat_Comms.kicad_pcb]
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2022-08-14 usb connector 3d body
    forgot to add this one, so it's fixed now too.
    [SilverSat_Comms.kicad_pcb]
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2022-08-17 updated voltage on cap
    Added voltage rating to C1. Probably should be higher but would require a significantly larger package. A failure of this part wouldn't cause any other issues because it's nominally connected to ground anyway and the shield is generally disconnected.
    [SilverSat_Comms.kicad_sch]
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2022-08-17 Updated bus header
    Modified bus header part number to reflect that we are now using a straight header versus a passthrough header. Selected part for correct pin length (or at least the best we can get in stock)
    [SilverSat_Comms.kicad_pcb, SilverSat_Comms.kicad_sch]
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2022-08-18 Modified field values
    Updated field values for a bunch of parts to either correct them (some part numbers were wrong) or to populate an otherwise empty field (like copying over a part number to MPN)
    [AX5043.kicad_sch, PAPowerSwitch.kicad_sch, PASwitch.kicad_sch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]
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2022-08-19 BOM updates
    Sourced the majority of the parts. Only missing the watchdog chip and LED.
    Use HTMLBOM.xlsx for the BOM. The HTML BOM should also reflect this list.
    I believe that these are in sync with the design files at this point.
    [AX5043.kicad_sch, HTMLBOM.xlsx, PASwitch.kicad_sch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]
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2022-08-24 Update Blender model materials Updated solder resist and exposed pad properties from Adafruit Metro to OshPark Prototype Service Increased render samples to 2²⁴ to reduce image noise without denoisin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
2022-08-24 Blender 3D B Solder Resist material fix
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2022-08-24 Attempt to recreate Kicad BG Changes Attempt to use Blender Compositor to recreate the KiCad 3D Vewer's background Issues This background is rotated 180 degrees despite my attempts to use rotation no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
2022-08-26 Add Arduino-format Radio Board definitions Add modified Arduino® SAMD board package, which has only an Arduino MKR WiFi 1010 board with tconrad26's modified pin definitions which has been renamed to 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
    See Arduino_Board_Definitions/INSTALL.md for details.
    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
    [arduino_zero.cfg]
2022-09-01 Update board definition files Updated Arduino pacakge index file and associated INSTALL.md
    A ZIP archive, required by Arduino's Board Manager, was added, but was not added under .gitignore. It seems unclear whether the file should be added.
    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
2022-10-27 Added Metro & Zero pinouts, corrected tables
    Added the Metro and Zero pinouts and corrected the tables in the schematic
    [SAMD21.kicad_sch]
2022-10-28 Update SAMD21.kicad_sch
    Various notes inserted. I have a concern that we might need hardware flow control on the data serial port. We might be able to use software flow control, or some other out of band method if it turns out that TCP overflows the input buffer, and doesn't cleanly back off. We also might consider looking for ways to tweak TCP like limiting the max Frame size and Window. The current buffer size on the data port is only 8k, but thats still smaller than a typical TCP frame. (or so i think ;)
    [SAMD21.kicad_sch]
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2023-02-24 Conciseness in board description
    TODO: Possible expansion.
    Contributors: If there is any information you feel is missing from this, send me an email about it.
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2024-02-20 Fix attenuator; update to KiCad 7; update README
    [AX5043.kicad_sch, PAPowerSwitch.kicad_sch, PASwitch.kicad_sch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]
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2024-02-27 Fix some duplicates
    [AX5043.kicad_sch, SAMD21.kicad_sch, SilverSat_Comms.kicad_pcb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]
2024-02-27 Changed X1 to 3.3V drop-in replacement
    Changed TG2016SMN 48.0000M-ECGNNM0 to TG2016SMN 48.0000M-MCGNNM0
    [AX5043.kicad_sch]
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2024-03-17 Fix one or two DRC violations
    [SilverSat_Comms.kicad_pcb]
2024-03-17 Fixed H2 pinout
    Changed H2 pinout to match new definition. Updated PCB to match. No copper changes to PCB, just nets.
    [SilverSat_Comms.kicad_pcb, SilverSat_Comms.kicad_sch]
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2024-04-20 Replace radio board outline with Avionics outlinl
    [SilverSat_Comms.kicad_pcb]
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2024-04-20 Update U4 hole size
    The via hole size in U6 was too small for OshPark. The diameter was changed from 0.2000 mm to 0.2540 mm. There are now annular width errors, but the margin is now four micrometers which is insignificant.
    [SilverSat_Comms.kicad_pcb]
2024-04-20 Change datasheet variable errors to warnings
    [SilverSat_Comms.kicad_pcb]
2024-04-22 Fix DRC warnings and zone clearence
    [SilverSat_Comms.kicad_pcb]
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2024-04-22 Add J1 model; J4 model is missing from library
    [SilverSat_Comms.kicad_pcb]
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2024-04-27 Master BOM Parity Check 1
    Parity Error: The Radio BOM uses ESQ-126-69-G-D, but the Master BOM lists ESQ-126-69-G-S.
    [SilverSat_Comms.kicad_sch]
2024-04-27 Fix last parity error
    The Master BOM had an error; this was fixed with this commit.
    [SilverSat_Comms.kicad_sch]
2024-04-27 Parity error fix 0
    There was a parity error on ATSAMD21G18-A. The Master BOM lists *-AF, but SilverSat has already ordered *.MF.
    [SAMD21.kicad_sch]
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2024-05-04 Fix text size
    [SilverSat_Comms.kicad_pcb]
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2024-05-18 Fixed BOM mismatch (MPN differed from Mouser(R) link)
    [SilverSat_Comms.kicad_sch]
2024-05-18 Revert nickel-silver RF shields to stainless steel
    [AX5043.kicad_sch, PASwitch.kicad_sch]
2024-05-18 Revert "Revert nickel-silver RF shields to stainless steel"
    This reverts commit f61145615cb9888b912f67adff0717416210a944.
    [AX5043.kicad_sch, PASwitch.kicad_sch]
2024-05-18 Fix part error: MS353 changed to MS355
    [AX5043.kicad_sch, PAPowerSwitch.kicad_sch, PASwitch.kicad_sch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]
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2024-06-05 Larger pads
    Increased size of C40, C64, C65 based on recommendation from Jacobs.
    Fixed a DRC error around J1.
    Added a ground pad to allow a scope ground to be attached.
    Fixed some silk errors.
    [AX5043.kicad_sch, PAPowerSwitch.kicad_sch, PASwitch.kicad_sch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]
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
